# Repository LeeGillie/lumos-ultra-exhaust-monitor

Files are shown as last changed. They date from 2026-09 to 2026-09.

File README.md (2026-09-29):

# Lumos Ultra Exhaust Monitor (LumosAir)

Cheap, fully local airflow monitoring for a laser-engraver exhaust. Two identical boxes â€” an ESP32 running MicroPython, pressure sensors and a 2" colour display â€” feed a Windows app. The app shows live CFM and duct air speeds, sets or recommends the fan level, and diagnoses problems:

- a clogged or kinked duct
- leaking joints
- a leaking dust bin
- a clogged pitot tube
- a blocked outside vent
- a laser enclosure that isn't under enough suction

It was built for a **WeCreat Lumos Ultra** (fiber/UV) venting through an **AC Infinity CLOUDLINE S6**. Everything, including the duct path, fan curve and sensor map, is set in a JSON file, so it adapts to other lasers and fans.

The exhaust run itself is ordinary 4" and 6" **flexible** duct and stays that way. The one exception is a 5 ft **rigid 4" measuring spool** holding a Dwyer 166-6-CF pitot-static probe: flex duct has corrugations, a vague inside diameter and a centreline that shifts when the hose moves, so the flow measurement everything else is checked against gets one stable, known-geometry station. [DESIGN.md Â§2â€“3](docs/DESIGN.md) covers the spool, the probe and the traverse.

**▶ Watch the 2-minute intro on YouTube:**

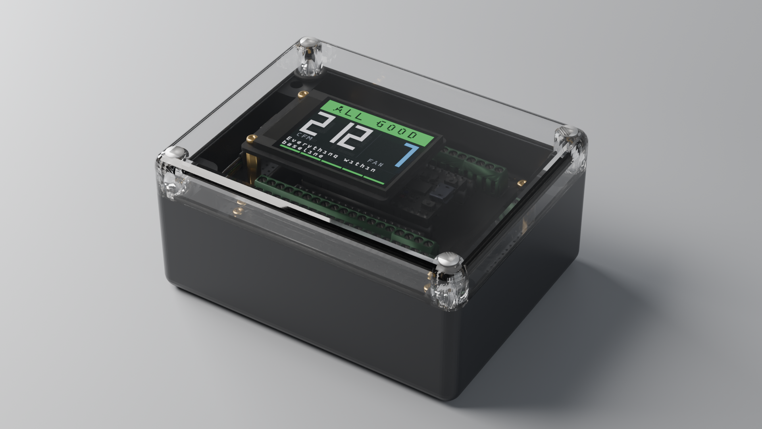
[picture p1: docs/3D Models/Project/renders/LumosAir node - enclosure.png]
LumosAir intro video - click to play on YouTube (https://youtu.be/tQAgUggGCig)


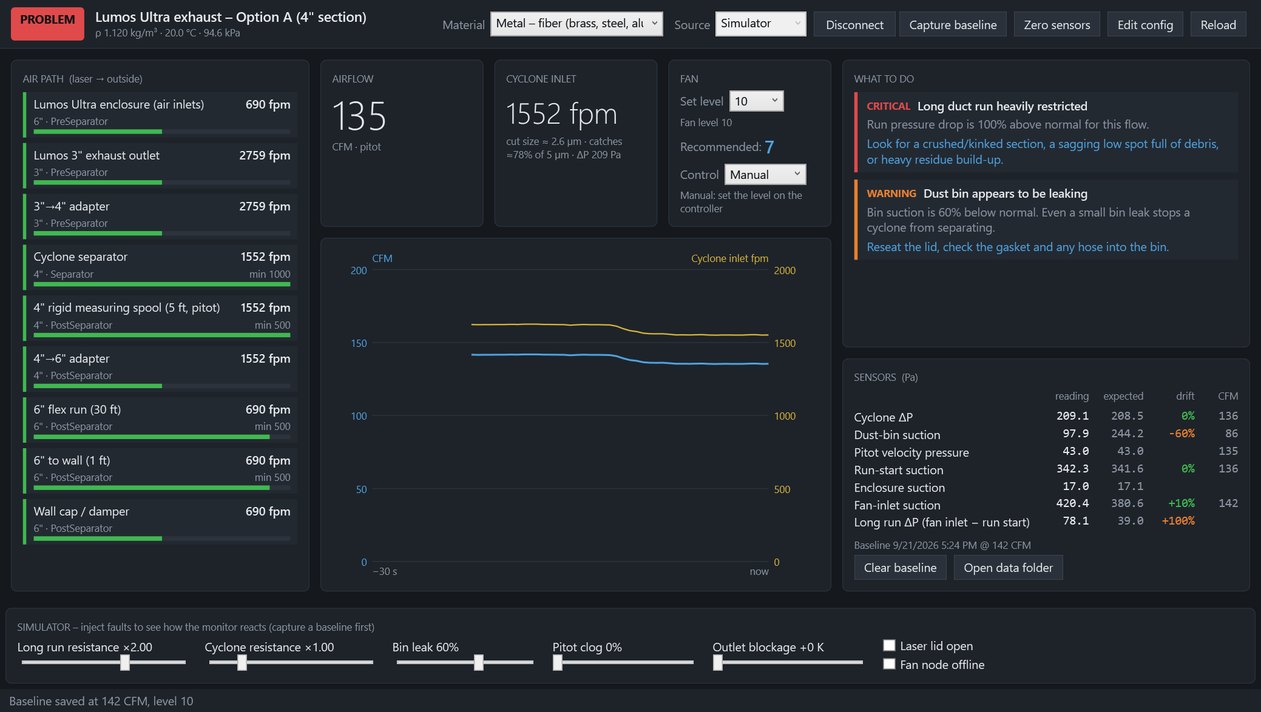
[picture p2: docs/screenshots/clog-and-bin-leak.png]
LumosAir detecting a clogged duct run and a leaking dust bin


---

## Why this is being built *before* the cyclone separator

Deep brass engraving produces real, heavy metal particulate, not just smoke. A temporary 35 ft exhaust hose came out with a pile of brass in it. The plan is to put a **cyclone separator right at the laser outlet** so the brass drops into a sealed drum before it reaches the long duct and the fan.

Cyclones are finicky. They only separate well within a band of airflow, and they use up a lot of the fan's pressure. Choosing one without measuring is guesswork. **The monitor comes first because it answers the questions that decide which separator to buy.**

1. **How much air does the existing system really move?**
   - The S6 is rated 425 CFM, but that is with nothing attached.
   - With the Lumos outlet, adapters, 30 ft of flex and a wall cap, the real figure is much lower.
   - The monitor measures it at every fan level.
2. **Can the fan drive a given cyclone?**
   - The popular 3" steel Dust Deputy needs at least 200 CFM. The physics model estimates that would take roughly 3.4â€“9 inWC across the cyclone alone.
   - The S6 makes about 2 inWC with no airflow at all. The model predicts only 80â€“120 CFM with that cyclone.
   - Once the real fan curve is measured, `lumosair model` gives a measured-model answer for any candidate cyclone before you spend ~$400. See [DESIGN.md Â§1](docs/DESIGN.md#1-key-findings-read-this-first).
3. **Is brass settling in the duct right now?**
   - Air speed in each section is compared with the speed needed to keep metal particles airborne (~3,500 fpm).
   - Modelled as it stands today (`lumosair init --option C`), the system moves about 200 CFM at level 10: ~2,300 fpm in the 4" section and ~1,020 fpm in the 6" run. Both are below what brass needs, so the duct is currently acting as the separator â€” which matches the brass found in the old hose.
   - No fan level fixes that, which is the argument for a separator at the laser rather than more fan speed.
4. **Once a separator is installed, is it working?**
   - The monitor tracks cyclone pressure drop, dust-bin suction (a leaking bin stops separation), inlet velocity and estimated cut size.
   - It compares them all against a "known good" baseline.

In short: **measure first, then size the separator to the air you actually have**, and keep the same sensors in place to watch it afterwards.

---

## Screenshots

These come from the built-in simulator (`LumosAir.exe --selftest out.png --scenario <name>`), so you can explore the app before any hardware exists.

**The system as it stands today (Option C, no separator).** Every duct is on the dirty side, and none of them is fast enough to carry brass â€” no fan level fixes it, which is the case for a separator at the laser:

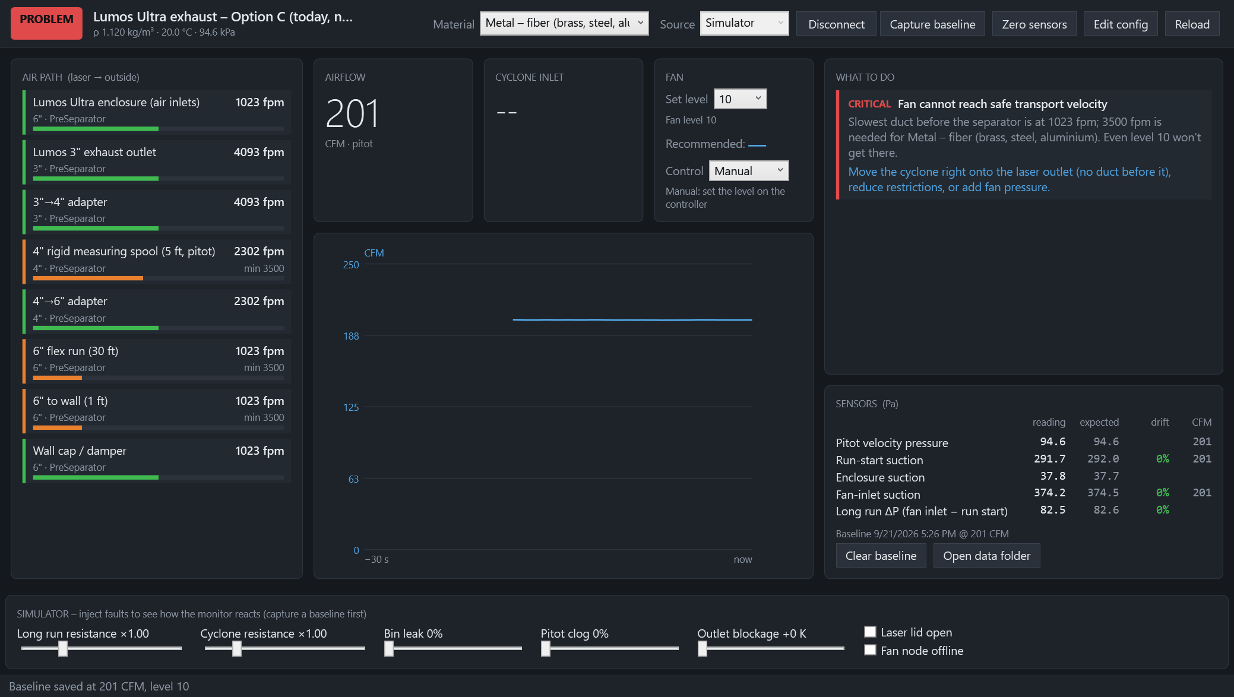
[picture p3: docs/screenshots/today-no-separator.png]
Today, no separator


| Healthy system (Option A, with a separator) | Fan turned down too far |
|---|---|
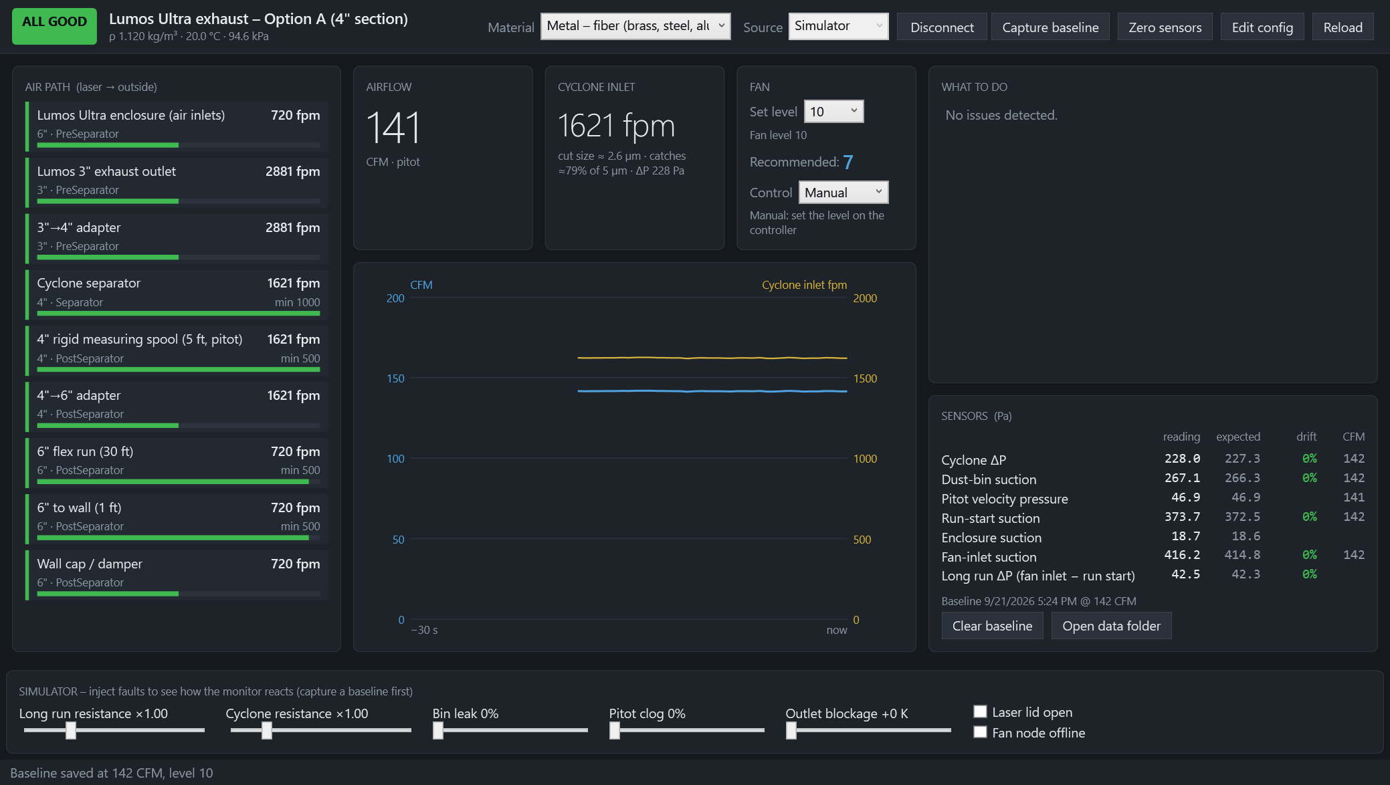
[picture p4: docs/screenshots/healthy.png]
healthy
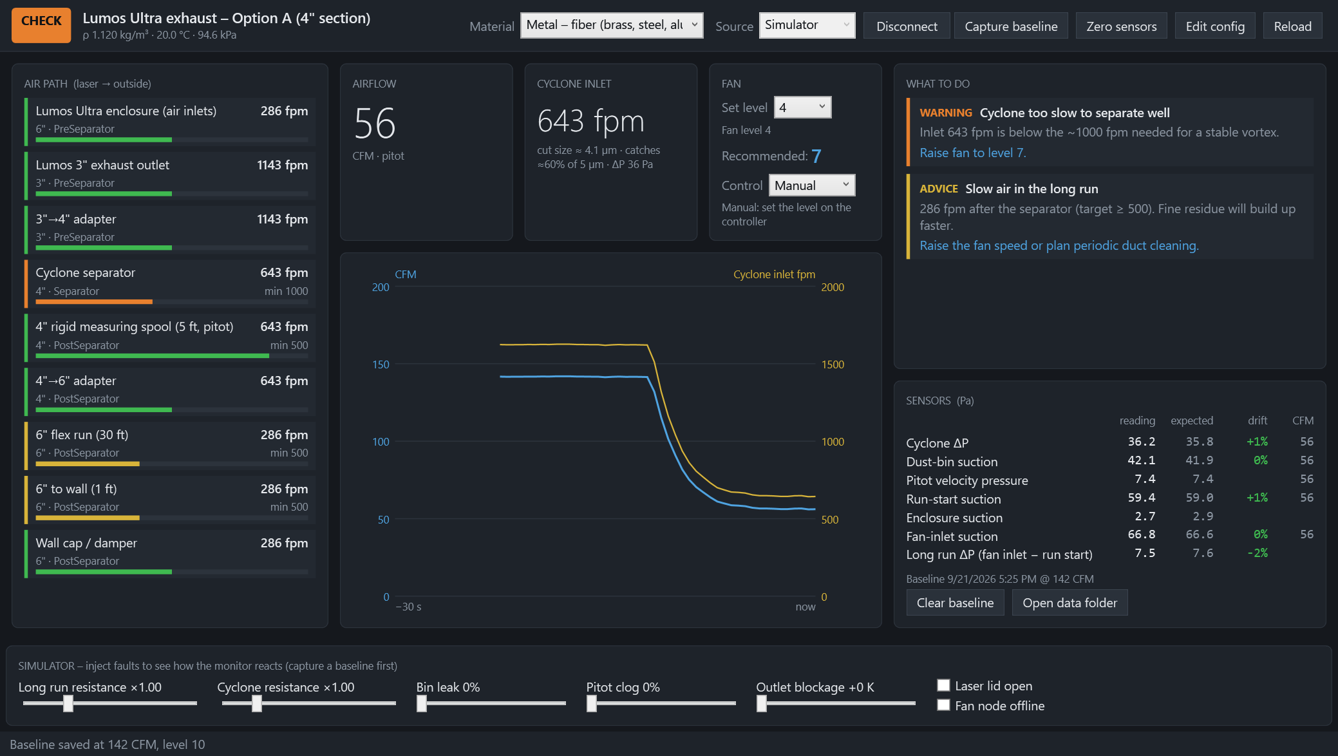
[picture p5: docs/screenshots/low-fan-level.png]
low fan
|  |  |
| **Clogged pitot tube** (app switches to the other sensors) | **Blocked outside vent / damper** |
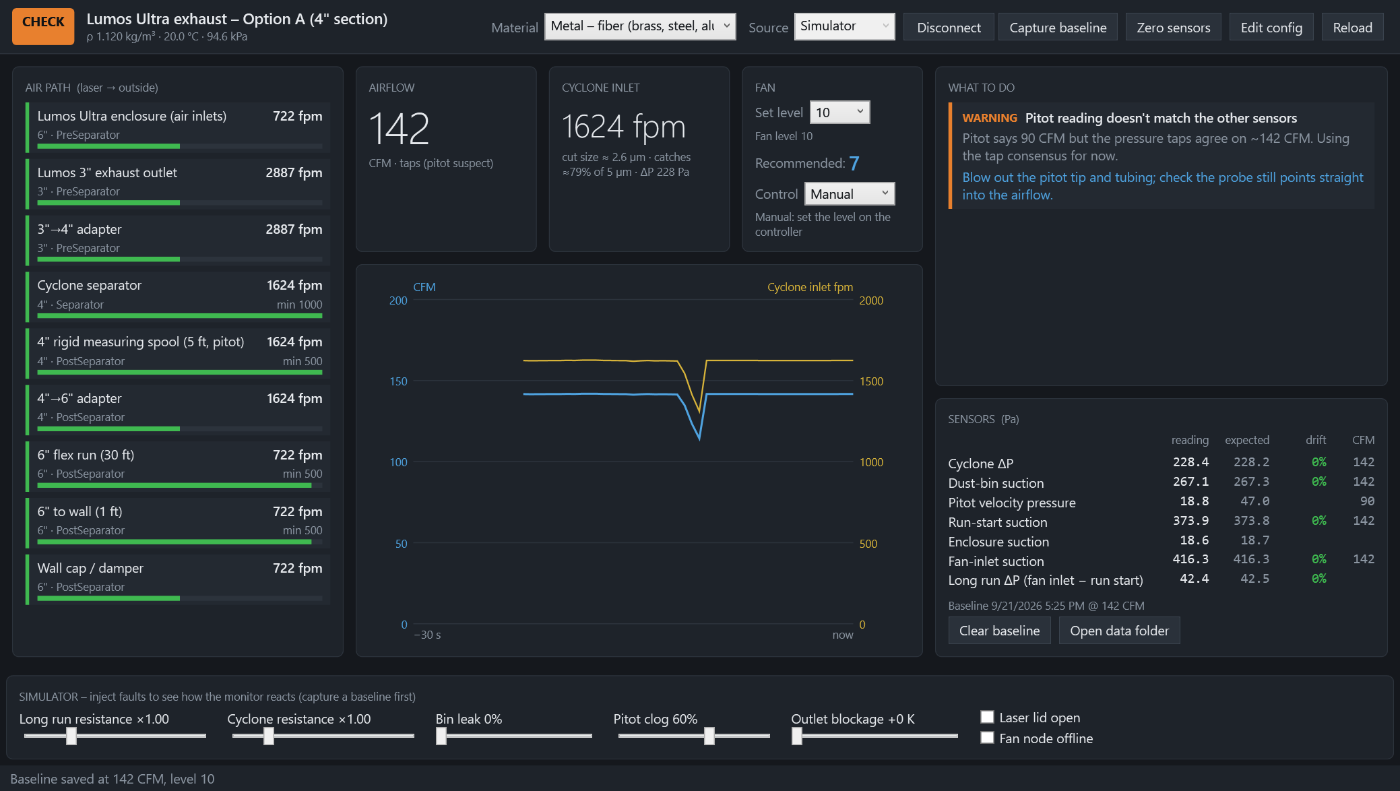
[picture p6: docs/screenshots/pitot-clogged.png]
pitot
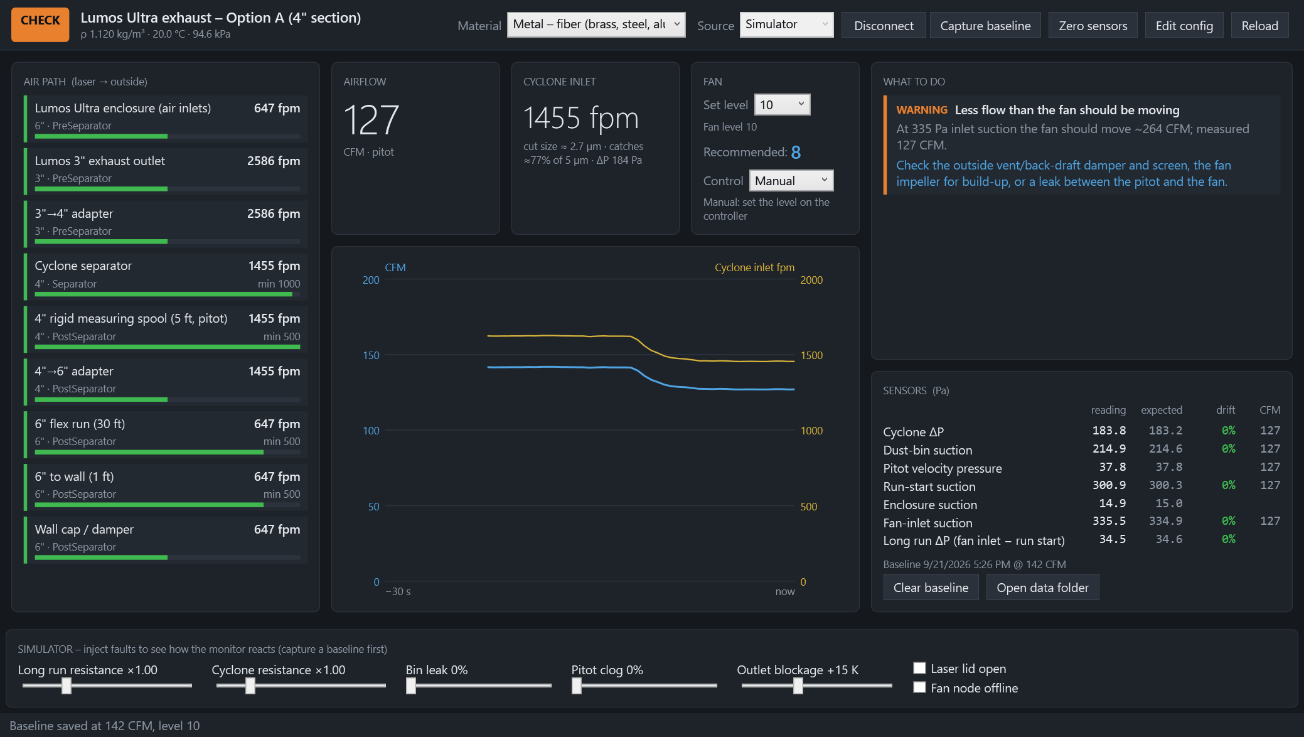
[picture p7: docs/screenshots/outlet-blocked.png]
outlet
|  |  |

System layout and sensor taps:

System diagram

---

## Cost per sensor unit

Approximate prices as of September 2026; check before ordering. The full list, with
sourcing, part numbers, dimensions and datasheet links, is in
[`docs/BOM.xlsx`](docs/BOM.xlsx).

### Per measurement channel

| Channel type | Parts | Approx. cost |
|---|---|---|
| **Precision differential channel** (cyclone Î”P, enclosure) | Sensirion SDP810-500Pa + tubing + 2 wall taps | **$38â€“55** |
| **Pitot flow channel** (CFM) | SDP810-500Pa + Dwyer 166-6-CF pitot-static probe + 1/8" FNPT boss + tubing/adapters | **$210â€“295** |
| **High-suction static channel** (bin, run start, fan inlet) | CFSensor XGZP6897D Â±1 kPa + tubing + wall tap | **$11â€“18** |
| Air-density channel (optional) | BME280 breakout | $5â€“10 |
| **Box** (either node) | Hammond 1554F2GYCL + 2.0" ST7789 display + 8 bulkheads + elbows + button + gland + PCB-A/PCB-B + standoffs | **$90â€“125** |

### Per node

| Node | Contents | Approx. cost |
|---|---|---|
| **Laser node** | ESP32, TCA9548A mux, BME280, 3Ã— SDP810, 2Ã— XGZP6897D, Dwyer pitot + boss, tubing, taps, box + display | **$415â€“580** |
| **Fan node** | ESP32, 1Ã— XGZP6897D, tap, box + display | **$110â€“155** |
| **Complete system** (excluding the separator) | both nodes + the 5 ft rigid 4" measuring spool | **â‰ˆ $550â€“750** |
| **Measure-first starter kit** | fan node + an ESP32 with only the pitot channel and the rigid spool | **â‰ˆ $385â€“500** |

The Dwyer 166-6-CF pitot ($160â€“220 new) is most of the difference. It earns its place: its ASHRAE tip needs no calibration (coefficient 1.000), and at 1/8" it is one of the few probes Dwyer rates for a duct as small as 4". A generic probe is cheaper but has an unknown coefficient, so it has to be calibrated against something else.

---

## The boxes

Both nodes are the **same box, built the same** â€” a Hammond 1554F2GYCL, 120 Ã— 90 Ã—
60.5 mm with a clear lid, the same two boards and the same sensors in each. Only
what you connect outside differs, and each box plugs the bulkheads its location
doesn't use, so either box can serve either position.

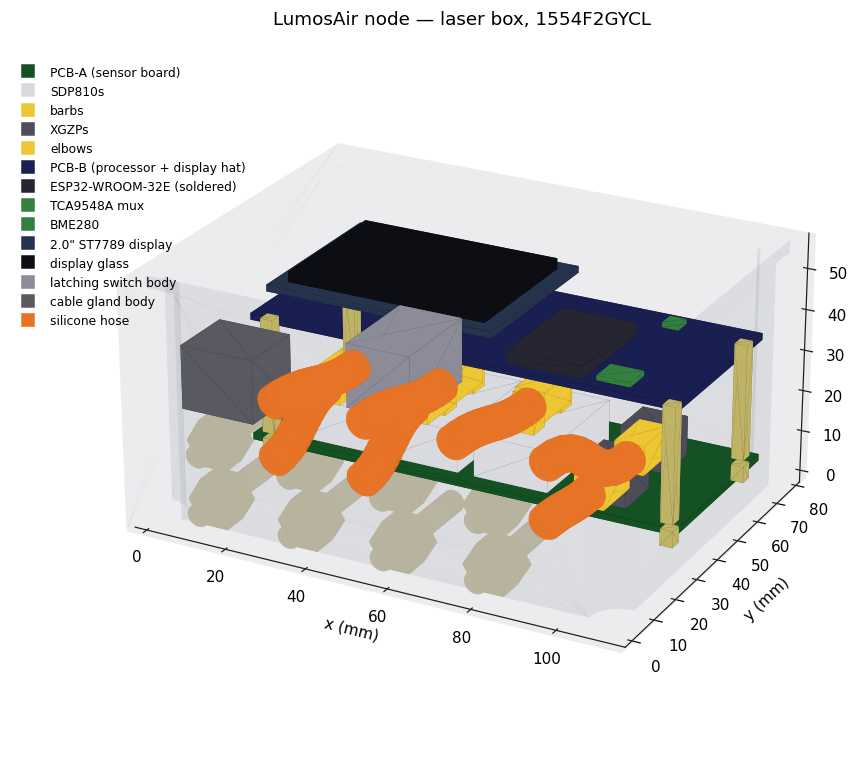
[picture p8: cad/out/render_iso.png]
Enclosure fitment


Inside, it's two boards. **PCB-A** screws to the floor and carries everything that
needs a hose â€” three SDP810s and two XGZP6897Ds, all with their ports facing up.
Spacers carry **PCB-B** above the hose runs with the ESP32, the multiplexer and the
display, which reads up through the clear lid, so there is no cut-out and the box
stays sealed against the dust it's there to monitor.

The eight hoses are modelled as real tubing, because they are what sets the size of
the box. Each SDP810 is turned 90Â° so its barbs line up behind one column of ports,
and a push-on 90Â° elbow turns each hose to point at the wall â€” from there it's a
20â€“45 mm run with a 13 mm minimum bend radius.

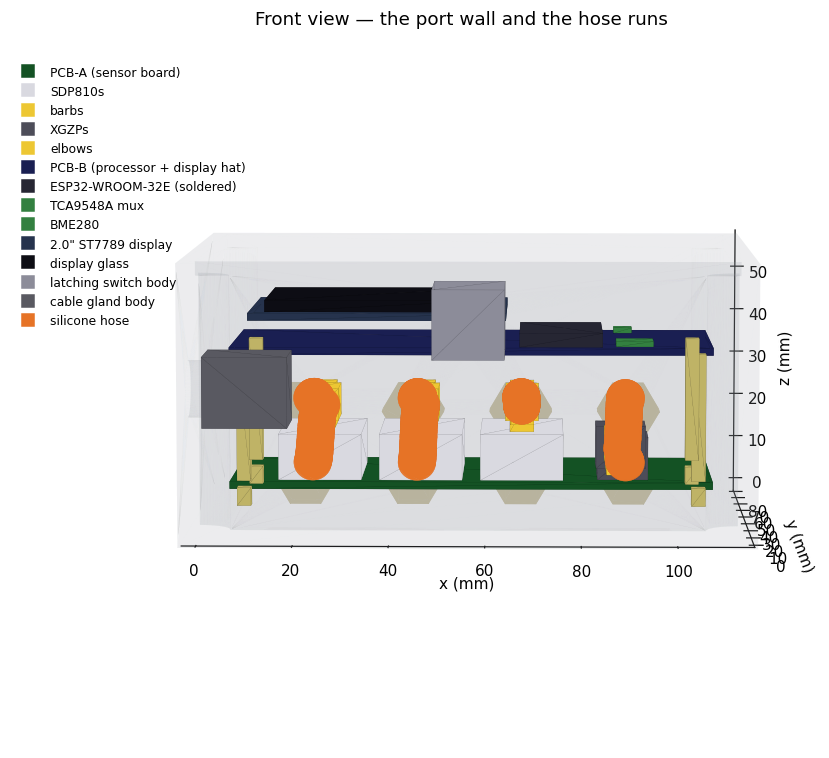
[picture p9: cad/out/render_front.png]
Hose runs


Without those elbows a hose leaves the barb pointing straight up and has to climb a
full bend radius before it can enter a wall port, which adds 25 mm to the box.
`python cad/enclosure.py --compare` prints the case both ways.

A Ã˜12 mm illuminated latching button sits on the same front panel: power switch and
power-on indicator in one hole. The panel artwork, the 1:1 drill template and the
KiCad board outlines all come out of the same script, so a moved port moves its
hole, its label and its PCB mounting hole together â€” see [`cad/`](cad/).

Front panel artwork

The box screen shows the status colour, system CFM, fan level and mode, the top
finding, and every channel on that node â€” and keeps showing live pressures if the PC
app isn't running.

## Fan control: automatic or manual

The app's fan card has a **Control** selector:

- **Manual** â€” it recommends a level and you set the dial; nothing is ever sent.
- **Auto** â€” it sends the level to the fan node. Raising speed happens immediately
  (and a critical finding pins the fan at maximum); easing back only happens after
  the lower recommendation has held for the dwell time, so the fan doesn't hunt.

The fan node's output pin stays disabled until you verify the CLOUDLINE UIS pinout
yourself â€” until then Auto still works as an advisory, on screen and on the box.

## Repository layout

```
cad/         parametric enclosure model (CadQuery): fitment, hose routing,
             panel artwork, KiCad board outlines, STEP/STL/renders
docs/        DESIGN.md (start here), BOM.xlsx, system diagram, screenshots, model output
firmware/micropython/   ESP32 node firmware: sensors, display, Wi-Fi, OTA
app/
  src/LumosAir.Core      physics model, diagnostics, UDP / MQTT / simulator (no NuGet dependencies)
  src/LumosAir.Desktop   WPF monitor app
  src/LumosAir.Cli       `lumosair` CLI: model / simulate / listen
  tests/LumosAir.Tests   dependency-free test runner (41 tests)
  config/                sample system.json (Option A / B, and C = today's system)
```

## Desktop app (Windows, .NET 9)

```powershell
cd app
dotnet run --project src/LumosAir.Desktop                       # the monitor
dotnet run --project tests/LumosAir.Tests                       # tests
dotnet run --project src/LumosAir.Cli -- model --option C        # the system as it is today
dotnet run --project src/LumosAir.Cli -- model --need-cfm 200   # "can my fan do this?"
```

- **First run:** the app writes `%APPDATA%\LumosAir\system.json`. Use **Edit config**, then **Reload**. Start it with `--config path\to\system.json` to use a different one (e.g. `app/config/system.optionC.json`).
- **No hardware yet:** set **Source** to **Simulator**, click **Connect**, then **Capture baseline**, and use the sliders to inject faults.
- **Real nodes:** use **Udp** (no setup needed) or **Mqtt** (e.g. the Home Assistant Mosquitto add-on). Set **Set level** to match the fan controller.
- **Logs:** a CSV row is written to `%APPDATA%\LumosAir\` every 5 s.
- **Other SDKs:** add `-p:AppTfm=net8.0` or `-p:AppTfm=net10.0`.

## Firmware (MicroPython on ESP32)

Developed in VS Code with the MicroPico extension â€” full details in
[`firmware/micropython/README.md`](firmware/micropython/README.md).

1. Flash MicroPython once over USB (`esptool`).
2. Copy `config_example.py` to `config.py`: Wi-Fi, node id, channel map, pins.
3. Upload with MicroPico or `mpremote fs cp -r lib : && mpremote fs cp main.py config.py :`.

After that the boxes update over Wi-Fi â€” no cable, no taking them off the duct:

```
python tools/serve_update.py               # on the PC
python tools/send_command.py laser update  # or the app
```

The node fetches a manifest, downloads only the files whose SHA-256 changed, and
reboots. It reads the sensors through a TCA9548A multiplexer, publishes JSON over
UDP and/or MQTT, drives the display, and accepts `zero`, `clear_zero`, `set_level`,
`info`, `update` and `reboot`.

Host tests (no hardware needed): `python firmware/micropython/tests/test_firmware.py` â€” 31 checks.

### Telemetry format

UDP port 47810, or MQTT topic `lumosair/<node>/telemetry`:

```json
{"node":"laser","seq":12,"up":3456,"rssi":-61,
 "ch":{"cyc_dp":{"pa":212.4,"t":24.1,"ok":true},"pitot":{"pa":46.8,"t":24.0,"ok":true}},
 "env":{"t":23.9,"rh":41.0,"p":94412}}
```

Commands go to UDP port 47811 or `lumosair/<node>/cmd`, e.g. `{"cmd":"zero"}`.

## Status

- **Working and tested:** the physics model, the diagnostics (all 9 simulated faults detected, no false alarms), automatic fan control, the desktop app and the CLI. 41 app tests plus 31 firmware tests, all on the PC.
- **Firmware:** MicroPython, driver maths and payloads unit-tested on the PC, not yet run on hardware.
- **Fan output pin:** disabled until the CLOUDLINE UIS pinout is verified; Auto mode is advisory until then.
- **Needs calibration:** the fan curve, cyclone loss coefficient and pitot profile factor are estimates until they are measured on the real system. [DESIGN.md Â§6](docs/DESIGN.md#6-commissioning) walks through calibrating them.

## Safety note

Brass dust contains copper and zinc. Don't blow accumulated dust out of ducts with compressed air. Keep the dirty side of the system short, smooth, metal and grounded. This project monitors airflow; it is not a certified safety device.

## License

MIT. See [LICENSE](LICENSE).

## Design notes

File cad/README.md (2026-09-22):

# Enclosure fitment model

Both nodes use the **same box, built the same** — same eight bulkheads, same two
boards, same sensors. Each just plugs the ports its location doesn't use. The model
is a script, so moving a part is a one-line change and the drawings, the STEP file,
the panel artwork, the PCB outlines and the clearance report all follow.

```
pip install cadquery matplotlib
python cad/enclosure.py                     # STEP + STL + fitment report (picks the box)
python cad/enclosure.py --populate fan      # the fan box's population
python cad/enclosure.py --compare           # which box fits, and why
python cad/artwork.py                       # 1:1 panel artwork + KiCad board outlines
python cad/render.py                        # shaded PNGs for the docs
```

Everything lands in `cad/out/`:

| File | What it's for |
|---|---|
| `lumosair_laser_F_module.step` / `.stl` | open in FreeCAD / Fusion / Blender |
| `render_iso.png`, `render_top.png`, `render_front.png`, `render_side.png` | the pictures in the docs |
| `panel_front_laser.svg`, `panel_front_fan.svg` | 1:1 laser-marking artwork for the port face |
| `panel_end.svg` | the end wall (cable gland) |
| `drill_template_front.svg` | 1:1 hole pattern with crosshairs |
| `pcb_a_outline.dxf`, `pcb_b_outline.dxf` | board edge + M3 mounting holes, for KiCad |
| `fitment_report_laser.txt` | part positions, hose lengths, bend radii, clearances, collisions |

Isometric

## The box

Hammond **1554F2GYCL**: 120 × 90 × 60.5 mm outside, ~113 × 79 × 54.5 inside, 3 mm
walls, **clear polycarbonate lid**. The clear lid is why the display needs no
cut-out — it sits on standoffs facing up and reads through the lid, which keeps the
box sealed.

Only the 1554H has a confirmed drawing in `docs/datasheets/`; the others use the
same wall and flange offsets, so treat their insides as ±1 mm and check before you
drill.

## The stack

```
floor ── 4 mm standoffs ── PCB-A   every part that needs a hose, ports facing UP
                             │     hose zone: eight silicone runs, 6 → 31 mm
      ── 28 mm spacers ──── PCB-B   ESP32 + mux + BME280
                             │
      ── 6 mm standoffs ─── display reading up through the clear lid
                                    ~9 mm spare under the lid
```

| Board | Size | Carries |
|---|---|---|
| PCB-A | 105 × 41 mm | 3 × SDP810 (turned 90°), 2 × XGZP6897D soldered direct |
| PCB-B | 105 × 41 mm | ESP32-WROOM-32E, TCA9548A, BME280, the display on standoffs |

Both boards share an outline and a mounting pattern, so the spacers are one straight
vertical stack — see the two DXFs.

## How the hoses connect

Each SDP810 is turned 90° so its two barbs line up behind one column of bulkheads. A
**push-on 90° barbed elbow** on each barb turns the hose to point at the wall, and
from there it's a short, nearly straight run to its bulkhead.

That elbow is what makes the small box possible. `--compare`:

| fittings | tallest item | headroom in the 1554F | tightest bend |
|---|---|---|---|
| 90° elbows | 51.5 mm | 3.0 mm | 13.1 mm — fits |
| straight onto the barb | 65.1 mm | −10.6 mm | 3.3 mm — kinks |

A hose leaving a barb straight up has to climb a full bend radius before it can turn
into a wall port, which pushes the ports 25 mm higher and the lid with them.

Which sensor gets which hole is chosen by the model, not fixed: it tries every
assignment and keeps the one with the least sideways and vertical offset. The
labels follow, which is why the panel artwork is generated rather than drawn.

Front view

## Port assignments

Eight Ø8 mm holes, two rows of four, 22 mm pitch, rows at z = 13 and 27 mm.

| Column | Lower row | Upper row |
|---|---|---|
| 1 | CYC + | CYC − |
| 2 | PITOT T | PITOT S |
| 3 | VENT | ENCL |
| 4 | BIN | RUN |

Both boxes are drilled and populated identically; each plugs the bulkheads its
location doesn't use. A node works out which it is from what's connected outside —
see [DESIGN.md §6a](../docs/DESIGN.md).

**VENT** is an open port that keeps the box interior at room pressure. That's the
reference side for the bin, run and enclosure channels, so each of those needs only
one hose.

A Ø12 mm illuminated latching push button sits centred on the same panel above the
hoses — power switch and power-on indicator in one hole. The Ø12.5 mm cable gland
is in the left end wall.

## Marking and drilling

`artwork.py` writes 1:1 SVG at true millimetre scale. Red (`#ff0000`) is
cut/drill, black is engrave; most laser software maps colour to operation.

Panel

`drill_template_front.svg` is the same holes with crosshairs and a 100 mm check bar
— print it, check the bar, tape it on, centre-punch.

## Checking a change

`fitment_report_laser.txt` lists every part's extent, the headroom, each hose's
length and bend radius, and any collisions. `enclosure.py` exits non-zero when
something doesn't fit, so it can sit in a build script.

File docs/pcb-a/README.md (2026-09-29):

# PCB-A — the sensor board

Everything that needs a hose, plus the I²C mux, the air sensor and the fan interface,
on one board under the ESP32. Drawn to be entered in Proteus (or any EDA tool).

- **[pcb_a_schematic.svg](pcb_a_schematic.svg)** — the schematic, net-label style: pins
  with the same net name are connected.
- **[pcb_a_netlist.md](pcb_a_netlist.md)** — every net and every pin, for checking the
  layout against.

Both are generated by [`cad/schematic.py`](../../cad/schematic.py) from one parts table,
so they can't disagree. Change the table and re-run it rather than editing either file.

PCB-A schematic

## Blocks

| Block | Parts | What it does |
|---|---|---|
| Link to the ESP32 | J2 (8-pin) | +5V, GND, 3V3, SDA (GPIO21), SCL (GPIO22), FAN_SENSE (GPIO33), FAN_CTRL (GPIO25) |
| I²C mux | U6 TCA9548A breakout, C3 | The pressure sensors share addresses (SDP810 = 0x25, XGZP = 0x6D), so each gets its own channel. A0–A2 low = 0x70. |
| Pressure | U1–U3 SDP810, U4–U5 XGZP6897D, R10–R19, C4–C8 | One sensor per channel, pull-ups per channel, 100 nF at every sensor. |
| Air | U7 GY-BME280 | On the main bus (0x76), not behind the mux. Density correction for CFM. |
| XGZP supply | JP1 | See below — the one thing to set when the sensors arrive. |
| Fan sense | J3, R1, D2, OK1, R2, C9 | The fan lead's own rail lights OK1, which pulls FAN_SENSE low: "this is the fan box" (DESIGN 6a, step 1). Fully isolated. |
| Fan control | R3, OK2 — **do not fit** | Footprints only, until the UIS pinout and signalling are verified. `FAN_OUTPUT_ENABLED` stays False. |
| 5 V input | J1, F1, D1, C1 | Only if power comes in on the 2-wire USB-C socket rather than through the ESP32 board's own USB port. The TVS clamps and the PTC trips if the 10 V fan lead is ever plugged into the power socket. |

## Channel map — identical on both boxes

> **Rev B (milled copper-clad board, Sept 2026) changes this map** to make the single-sided routing work: ch0 pitot, ch1 run_in (fan box: fan_in), ch2 bin, ch3 cyc_dp, ch4 encl. The XGZPs also run from 3.3 V (JP1 removed) and have port 2 on the hose (sign -1). See [cnc/README_CNC.md](cnc/README_CNC.md). The table below is the original rev A map.

| Mux ch | Part | Laser box | Fan box |
|---|---|---|---|
| 0 | U1 SDP810 | `cyc_dp` | — |
| 1 | U4 XGZP | `bin` | — |
| 2 | U2 SDP810 | `pitot` | — |
| 3 | U5 XGZP | `run_in` | **`fan_in`** |
| 4 | U3 SDP810 | `encl` | — |
| 5 | J4 (spare) | — | — |

Because both boards are the same, the fan box's `fan_in` has to sit on one of the two
XGZP positions; it takes the RUN one, channel 3. `config_fan.py` still says channel 0
from the bench days — change it to `"mux": 3` when the sensors go in.

## Things to confirm before ordering boards

1. **XGZP6897D supply voltage.** The standard part is **5 V**; the 3.3 V version has
   `33` in its part number. Read the marking on the sensor when it arrives, then set
   **JP1: 1-2 for 3.3 V, 2-3 for 5 V**. JP1 also sets the pull-up voltage on the XGZP
   channels; the TCA9548A passes each channel through at its own voltage, so the ESP32
   still only sees 3.3 V. If the module already has pull-ups, leave R16–R19 off.
2. **XGZP pressure range.** The firmware assumes the ±1 kPa part (`k = 4096`). The range
   is in the part number (`001KPD…` = 1 kPa). A different range needs a different `k`.
3. **Module footprints.** U4/U5 (XGZP modules), U6 (TCA9548A) and U7 (BME280) are
   breakouts; take the pin order and spacing from the boards you have, not from a library.
4. **SDP810 orientation.** Pin 1 is SCL, and Sensirion's table is drawn from the
   **bottom**. Mirror-check the footprint — this is the classic way to reverse a part.
5. **UIS wiring.** J3's four terminals are functions (V+, GND, CTRL, spare), not UIS
   contact numbers. Meter the fan lead first, then land each wire on its function.
   Keep UIS_GND copper apart from board GND; the optocouplers are the only bridge.

## Why these values

- **R1 2.2 k:** about 4 mA through OK1's LED from a 10 V rail, still enough at 5 V.
  D2 stops the LED being reverse-biased if the rail turns out to be the other way round.
- **R2 10 k:** GPIO33 has an internal pull-up, but an external one is predictable. With
  a PC817 (CTR ≥ 50 %) the 4 mA LED current sinks far more than the 0.33 mA R2 passes.
- **R3 330 Ω:** about 6 mA from a GPIO, well inside its limit.
- **4.7 k pull-ups** per channel: the SDP810 has none of its own, and each mux channel is
  a separate bus.
- **3V3 for the SDP810s:** they run from 2.7 to 5.5 V; 3.3 V keeps them on the ESP32's
  logic level with no translation.

## Firmware that follows from this board

- `fan_in` on channel 3 in `config_fan.py` (above).
- A `FAN_SENSE_PIN = 33` setting and the "which box am I" logic that reads it. Not
  written yet — it waits for a board to test on.

## Mounting the display

The SWIFT-LCD-20 has only two holes, both on the connector edge (30 mm apart, 2.5 mm in
from the edge — maker's dimension drawing). Nothing holds the other edge.

**Recommended: hang it from the lid.** Two nylon screws through the clear lid into two
standoffs, into the display's holes, glass facing up against the lid. A strip of 1–2 mm
foam tape between the far edge of the display board and the lid keeps it parallel.

- It reads best: no gap for parallax or reflections between the glass and the lid.
- It takes the display out of the stack, so PCB-A and the ESP32 board have the full
  height of the box.
- The six-wire lead has to reach when the lid is open; the supplied pigtail is long
  enough if it runs along a wall.
- Seal the two lid holes with nylon screws and rubber washers.

**Alternative: a printed cradle** screwed to the ESP32 board's mounting holes, with a
ledge under the far edge of the display. Better if the lid comes off often; more height
used inside the box.

Measure the hole diameter on your display before buying screws (the maker calls it
"LEGO compatible", which may mean Ø4.8 mm rather than M2.5/M3).

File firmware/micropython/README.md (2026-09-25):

# LumosAir node firmware (MicroPython)

Runs on an ESP32-WROOM-32. Both boxes run this same code; `config.py` is the only
difference between them.

```
main.py                 entry point, runs on boot
config_example.py       copy to config.py and edit (git-ignored)
lib/lumosair/
  sensors.py            SDP8xx, XGZP6897D, BME280, TCA9548A
  st7789.py             2.0" 240x320 display driver (stripe buffer + 7-segment)
  display_ui.py         what the box screen shows
  net.py                Wi-Fi, UDP telemetry/commands/status, optional MQTT
  fan.py                fan level output (disabled until the UIS pinout is verified)
  ota.py                pull updates over Wi-Fi
  node.py               sampling loop and command handling
  benchsim.py           bench mode: model-predicted readings when no sensors are wired
tools/upload.py         copy the firmware to a board over USB (mpremote)
tools/serve_update.py   serve this folder to the nodes for OTA
tools/send_command.py   zero / set_level / update / watch telemetry from a PC
tools/simulate_node.py  run a node on the PC and render its screen to a PNG
tests/test_firmware.py  host tests (plain CPython, no hardware)
```

## Set up VS Code

1. `mpremote` does everything from the terminal; the **MicroPico** extension is optional.
2. Flash MicroPython once over USB:
   ```
   pip install esptool mpremote
   esptool --chip esp32 --port COM5 erase-flash
   esptool --chip esp32 --port COM5 write-flash -z 0x1000 ESP32_GENERIC-<version>.bin
   ```
   esptool 5.x spells these with hyphens; the old `erase_flash` / `write_flash`
   are deprecated. Find the port with `python -m serial.tools.list_ports -v`:
   the board shows as a CP210x (VID 10C4) or CH340 (VID 1A86). If nothing new
   appears when you plug it in, suspect a charge-only cable first.
3. Copy `config_example.py` to `config.py`, set your Wi-Fi, node id and channel map.
   On the bench set `WATCHDOG_MS = 0`: once started, the ESP32 watchdog can't be
   stopped, so it resets the board 20 s after you break into the REPL.
4. Upload:
   ```
   python tools/upload.py --port COM5
   ```
   It copies `lib/`, `config.py` and `main.py` (last), skips `__pycache__` and files
   that haven't changed, then resets. In VS Code: *Run Task → device: upload firmware (USB)*.
5. `mpremote connect COM5 repl` (or *device: REPL (USB)*) attaches; Ctrl+C stops
   `main.py`, Ctrl+D soft-reboots and shows the boot log, where each channel should
   print `ok`. Ctrl+] leaves.

## Bench wiring (screw-terminal adapter)

On the bench the DevKit sits in a generic "FOR ESP32 TERMINAL ADAPTER". Its labels
are right, but only under three conditions; each one cost an evening:

- **USB connector at the 5V/CLK end**, antenna at the 3V3/GND end. The vendor's
  product photo shows it rotated 180°. Seated that way, "3V3" is the flash clock,
  the left "GND" is GPIO21 and "P13" is RX: boot loops, I²C timeouts, a dead REPL
  and a reverse-powered display.
- **Wire the screw terminals, never the spare header sockets.** The terminals are
  3.5 mm apart and the sockets 2.54 mm, so a label drifts 1–3 sockets from its pin.
- **Leave SD0–SD3, CND, CLK, P12, TX and RX empty.** "CND" is CMD (GPIO11, a flash
  pin), not ground. P12 high at reset drops the flash to 1.8 V.

The display (NULLLAB SWIFT-LCD-20) — go by the labels at its connector, not by
wire colour; on the supplied pigtail red is CS and blue is power:

| Display | Terminal | GPIO |
|---|---|---|
| V | 5V | — (module has its own 3.3 V regulator) |
| G | GND | — |
| SCL | P14 | 14 (SCK) |
| SDA | P13 | 13 (MOSI) |
| DC | P27 | 27 |
| CS | P15 | 15 |

The sourced write-up is in
[docs/research/ESP32 display wiring verification.md](../../docs/research/ESP32%20display%20wiring%20verification.md).

## Bench mode

With no sensors wired, set `BENCH_SIMULATE = True` in `config.py`. Each channel then
reports what the app's model predicts it reads at the fan level in the app's
status broadcast (`lib/lumosair/benchsim.py`, profile `BENCH_PROFILE` = `A` or
`C`). Telemetry, Wi-Fi, the display and commands all stay real, so the real box,
a simulated fan box (`tools/simulate_node.py --live --node fan --config A`) and the
app with the matching `system.optionA.json` show normal operation end to end.
**Turn it off before a box goes on the duct.**

## Updating over Wi-Fi

Once a box is mounted on the duct, don't take it down for a USB cable:

```
python tools/serve_update.py             # on the PC, in this folder
python tools/send_command.py laser update # or the Update button in the app
```

The node fetches `manifest.json`, downloads only the files whose SHA-256 changed,
writes them and reboots. Set `OTA_URL` in `config.py` to the address the tool prints.

## What the box screen shows

The 2.0" ST7789 is read from across the room, so it shows only what you act on:

- a full-width status band: ALL GOOD / ADVICE / CHECK / PROBLEM, or **NO PC**
  when no status has arrived from the app for 10 s,
- the system airflow in CFM and the fan level, 100 px tall,
- **SET n** in amber under the fan level when the app wants the dial moved,
- the app's top finding in plain words, on two large lines,
- one block per sensor along the bottom: green responding, orange not.

The app sends its status straight to each box it has heard from (a plain
255.255.255.255 broadcast leaves Windows by one adapter only, which on a PC with
Hyper-V or a VPN is often not the LAN).

## Fan control

`fan.py` accepts `{"cmd":"set_level","level":7}` and reports the level in telemetry.
It only drives a pin once you set `FAN_OUTPUT_ENABLED = True` in `config.py`: the
CLOUDLINE UIS pinout is community-reverse-engineered, so check it with a meter
first. Until then the app's Auto mode still works as an advisory — it tells you
(and the box screen) which level to set.

## Running a node without a node

`tools/simulate_node.py` runs the box on your PC and draws what the panel would
show. It is not a mock of the UI: it imports the real `st7789` and `display_ui`
and decodes the SPI command stream the driver emits (CASET / RASET / RAMWR) into
a framebuffer, so the PNG is the panel pixel for pixel — layout bugs included.
Standard library only.

```
python tools/simulate_node.py --window         # a window; arrows walk the screens
python tools/simulate_node.py --live --window  # a live box, on screen
python tools/simulate_node.py                  # every scenario -> out/*.png
python tools/simulate_node.py --live           # headless; one PNG per frame
```

`--window` opens a real window (tkinter, standard library) showing the panel at
2x. Without `--live` it shows one scenario and **Left/Right** walk through all
eight, so you can flick between states and compare layouts; Esc closes it.

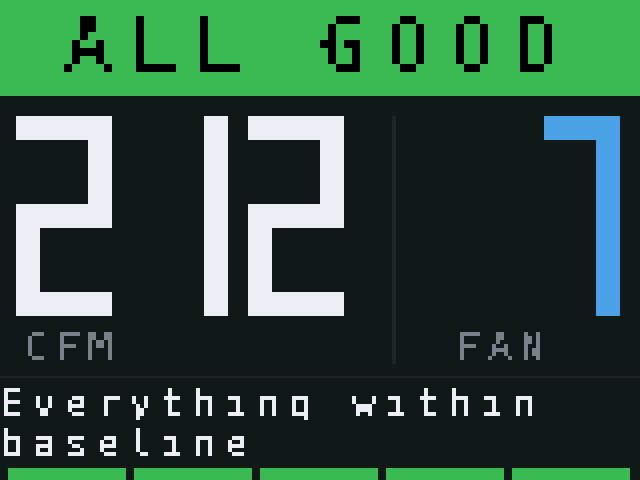
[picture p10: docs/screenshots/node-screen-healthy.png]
The box screen, healthy


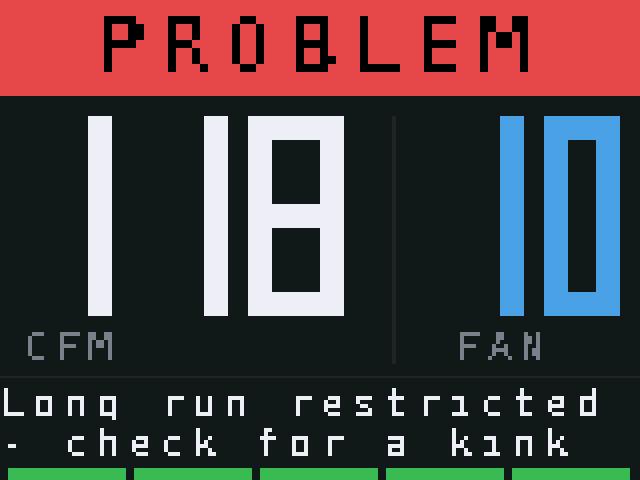
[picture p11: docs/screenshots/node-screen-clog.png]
The box screen, clogged run


Scenarios: `healthy`, `clog`, `binleak`, `pitot`, `slow`, `sensorfault`, `nopc`
(the desktop app isn't running) and `fannode` (the one-channel box).

`--live` makes it a stand-in for a real box: it publishes telemetry on UDP 47810,
accepts commands on 47811, and listens for the app's status broadcast on 47812.
Start it, then run the desktop app with **Source = Udp** and **Connect** — the app
sees a node that isn't there, and the screen reacts to what the app concludes.
Add `--window` to watch it live; without it each frame is written to
`out/screen_live_<node>.png` (written to a temp file and renamed, so a preview
can never catch a half-written frame).

The 8x8 font it uses stands in for MicroPython's built-in one. The cell is the
same fixed 8x8, so anything that fits here fits on the panel; individual glyph
shapes differ slightly.

**This is how the seven-segment bug was found** — every digit with an asymmetric
shape (3, 4, 6, 7, 9) rendered mirrored, because `_DIGITS` is written LSB-first
and `seg7` was reading it MSB-first. Nothing caught it, because the old test only
asserted that `seg7` wrote *some* pixels. There are now eight checks on which
bars each digit lights.

## Host tests

```
python tests/test_firmware.py
```

51 checks covering the CRC and scaling maths, the multiplexer, channel averaging
and zero offsets, the fan level mapping, the telemetry payload the PC app parses,
the display driver — which segments each digit lights, and that fills and text
reach the panel in the same byte order — and bench mode. Only the pin wiggling
needs hardware.

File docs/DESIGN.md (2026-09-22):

# LumosAir – Exhaust Airflow Monitor for the Lumos Ultra

*Design document, rev 4 — September 2026* (rev 2: named the pitot probe, the rigid measuring spool vs. flex duct distinction, two-axis traverse, Option C. rev 3: identical enclosures with a fitment model, a display in each box, MicroPython firmware, and automatic fan control with manual override. rev 4: stacked two-board enclosure with the hose routing modelled, 90° elbows at the sensors, a smaller 120 × 90 mm box, a front-panel power button, and generated panel artwork and PCB outlines)

LumosAir is a low-cost, fully local system that measures airflow along the Lumos Ultra exhaust path and tells you when to raise the fan speed. It also flags a clogged duct, a leaking joint, a failing separator or a leaking dust bin. It has three parts:

1. **Sensor nodes**: two identical boxes, each an ESP32 running MicroPython with differential-pressure sensors on small tap holes, and a 2" colour display showing live readings.
2. **Transport**: UDP broadcast on the LAN (no setup), or MQTT so the readings can also go into Home Assistant. The PC broadcasts a status summary back, which is what the box displays show.
3. **LumosAir desktop app** (.NET / WPF). It holds a physics model of the duct path, shows live CFM and air speeds, diagnoses problems, and can drive the fan automatically or leave it to you. A built-in simulator lets you test all of this before any hardware exists.

System diagram

---

## 1. Key findings (read this first)

The numbers below come from the model in `app/` (`lumosair model …`). Two inputs are **estimates**: the S6 fan curve (built from AC Infinity's published 425 CFM / 503 Pa end points) and the internal resistance of the Lumos. Treat the numbers as ±25 % until the sensors are installed and calibrated. The conclusions do not change within that range.

1. **The 3" steel Dust Deputy and the CLOUDLINE S6 are not a good match.** Oneida lists a **minimum of 200 CFM** for the Heavy-Duty 3" Dust Deputy. Pushing 200 CFM through a 2-7/8" cyclone inlet takes roughly **3.4–9 inWC across the cyclone alone** (range covers typical cyclone loss coefficients K = 3–8). The S6 tops out at about **2 inWC (503 Pa) with no airflow at all**. With that cyclone installed, the model predicts **80–120 CFM** at speed 10, well below Oneida's minimum. Getting 200 CFM through that cyclone would take a shop-vac or dust-collector class blower, not an inline fan.
   ```
   lumosair model --cyc-inlet 2.875 --cyc-k 4 --need-cfm 200
   → system needs 1525 Pa (6.1 inWC); fan gives 392 Pa → NOT ENOUGH
   ```
2. **Brass is much easier to separate than wood dust, so a low-velocity cyclone can still work well.** Cyclone cut size scales with 1/√(particle density), and brass is about 8.5 g/cm³. Even at a modest ~1,600 fpm inlet speed, a cyclone with a 4" inlet has an estimated 50 % cut size near **2.6 µm for brass** (7.5 µm for wood char). The better fit is a **larger-inlet, lower-pressure-drop cyclone** that the S6 can actually drive. Manufacturers' minimum-CFM ratings are written for wood dust; the monitor measures whether your cyclone is actually working.
3. **Put nothing but a short smooth adapter between the Lumos and the cyclone.** The 3" outlet runs at roughly 2,000–2,900 fpm with the S6. That is below the ~3,500 fpm needed to keep brass airborne. The only safe amount of duct before the separator is almost none, which matches the pile of brass found inside the old 35 ft temporary hose.
4. **After the cyclone, the 6" flex run is not the bottleneck.** It costs about 40 Pa when the flex is pulled taut and about 60 Pa if it sags (friction multiplier 1.5 → 4.0), which moves the operating point by only 143 → 139 CFM. The Lumos 3" outlet, the 3"→4" adapter and the cyclone cost about 320 Pa between them. Replacing the 6" flex with smooth pipe gains little; the cyclone choice matters far more.
5. **Measure flow in a rigid 4" spool (Option A), not in 6" (Option B), and never in flex.** At the same flow, a pitot tube in 4" pipe sees about 47 Pa versus about 10 Pa in 6", which gives five times the signal for the same sensor.
6. **Fan-inlet suction runs around 400 Pa**, close to the full scale of a 500 Pa sensor. Use ±1 kPa sensors for the high-suction taps (fan inlet, run start and bin) so that a clog does not push them off scale.

### Estimated operating points (Option A, generic 4" inlet cyclone, K = 6)

| S6 level | CFM | 3" outlet fpm | Cyclone inlet fpm | 4" fpm | 6" fpm | Cyclone ΔP | d50 brass | d50 wood |
|---|---|---|---|---|---|---|---|---|
| 4 | 56 | 1,143 | 643 | 643 | 286 | 36 Pa | 4.1 µm | 12.0 µm |
| 6 | 85 | 1,723 | 969 | 969 | 431 | 81 Pa | 3.3 µm | 9.8 µm |
| 8 | 113 | 2,303 | 1,295 | 1,295 | 576 | 146 Pa | 2.9 µm | 8.4 µm |
| 10 | 142 | 2,884 | 1,622 | 1,622 | 721 | 228 Pa | 2.6 µm | 7.5 µm |

The full tables are in `model-optionA.txt`, `model-optionB.txt` and `model-optionC.txt`.

### Today's system (Option C, no separator): the brass has nowhere to drop out

Modelled as it stands now — 3" outlet, 3"→4", ~5 ft of 4", 4"→6", 30 ft of 6" flex, S6, wall cap:

| S6 level | CFM | 3" outlet fpm | 4" fpm | 6" fpm |
|---|---|---|---|---|
| 6 | 120 | 2,437 | 1,371 | 609 |
| 8 | 160 | 3,264 | 1,836 | 816 |
| 10 | 201 | 4,092 | 2,302 | 1,023 |

Brass needs roughly 3,500 fpm to stay airborne. Even at level 10 the 4" section is at ~2,300 fpm and the 6" run at ~1,020 fpm, so **the duct itself is acting as the separator** — which is exactly what the brass pile in the old temporary hose showed. The monitor reports this as "fan cannot reach safe transport velocity", and no fan level fixes it. The fix is a separator at the laser, not more fan speed.

### Why the monitor is built before the separator

The separator is the expensive, hard-to-reverse decision, and every number that decides it (real CFM, available fan pressure, cyclone pressure drop) is currently an estimate. The sensors turn those estimates into measurements. They then stay in place to verify the separator once it is installed: cut size, bin leaks, and whether brass still reaches the long run.

Install the sensor nodes on the **current** system first (the pitot section and the fan-inlet tap are enough). Then:

- Record CFM at every S6 level.
- Replace the estimated fan curve in `system.json` with your measured one.
- Run `lumosair model --config system.json --cyc-inlet <in> --cyc-k <K> --need-cfm <x>` for each candidate cyclone.

The flow you would get with each cyclone becomes a measured-model prediction instead of a guess.

---

## 2. Physical layout

```
Lumos Ultra ─3"─► short smooth 3"→4" ─► CYCLONE ─► 5 ft RIGID 4" spool ─► 4"→6" ─► 30 ft 6" flex ─► S6 ─► 1 ft ─► wall cap
 [encl tap]                  [cyc in tap]  │  [cyc out tap]   [PITOT]          [run-start tap]    [fan-in tap]
                                           └─► sealed steel drum  [bin tap]
```

**Option A (recommended)** is shown above. **Option B** replaces the 4" spool with 5 ft of rigid 6" pipe right after the cyclone: it saves about 12 Pa but gives a much weaker pitot signal. **Option C** is the system as it stands today, with no separator (`lumosair init --option C`); use it to measure before buying anything.

### Flexible duct versus the one rigid section

The exhaust run is **4" and 6" flexible duct**, and it stays that way. The single exception is the **rigid measuring spool**: about 5 ft of smooth 4" galvanized pipe holding the pitot probe. It exists only to give one stable, known-geometry measuring station, and it is not representative of the rest of the ducting.

That matters because flex duct has corrugations that disturb the velocity profile, a less well defined inside diameter, and a centreline that moves when the hose is repositioned. A centreline reading taken in flex can be repeatable one day and wrong the next. Since the pitot is the primary CFM measurement that every other sensor is cross-checked against, its station is worth making rigid.

The model already treats the flex as flex: `flex: true` with a friction multiplier (`flexFactor`) of 2.5, roughly 2.5× the friction of smooth pipe. Use 1.5 if the run is pulled taut and 4.0 if it sags. The rigid spool is the only duct element modelled as smooth.

Everything before the cyclone is "dirty side" and must be short, smooth, metal and bonded to ground. The fan sits on the clean side.

---

## 3. What is measured, where, and why

| Channel | Node | Sensor | + port | − port | Tells you |
|---|---|---|---|---|---|
| `cyc_dp` | laser | SDP810-500Pa | cyclone inlet wall tap | cyclone outlet wall tap | Cyclone restriction. Also a second flow meter once calibrated (ΔP ∝ Q²). |
| `bin` | laser | XGZP6897D ±1 kPa | room | tap in drum lid | **Bin leaks.** A leaking bin stops a cyclone from separating. |
| `pitot` | laser | SDP810-500Pa + Dwyer 166-6-CF | pitot total (1/8" OD) | pitot static (1/4" OD) | Actual CFM. |
| `run_in` | laser | XGZP6897D ±1 kPa | room | 6" run start wall tap | With `fan_in`: resistance of the long run (clog, kink or leak). |
| `encl` | laser | SDP810-500Pa | room | tube into the enclosure | Fume capture: is the Lumos under negative pressure? |
| `fan_in` | fan | XGZP6897D ±1 kPa | room | fan inlet wall tap | Total suction. With the fan curve, reveals outlet-side problems. |
| `env` | laser | BME280 | – | – | Air density for accurate CFM (Spokane is about 7 % thinner than sea level). |

**Wall taps.** Drill a 1/8" hole square to the wall and **deburr the inside** (burrs cause large errors). Glue or print a small saddle with a barb, and run 3/16" ID silicone tubing to the sensor. Tubing a few feet long is fine for static pressure. Mount all laser-node sensors inside one enclosure and run tubes to them; do not run I²C wires out to the duct.

### The pitot station

**Probe: Dwyer 166-6-CF** (Series 160 pocket-size pitot-static tube). 304 stainless; 1/8" (3.18 mm) stem; 6" insertion length; 3" tip; ASME / AMCA / ASHRAE tip geometry, so the **probe coefficient is 1.000 — no probe calibration needed**. The `-CF` suffix adds a 1/8" male-NPT adjustable compression mounting fitting. Dwyer's own sizing rule is that the duct should be at least 30× the probe diameter, which for a 1/8" probe means **4" minimum** — exactly our 4" spool. (The 167-6-CF is the same probe with a shorter 1-1/2" tip.)

**Placement.** In the 5 ft rigid 4" spool, about **4 ft downstream** of the cyclone outlet and about 1 ft before the 4"→6" adapter. That is roughly 12 duct diameters upstream and 3 downstream, comfortably past Dwyer's minimum of 8.5 upstream and 1.5 downstream. Point the tip straight into the flow; the hemispherical tip tolerates about 15° of misalignment.

**Mounting.** The compression fitting has 1/8" *male* NPT threads, so the spool needs a matching 1/8" **FNPT boss** — a small welded or brazed boss, or a sealed bulkhead fitting. Don't try to thread NPT into thin duct wall. The fitting then sets insertion depth, allows rotation for alignment, locks the probe and seals around the stem. Set the sensing axis to the true **centreline: 2.000" from the inside wall** of a 4.000" ID spool — measured from the inside wall, not from the outside face of the fitting, since the wall and boss add offset.

Fit **two bosses 90° apart** at the same station: one carries the probe, the other takes a plug and is used for the second traverse axis during commissioning.

**Tubing.** The Dwyer's connections are not two matching barbs: **total pressure is 1/8" OD, static pressure is 1/4" OD**, both smooth tubing stubs. The SDP810's own ports are about 5.2 mm OD, which suits the 3/16" ID silicone used elsewhere in the system. So use short transition pieces at the probe:

- total (1/8" OD) → 1/8" ID silicone → reducer → 3/16" ID main line → SDP810 **+**
- static (1/4" OD) → 1/4" ID silicone → reducer → 3/16" ID main line → SDP810 **−**

These lines carry no continuous flow, so the diameter changes cost nothing.

**Two corrections that are easy to confuse.** They are independent and both apply:

| | What it corrects | Value |
|---|---|---|
| Probe coefficient `Cp` | The probe's own tip geometry | 1.000 for this Dwyer — nothing to apply |
| `profileFactor` | Centreline velocity is higher than the duct average | 0.9 default, measured during commissioning |

Dwyer says the same thing: a centreline reading times 0.9 is good to about ±5 % in the field, while a full traverse is needed for ±2 %.

**Calibration traverse (do this once).** Because the probe sits downstream of a cyclone, residual swirl or an asymmetric profile is plausible, and a single-diameter traverse could bias the result. Use a **two-axis, six-point equal-area traverse**: six depths along one diameter, then the same six through the second boss 90° away, 12 readings total. For a 4.000" ID spool the equal-area depths from the inside wall are:

| Point | Fraction of D | Depth |
|---|---|---|
| 1 | 0.043 | 0.172" |
| 2 | 0.146 | 0.584" |
| 3 | 0.296 | 1.184" |
| 4 | 0.704 | 2.816" |
| 5 | 0.854 | 3.416" |
| 6 | 0.957 | 3.828" |

Average the **square roots** of the 12 velocity-pressure readings (velocity ∝ √ΔP, so averaging raw pressures overstates the mean), then set `profileFactor` = mean velocity ÷ centreline velocity.

**Signal size.** The app's `pitot` channel predicts the *centreline* velocity pressure, which is the duct-average value divided by `profileFactor²`. At the flows this system reaches, the mean VP in the 4" spool runs about 6 Pa at 56 CFM to 38 Pa at 142 CFM; the centreline readings the sensor actually sees are about 7 and 47 Pa. An SDP810-500Pa has plenty of headroom there, with roughly 0.1 Pa of zero-point error. The SDP810-125Pa would fit the range more tightly but improves zero-point error only to about 0.08 Pa, which doesn't justify a second part number.

**Pitot tips clog.** The app cross-checks the pitot against the pressure taps and flags a suspect pitot automatically, falling back to the tap consensus for flow.

**Leaks between taps.** Seal every joint on the suction side with foil tape (a mastic seal is better). A leak lowers the reading at every downstream tap and shows up as "run losing suction".

---

## 4. Choosing the separator

Requirements derived from the model:

| Requirement | Target | Why |
|---|---|---|
| Inlet size | **4"–5" equivalent** (not 3") | Keeps cyclone ΔP within what the S6 can supply (≲ 150–250 Pa at your flow). |
| Pressure drop at 150 CFM | **< 1 inWC (250 Pa)** | The S6 makes less than 2 inWC at that flow, and about 0.8 inWC is already used by the Lumos, adapters, duct and wall cap. |
| Construction | Steel, grounded, sealed drum | Metal dust (combustible-dust practice). |
| Drum | 20–30 gal, sealed lid, tap for the `bin` sensor | Keeps the bin from leaking. |
| Verification | Measured with this system | Watch the cut size in the app and inspect the downstream duct after 25 and 50 coins. |

Candidates to evaluate (plug each into `lumosair model` with its real inlet size):
- **Oneida Heavy-Duty 3" Steel Dust Deputy** (~$400). Its 200 CFM minimum is not reachable with the S6 (see §1). It would suit a high-static-pressure blower instead.
- **Larger Oneida steel cyclones (4"/5" Super Dust Deputy class).** Oneida's FAQ describes the Super Dust Deputy as intended for systems above about 350 CFM, so ask Oneida about low-flow operation. For dense brass, the physics suggests separation can still be useful at lower speed, and the monitor will show whether it is.
- **A cyclone you design yourself (e.g. 3D printed, 4" inlet)**, sized for 120–180 CFM using the Lapple proportions in `SystemModel.CycloneCutSize`. For metal dust, use a conductive material or a metal liner and ground it.

If you want to keep the 3" steel Dust Deputy, the fan has to change: roughly **5–9 inWC at 200 CFM**, which means a dust-extractor or regenerative-blower class machine.

---

## 5. Hardware (BOM)

See [`BOM.xlsx`](BOM.xlsx) for the full list — it carries the sourcing state, part
numbers, dimensions, datasheet and 3D-model links, and a `Deleted` column recording
what earlier design revisions retired. Prices are approximate as of September 2026;
check before ordering. Items sold in packs show the per-item price as a formula.

| Item | Qty | Approx. |
|---|---|---|
| ESP32-WROOM-32 DevKit | 2 | $8–12 ea |
| Sensirion SDP810-500Pa (tube-connected, I²C) | 3 | ~$35–50 ea |
| CFSensor XGZP6897D, ±1 kPa, I²C | 3 | ~$8–15 ea |
| TCA9548A I²C multiplexer breakout | 1 | ~$5–8 |
| BME280 breakout | 1 | ~$5–10 |
| Dwyer 166-6-CF pitot-static probe | 1 | $160–220 |
| 1/8" FNPT boss / bulkhead fittings (probe + spare port) | 2 | ~$10–30 |
| 3/16" ID silicone tubing, 10 m (+ short 1/8" and 1/4" ID pieces and reducers) | 1 | ~$15–20 |
| Barbed tap fittings or printed saddles | 8 | ~$10 |
| 4" rigid galvanized pipe, 5 ft + couplers + foil tape | 1 | ~$20–35 |
| Hammond 1554F2GYCL enclosure (clear lid, 120 × 90 × 60.5) | 2 | ~$20–28 ea |
| 2.0" ST7789 240×320 display module | 2 | ~$9 ea (2-pack $17.99) |
| Ø8 mm bulkhead barb unions + blanking plugs | 16 | ~$20 total |
| 90° push-on barbed elbows (3/16") | 8 | ~$6 total |
| Ø12 mm illuminated latching push button | 2 | ~$4–7 ea |
| Cable glands, M3 standoff kit | 1 set | ~$15 |
| Custom PCB-A + PCB-B (2-layer, 105 × 41 mm) | 2 sets | ~$25–40 per set |
| USB 5 V supplies, Dupont/JST leads | 2 | ~$20 |
| **Total (excluding cyclone)** | | **≈ $500–680** |

The Dwyer is the single largest line item outside the separator. It is worth it here because the pitot is the reference every other channel is compared against, and because at 1/8" it is one of the few probes rated for a 4" duct. New distributor pricing sits around $160–$220; surplus listings are sometimes half that. A generic probe will work, but then its coefficient is unknown and has to be calibrated against something else.

**Wiring (laser node).**
- ESP32 GPIO21 (SDA) and GPIO22 (SCL) go to the TCA9548A and the BME280. Each sensor goes on its own mux port 0–4.
- Both sensor types have fixed I²C addresses (SDP810 = 0x25, XGZP = 0x6D), which is why the mux is needed.
- Use 3.3 V for all parts.
- Keep I²C leads under 30 cm. Most breakouts already carry 4.7–10 kΩ pull-ups.

**Fan node:** one XGZP6897D wired directly to GPIO21/22. Set `TCA9548A_ADDR 0` if you leave out the mux.

---

## 6. Commissioning

1. **Flash** both nodes with MicroPython, copy `lib/`, `main.py` and each box's `config.py` (see `firmware/micropython/README.md`). The REPL log and the box display should show every channel `ok`.
2. **Zero**: fan off, lid closed, wait 10 s, then click **Zero sensors** in the app. Offsets are stored on each node.
3. **Fan curve** (optional but valuable): record CFM and `fan_in` at levels 1–10. Put the measured points into `fan.curveCfm` / `fan.curvePa`. The fan's pressure is about `fan_in` plus the loss downstream of the fan.
4. **Cyclone K**: at level 10, K = `cyc_dp` ÷ (½ρV²) using the cyclone inlet velocity. Enter it in `cyclone.k`.
5. **Pitot traverse**: run the two-axis six-point traverse from §3 (12 readings), average the square roots of the readings, and set `profileFactor` = mean ÷ centreline. Then return the probe to the 2.000" centreline and lock the compression fitting.
6. **Baseline**: with a clean duct and an empty drum, run at your normal level and click **Capture baseline**. From then on, drift is measured against this known-good state.
7. **Verify**: engrave 25 coins, weigh the drum catch, and look inside the 6" run just after the 4"→6" expansion.

---

## 6a. The boxes

Both nodes live in the **same enclosure with the same eight bulkheads**: a Hammond
**1554F2GYCL**, 120 × 90 × 60.5 mm, clear polycarbonate lid. The fan box plugs the
seven ports it doesn't use. One box design, one drill template, one spares list.

Enclosure fitment

### How it stacks

Everything that needs a hose is on one board screwed to the floor; everything else
is on a second board above it. Nothing is squeezed past anything.

| | Height above the inside floor | Carries |
|---|---|---|
| **PCB-A** — sensor board | 4 → 5.6 mm, on M3 standoffs | 3 × SDP810, 2 × XGZP6897D. Every port faces **up**. |
| hose zone | 6 → 31 mm | the eight silicone runs, and nothing else |
| **PCB-B** — processor board | 34 → 35.6 mm, on spacers from PCB-A | ESP32-WROOM-32E, TCA9548A, BME280 |
| display | 41.6 → 45.8 mm, on 6 mm standoffs | 2.0" ST7789, reading up through the clear lid |
| | ~9 mm spare under the lid | |

### How the hoses actually connect

This is the part that decides the size of the box, so it is modelled as real tubing,
not as a note.

Each SDP810 is turned **90° on PCB-A** so its two barbs sit one behind the other at
the *same x* as one column of bulkheads. A **push-on 90° barbed elbow** goes on each
barb, turning the hose to point at the wall. From there it is a short, almost
straight run of 3/16" ID silicone to its bulkhead — 20 to 45 mm, tightest bend
radius **13 mm**, nothing crossing anything else.

Hose runs

The elbows are not a detail. Without them the hose leaves the barb pointing straight
up and has to turn a full bend radius before it can enter a wall port, which pushes
the ports to z ≈ 38 mm and the lid to 71 mm. `python cad/enclosure.py --compare`
prints both cases:

| fittings | tallest item | headroom in the 1554F | tightest bend |
|---|---|---|---|
| 90° elbows | 51.5 mm | 3.0 mm | 13.1 mm — fits |
| straight onto the barb | 65.1 mm | −10.6 mm | 3.3 mm — kinks |

**The VENT port** is an open bulkhead that keeps the box interior at room pressure.
That is the reference side for the bin, run and enclosure channels, so each of those
sensors needs only one hose instead of two.

### Ports, switch and gland

Eight Ø8 mm bulkheads, two rows of four, 22 mm pitch, rows 13 and 27 mm above the
inside floor. Which sensor uses which hole is chosen by the model — it picks the
assignment with the least sideways and vertical offset, because that is what decides
whether the hoses bend gently or kink.

| Column | Lower row | Upper row |
|---|---|---|
| 1 | CYC + | CYC − |
| 2 | PITOT T | PITOT S |
| 3 | VENT | ENCL |
| 4 | BIN | RUN |

Both boxes are drilled **and populated** the same — same two PCBs, same three
SDP810s, same two XGZP6897Ds, same firmware. What differs is only what you connect
outside: each box plugs the bulkheads its location doesn't use, and VENT always
stays open. A box is therefore a spare for either position, and there is one
spares list rather than two.

A **Ø12 mm illuminated latching push button** sits centred on the same front panel,
above the hose runs: it is the power switch, and its ring is the power-on indicator,
so there is no separate LED to drill for. The **Ø12.5 mm cable gland** for the 5 V
lead goes in the left end wall, in the strip beside the hoses. Both are clear of
PCB-B; on a 90 mm-deep box neither fits on the back wall without fouling it.

### Which box am I?

Because the two boxes are populated identically, a node cannot tell what it is by
scanning its own I²C bus — every box has every sensor. What tells them apart is what
is connected on the outside, so that is what it looks at, in this order.

**1. The fan pigtail.** Only the fan box has the AC Infinity UIS lead. A sense pin on
PCB-B watches the UIS 10 V rail through a divider: rail present ⇒ this is the fan
node. This is the one signal that is unambiguous at power-on, before any air moves,
so it decides on its own when it is present.

**2. What the taps see, once air is moving.** An unconnected tap sits at room
pressure and reads about zero. After the first minute above a usable flow, a box
reading real signal on `cyc_dp` / `pitot` / `bin` / `run_in` is the laser node; a box
where those sit at zero and `fan_in` does not is the fan node. This confirms (1), and
stands alone if the sense pin is not fitted.

**3. Ask, once.** If neither is conclusive — no pigtail sense, no flow yet, or the two
disagree — the box puts a two-choice question on its screen and answers it with the
front-panel button, which is the only control on the outside of a sealed box:

```
        WHICH BOX IS THIS?

     > LASER    (short press)
       FAN      (hold 2 s)
```

The answer is written to NVS, so the question is asked once per box and not again;
`{"cmd":"clear_role"}` erases it if you move a box. `NODE_ID` in `config.py`
overrides the whole process, which is what you want on the bench.

**Why the button and not the screen.** The display is a 4-wire SPI ST7789 — SCK,
MOSI, CS, DC — with no touch controller, and no spare pins reserved for one. Even
with a touch panel it would not help here: the display sits on standoffs *inside* the
box, reading up through a fixed polycarbonate lid, so nothing can reach it without
undoing four screws and breaking the seal that keeps the brass dust out. A touch
display would mean a lid cut-out or a second panel, and that is the one thing the
clear lid exists to avoid. The latching button is already on the marked face, outside
the seal, and one button is exactly enough to answer a question with two choices.

### Marking the panel

`python cad/artwork.py` writes 1:1 SVGs from the same model, so a moved port moves
its hole, its label and its PCB mounting hole together. Red is cut/drill, black is
engrave.

Front panel artwork

It also writes `pcb_a_outline.dxf` and `pcb_b_outline.dxf` — board edge plus M3
mounting holes — to import into KiCad as the board outline.

### Why this size

The lid is 108 cm². The display is 22 cm² of it and PCB-B is 43 cm². The box is
about twice the display in each direction, which is roughly the floor set by the
three SDP810s sitting side by side. A socketed ESP32 DevKit does not fit — it needs
the 20 mm taller 1554G — which is the argument for soldering the bare module.

The clear lid is doing real work: **the display needs no cut-out**, so the box stays
sealed against the dust it is there to monitor.

The model is a script (`cad/enclosure.py`), so it stays honest — it prints part
positions, hose lengths, bend radii, clearances and collisions, and exits non-zero
if something doesn't fit. `cad/README.md` covers regenerating everything.

---

## 6b. The box display

Each box carries a 2.0" 240×320 IPS panel (ST7789, 4-wire SPI, 56 × 40 mm). It shows
what the node measures *and* what the PC concludes, so you can glance at the box
while standing at the laser:

- status band — green / amber / orange / red, plus the node name and IP
- system airflow in CFM and where the number came from (pitot, taps, model)
- fan level, Auto or Manual, and the recommended level
- the top finding in plain words
- every channel on that node in Pa, with a bar and a fault flag

The system-level figures arrive in a small broadcast from the PC (UDP 47812, or MQTT
`lumosair/system/status`). If the app isn't running, the screen says so and keeps
showing live pressures.

```json
{"t":"status","cfm":142.0,"src":"pitot","sev":"warning",
 "fan":{"level":7,"mode":"auto","rec":8},"msg":"Dust bin appears to be leaking"}
```

---

## 6c. Fan control: automatic, with manual override

The app has a **Control** selector on the fan card:

- **Manual** — the app recommends a level; you set the dial. Nothing is ever sent.
- **Auto** — the app sends `{"cmd":"set_level","level":N}` to the fan node.

Auto is deliberately asymmetric, because the two directions have different stakes:

| Situation | What happens |
|---|---|
| A higher level is needed | sent immediately — losing transport velocity means brass in the duct |
| A critical finding appears | fan pinned at the configured maximum |
| A lower level would do | only after the lower recommendation has held for the dwell time (30 s by default), and only if it's at least one level lower |
| Same level | nothing sent; the level is re-sent at most once a minute to re-sync a node that rebooted |

Limits live in `fanControl` in `system.json`: `minLevel`, `maxLevel`, `dwellSeconds`,
`minStepDown`, `controlNode`, and `enabled` to switch automation off entirely.

**The hardware side is not verified yet.** The CLOUDLINE UIS connector pinout is
community-reverse-engineered, so the firmware ships with `FAN_OUTPUT_ENABLED = False`:
the node accepts the level, reports it and shows it, but drives no pin. The whole
control path can therefore be run end to end today with you as the actuator — and
once you've checked the pinout with a meter, one config line closes the loop.

---

## 7. How the diagnostics work

Every sensor reading is converted into "the flow that would explain this reading" using the healthy model, corrected by the baseline. When they all agree, the system is healthy. The first one that disagrees points to where the problem is.

| Finding | Trigger | Typical cause |
|---|---|---|
| Duct velocity too low before separator | slowest pre-separator duct < material minimum | Duct between the Lumos and the cyclone, or fan too slow |
| Cyclone too slow to separate well | estimated cut size > material target, or inlet < ~1,000 fpm | Fan level too low |
| Cyclone ΔP above / below normal | ≥ 30 % drift | Build-up / leak, clogged tap |
| Dust bin leaking | bin suction ≥ 30 % below normal | Lid or gasket |
| Long run restricted / heavily restricted | run ΔP ≥ 30 % / 60 % above normal | Deposit, kink, crushed flex |
| Long run losing suction | run ΔP ≥ 30 % below normal | Loose joint or leak |
| Pitot doesn't match other sensors | pitot ≥ 20 % off the tap consensus | Clogged pitot (app switches to the consensus) |
| Less flow than the fan should move | measured flow ≥ 20 % below the fan curve at the measured suction | Outside damper stuck, screen clogged, impeller fouled |
| Enclosure not under enough suction | < 3 Pa | Lid open, outlet disconnected |
| Fan cannot reach safe transport velocity | even level 10 isn't enough | System redesign needed |
| Node offline / sensor fault / saturated | – | Power, Wi-Fi, wiring, sensor range |

**Recommended level** is the lowest S6 level that meets every requirement: duct velocity before the separator, cyclone cut size, and cyclone minimum speed. It uses the fan laws (flow ∝ speed).

All nine simulated faults are covered by automated tests (`app/tests`). Each is detected correctly, with no false alarms on the healthy system.

---

## 8. Phase 2 ideas

- **Automatic fan speed.** The community has reverse-engineered the CLOUDLINE UIS controller port for ESP32 control. Verify the pinout with a scope before connecting anything. The app already calculates the level to set.
- **Home Assistant.** Enable MQTT in the firmware; the telemetry topics can be added as MQTT sensors, and "Jim Bob" could announce "cyclone bin leaking".
- **Downstream dust check.** A PM sensor on a small sample line after the cyclone would give a direct "is brass getting through" signal.
- **Drum weight.** A load cell under the drum would log grams captured per job.

## 9. Assumptions and limits

- The fan curve and the Lumos internal resistance are estimates until measured (see §6).
- Cyclone K and cut size use the Shepherd–Lapple and Lapple correlations. They are good for trends and ±30 % absolute.
- Sub-micron fume is not separated by any cyclone. It goes outside with the exhaust, as it does today.
- Pressure-based flow needs air moving well above about 30 CFM to be meaningful. Below that the app reports "fan off" rather than diagnosing.
- Flex duct friction is modelled with a multiplier (`flexFactor`, default 2.5). Real flex varies from about 1.5 pulled taut to 4+ sagging; at this system's flows that whole range moves the operating point by only a few CFM, but it matters more if the run is ever lengthened.
- The pitot's `profileFactor` starts at Dwyer's field value of 0.9 and is only as good as the traverse that replaces it. Swirl downstream of a cyclone is the reason for the two-axis traverse.

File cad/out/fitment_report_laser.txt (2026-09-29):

LumosAir stacked node — laser box, 1554F2GYCL, MCU: module
outside 120 x 90 x 60.5 mm, inside 112.9 x 78.9 x 54.5 mm

Stack
  PCB-A underside         4.0 mm (standoffs off the floor)
  PCB-B underside        34.0 mm (spacers off PCB-A)
  tallest item           45.8 mm  (display glass)
  headroom under lid      8.7 mm

Parts
  PCB-A (sensor board)               x    4.0– 108.9  y   34.0–  74.9  z   4.0–  5.6
  SDP810 cyc_dp                      x   14.5–  32.5  y   37.0–  66.0  z   5.6– 15.8
  SDP810 encl                        x   58.5–  76.5  y   37.0–  66.0  z   5.6– 15.8
  SDP810 pitot                       x   36.5–  54.5  y   37.0–  66.0  z   5.6– 15.8
  XGZP bin sensor                    x   84.0–  95.0  y   38.0–  48.8  z   5.6– 15.2
  XGZP run_in sensor                 x   84.0–  95.0  y   56.8–  67.6  z   5.6– 15.2
  elbow BIN                          x   85.9–  93.1  y   31.4–  43.4  z   7.6– 14.8
  elbow RUN                          x   85.9–  93.1  y   50.2–  62.2  z   7.6– 14.8
  barb cyc_dp+1                      x   20.9–  26.1  y   55.2–  60.4  z  15.8– 25.5
  barb cyc_dp-1                      x   20.9–  26.1  y   42.6–  47.8  z  15.8– 25.5
  barb encl+1                        x   64.9–  70.1  y   55.2–  60.4  z  15.8– 25.5
  barb encl-1                        x   64.9–  70.1  y   42.6–  47.8  z  15.8– 25.5
  barb pitot+1                       x   42.9–  48.1  y   55.2–  60.4  z  15.8– 25.5
  barb pitot-1                       x   42.9–  48.1  y   42.6–  47.8  z  15.8– 25.5
  USB-C coupler, 5 V POWER           x    0.0–  34.0  y    9.0–  31.0  z  16.0– 40.0
  USB-C coupler, FAN (UIS)           x   78.9– 112.9  y    9.0–  31.0  z  16.0– 40.0
  elbow CYC +                        x   19.9–  27.1  y   33.2–  45.2  z  17.9– 25.1
  elbow CYC −                        x   19.9–  27.1  y   45.8–  57.8  z  17.9– 25.1
  elbow ENCL                         x   63.9–  71.1  y   45.8–  57.8  z  17.9– 25.1
  elbow PITOT S                      x   41.9–  49.1  y   45.8–  57.8  z  17.9– 25.1
  elbow PITOT T                      x   41.9–  49.1  y   33.2–  45.2  z  17.9– 25.1
  PCB-B (processor + display hat)    x    4.0– 108.9  y   34.0–  74.9  z  34.0– 35.6
  BME280                             x   88.0–  92.0  y   67.9–  71.9  z  35.6– 36.8
  ESP32-WROOM-32E (soldered)         x   67.0–  85.0  y   36.0–  61.5  z  35.6– 38.7
  TCA9548A mux                       x   88.0–  96.0  y   37.0–  43.5  z  35.6– 36.8
  2.0" ST7789 display                x    8.0–  64.0  y   34.5–  74.5  z  41.6– 43.2
  display glass                      x   11.5–  60.5  y   38.0–  71.0  z  43.2– 45.8

Hoses (sensor port -> bulkhead, inside the box)
  CYC +     length  23.4 mm   min bend R  13.1 mm   highest point  25.5 mm
  CYC −     length  34.4 mm   min bend R  48.0 mm   highest point  31.0 mm
  PITOT T   length  23.4 mm   min bend R  13.1 mm   highest point  25.5 mm
  PITOT S   length  34.4 mm   min bend R  48.0 mm   highest point  31.0 mm
  ENCL      length  34.4 mm   min bend R  48.0 mm   highest point  31.0 mm
  BIN       length  19.5 mm   min bend R  47.9 mm   highest point  17.0 mm
  RUN       length  42.3 mm   min bend R  23.2 mm   highest point  31.0 mm
  tightest bend 13.1 mm; clearance from the tubes to PCB-B 3.0 mm

Collisions
  none

Bulkheads (identical on both boxes)
  8 x Ø8 mm — two rows of 4 at 22 mm pitch, z = 13 and 27 mm
    x   23.5  z 13.0   CYC +
    x   45.5  z 13.0   PITOT T
    x   67.5  z 13.0   VENT
    x   89.5  z 13.0   BIN
    x   23.5  z 27.0   CYC −
    x   45.5  z 27.0   PITOT S
    x   67.5  z 27.0   ENCL
    x   89.5  z 27.0   RUN
  USB-C couplers: Ø24 mm + 2 x M3 at y 20, z 28 — left end wall 5 V POWER, right end wall FAN (UIS). No switch on the box.

How much bigger is the box than the display?
  lid           108.0 cm²
  PCB-B          42.9 cm² (40% of the lid)
  display        22.4 cm² (21% of the lid)

Notes
  • PCB-A carries everything with a hose; its sensor ports face UP.
  • Each hose is a short silicone tube from a sensor port to one bulkhead.
  • The VENT port keeps the box interior at room pressure, which is the
    reference side for the bin, run and enclosure channels — so those
    sensors need only one tube each.
  • The lid is clear, so the display needs no cut-out.
  • Verify the floor boss pattern for this box size before drilling PCB-A.

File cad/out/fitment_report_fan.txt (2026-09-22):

LumosAir stacked node — fan box, 1554F2GYCL, MCU: module
outside 120 x 90 x 60.5 mm, inside 112.9 x 78.9 x 54.5 mm

Stack
  PCB-A underside         4.0 mm (standoffs off the floor)
  PCB-B underside        20.0 mm (spacers off PCB-A)
  tallest item           51.5 mm  (latching switch body)
  headroom under lid      3.0 mm

Parts
  PCB-A (sensor board)               x    4.0– 108.9  y   34.0–  74.9  z   4.0–  5.6
  XGZP fan_in sensor                 x   18.0–  29.0  y   38.0–  48.8  z   5.6– 15.2
  elbow FAN IN                       x   19.9–  27.1  y   31.4–  43.4  z   7.6– 14.8
  PCB-B (processor + display hat)    x    4.0– 108.9  y   34.0–  74.9  z  20.0– 21.6
  cable gland body                   x    0.0–  18.0  y   12.2–  27.8  z  20.2– 35.8
  BME280                             x   88.0–  92.0  y   67.9–  71.9  z  21.6– 22.8
  ESP32-WROOM-32E (soldered)         x   67.0–  85.0  y   36.0–  61.5  z  21.6– 24.7
  2.0" ST7789 display                x    8.0–  64.0  y   34.5–  74.5  z  27.6– 29.2
  display glass                      x   11.5–  60.5  y   38.0–  71.0  z  29.2– 31.8
  latching switch body               x   49.0–  64.0  y    0.0–  22.0  z  36.5– 51.5

Hoses (sensor port -> bulkhead, inside the box)
  FAN IN    length  19.5 mm   min bend R  47.9 mm   highest point  17.0 mm
  tightest bend 47.9 mm; clearance from the tubes to PCB-B 3.0 mm

Collisions
  none

Bulkheads (identical on both boxes)
  8 x Ø8 mm — two rows of 4 at 22 mm pitch, z = 13 and 27 mm
    x   23.5  z 13.0   FAN IN
    x   45.5  z 13.0   VENT
    x   67.5  z 13.0   PLUG
    x   89.5  z 13.0   PLUG
    x   23.5  z 27.0   PLUG
    x   45.5  z 27.0   PLUG
    x   67.5  z 27.0   PLUG
    x   89.5  z 27.0   PLUG
  gland Ø12.5 mm at y 20, z 28 (left end wall)
  switch Ø12.0 mm at x 56.5, z 44 (front wall, above the ports)

How much bigger is the box than the display?
  lid           108.0 cm²
  PCB-B          42.9 cm² (40% of the lid)
  display        22.4 cm² (21% of the lid)

Notes
  • PCB-A carries everything with a hose; its sensor ports face UP.
  • Each hose is a short silicone tube from a sensor port to one bulkhead.
  • The VENT port keeps the box interior at room pressure, which is the
    reference side for the bin, run and enclosure channels — so those
    sensors need only one tube each.
  • The lid is clear, so the display needs no cut-out.
  • Verify the floor boss pattern for this box size before drilling PCB-A.

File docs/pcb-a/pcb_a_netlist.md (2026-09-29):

# PCB-A netlist

Generated by `cad/schematic.py` from the same table as the drawing. Do not edit by hand.

## Nets

| Net | Connects |
|---|---|
| `+3V3` | C2.1, J2.3 (3V3), U6.VIN (VIN), U6.RST (RST), C3.1, U7.VIN (VIN), J4.1 (3V3), JP1.1 (3V3), U1.2 (VDD), R10.1, R11.1, C4.1, U2.2 (VDD), R12.1, R13.1, C5.1, U3.2 (VDD), R14.1, R15.1, C6.1, R2.1 |
| `+5V` | F1.2, D1.K (K), C1.1, J2.1 (+5V), JP1.3 (5V) |
| `GND` | J1.2 (GND), D1.A (A), C1.2, C2.2, J2.2 (GND), J2.8 (GND), U6.GND (GND), U6.A0 (A0), U6.A1 (A1), U6.A2 (A2), C3.2, U7.GND (GND), J4.2 (GND), U1.3 (GND), C4.2, U2.3 (GND), C5.2, U3.3 (GND), C6.2, U4.GND (GND), C7.2, U5.GND (GND), C8.2, OK1.3 (E), C9.2, OK2.2 (K), H1.1 |
| `UIS_GND` | J3.2 (GND), D2.A (A), OK1.2 (K), OK2.3 (E) |
| `UIS_V+` | J3.1 (V+), R1.1 |
| `XGZP_VCC` | JP1.2 (COM), U4.VCC (VCC), R16.1, R17.1, C7.1, U5.VCC (VCC), R18.1, R19.1, C8.1 |
| `+5V_IN` | J1.1 (+5V), F1.1 |
| `FAN_CTRL` | J2.7 (GPIO25), R3.1 |
| `FAN_SENSE` | J2.6 (GPIO33), OK1.4 (C), R2.2, C9.1 |
| `OK1_A` | R1.2, D2.K (K), OK1.1 (A) |
| `OK2_A` | R3.2, OK2.1 (A) |
| `SCL` | J2.5 (GPIO22), U6.SCL (SCL), U7.SCL (SCL) |
| `SCL0` | U6.SC0 (SC0), U1.1 (SCL), R11.2 |
| `SCL1` | U6.SC1 (SC1), U4.SCL (SCL), R17.2 |
| `SCL2` | U6.SC2 (SC2), U2.1 (SCL), R13.2 |
| `SCL3` | U6.SC3 (SC3), U5.SCL (SCL), R19.2 |
| `SCL4` | U6.SC4 (SC4), U3.1 (SCL), R15.2 |
| `SCL5` | U6.SC5 (SC5), J4.4 (SCL) |
| `SDA` | J2.4 (GPIO21), U6.SDA (SDA), U7.SDA (SDA) |
| `SDA0` | U6.SD0 (SD0), U1.4 (SDA), R10.2 |
| `SDA1` | U6.SD1 (SD1), U4.SDA (SDA), R16.2 |
| `SDA2` | U6.SD2 (SD2), U2.4 (SDA), R12.2 |
| `SDA3` | U6.SD3 (SD3), U5.SDA (SDA), R18.2 |
| `SDA4` | U6.SD4 (SD4), U3.4 (SDA), R14.2 |
| `SDA5` | U6.SD5 (SD5), J4.3 (SDA) |
| `UIS_CTRL` | J3.3 (CTRL), OK2.4 (C) |
| `UIS_SPARE` | J3.4 (SPARE) |

## Parts

| Ref | Value | Fit | Pins → net | Notes |
|---|---|---|---|---|
| J1 | 5V IN, 2-pin | option | 1/+5V → +5V_IN; 2/GND → GND | From the USB-C POWER socket (2-wire). Leave J1/F1/D1 off if the box is powered through the ESP32 board's own USB port. |
| JP1 | XGZP supply select, 3-pin | fit | 1/3V3 → +3V3; 2/COM → XGZP_VCC; 3/5V → +5V | Jumper 1-2 for a 3.3 V XGZP (part no. ends in 33), 2-3 for the default 5 V part. Sets both XGZP supplies AND their channel pull-ups; the TCA9548A translates. |
| J2 | ESP32 link, 8-pin 2.54 | fit | 1/+5V → +5V; 2/GND → GND; 3/3V3 → +3V3; 4/GPIO21 → SDA; 5/GPIO22 → SCL; 6/GPIO33 → FAN_SENSE; 7/GPIO25 → FAN_CTRL; 8/GND → GND | Wires to the ESP32 board: 5V, GND, 3V3, P21, P22, P33, P25 terminals. Pin 1 +5V is fed FROM the ESP32 board when J1 is not fitted. |
| J3 | UIS fan lead, 4-way screw terminal | fit | 1/V+ → UIS_V+; 2/GND → UIS_GND; 3/CTRL → UIS_CTRL; 4/SPARE → UIS_SPARE | Wires from the USB-C FAN socket / cut UIS cable. Which UIS contact is which is NOT verified: meter it and land each wire on its function here. UIS_GND is NOT board GND. |
| J4 | Spare I2C ch5, 4-pin | option | 1/3V3 → +3V3; 2/GND → GND; 3/SDA → SDA5; 4/SCL → SCL5 | Unpopulated header for a future sensor. |
| U1 | SDP810 cyc_dp | fit | 1/SCL → SCL0; 2/VDD → +3V3; 3/GND → GND; 4/SDA → SDA0 | 0x25 on mux ch0. Pins per datasheet Table 1 (BOTTOM view). |
| U2 | SDP810 pitot | fit | 1/SCL → SCL2; 2/VDD → +3V3; 3/GND → GND; 4/SDA → SDA2 | 0x25 on mux ch2. Pins per datasheet Table 1 (BOTTOM view). |
| U3 | SDP810 encl | fit | 1/SCL → SCL4; 2/VDD → +3V3; 3/GND → GND; 4/SDA → SDA4 | 0x25 on mux ch4. Pins per datasheet Table 1 (BOTTOM view). |
| U4 | XGZP6897D bin | fit | VCC → XGZP_VCC; GND → GND; SCL → SCL1; SDA → SDA1 | 0x6D on mux ch1. Module pins by silkscreen; check before the footprint. |
| U5 | XGZP6897D run_in (fan box: fan_in) | fit | VCC → XGZP_VCC; GND → GND; SCL → SCL3; SDA → SDA3 | 0x6D on mux ch3. Module pins by silkscreen; check before the footprint. |
| U6 | TCA9548A breakout (0x70) | fit | VIN → +3V3; GND → GND; SDA → SDA; SCL → SCL; RST → +3V3; A0 → GND; A1 → GND; A2 → GND; SD0 → SDA0; SC0 → SCL0; SD1 → SDA1; SC1 → SCL1; SD2 → SDA2; SC2 → SCL2; SD3 → SDA3; SC3 → SCL3; SD4 → SDA4; SC4 → SCL4; SD5 → SDA5; SC5 → SCL5 | A0-A2 low = 0x70. Breakout already has 10k pull-ups on SDA/SCL and RST. SD6/SC6/SD7/SC7 unused. |
| U7 | GY-BME280 3.3 V (0x76) | fit | VIN → +3V3; GND → GND; SCL → SCL; SDA → SDA | Main bus, not behind the mux. Keep it away from the ESP32 and the regulator. |
| H1 | M3 mounting hole | fit | 1 → GND | H1 to GND (shield); others isolated |
| H2 | M3 mounting hole | fit | 1 → NC | H1 to GND (shield); others isolated |
| H3 | M3 mounting hole | fit | 1 → NC | H1 to GND (shield); others isolated |
| H4 | M3 mounting hole | fit | 1 → NC | H1 to GND (shield); others isolated |
| D1 | SMBJ5.0A TVS | option | K → +5V; A → GND | Clamps >5.6 V on +5V so F1 trips; cathode to +5V. |
| D2 | 1N4148 | fit | K → OK1_A; A → UIS_GND | Reverse-polarity guard across the LED (anode to UIS_GND) |
| F1 | PTC fuse 0.5 A hold | option | 1 → +5V_IN; 2 → +5V | e.g. MF-R050 / 1206L050. Trips if the 10 V fan lead goes into the power socket. |
| C1 | 10 uF | fit | 1 → +5V; 2 → GND | 5 V bulk |
| C2 | 10 uF | fit | 1 → +3V3; 2 → GND | 3.3 V bulk |
| C3 | 100 nF | fit | 1 → +3V3; 2 → GND | at U6 VIN |
| C4 | 100 nF | fit | 1 → +3V3; 2 → GND | at U1 VDD |
| C5 | 100 nF | fit | 1 → +3V3; 2 → GND | at U2 VDD |
| C6 | 100 nF | fit | 1 → +3V3; 2 → GND | at U3 VDD |
| C7 | 100 nF | fit | 1 → XGZP_VCC; 2 → GND | at U4 VCC |
| C8 | 100 nF | fit | 1 → XGZP_VCC; 2 → GND | at U5 VCC |
| C9 | 100 nF | option | 1 → FAN_SENSE; 2 → GND | filter; optional |
| R1 | 2.2k | fit | 1 → UIS_V+; 2 → OK1_A | LED current ~4 mA at 10 V |
| R2 | 10k | fit | 1 → +3V3; 2 → FAN_SENSE | pull-up |
| R3 | 330 | DNP | 1 → FAN_CTRL; 2 → OK2_A | ~6 mA from GPIO25 |
| R10 | 4.7k | fit | 1 → +3V3; 2 → SDA0 | ch0 SDA pull-up |
| R11 | 4.7k | fit | 1 → +3V3; 2 → SCL0 | ch0 SCL pull-up |
| R12 | 4.7k | fit | 1 → +3V3; 2 → SDA2 | ch2 SDA pull-up |
| R13 | 4.7k | fit | 1 → +3V3; 2 → SCL2 | ch2 SCL pull-up |
| R14 | 4.7k | fit | 1 → +3V3; 2 → SDA4 | ch4 SDA pull-up |
| R15 | 4.7k | fit | 1 → +3V3; 2 → SCL4 | ch4 SCL pull-up |
| R16 | 4.7k | option | 1 → XGZP_VCC; 2 → SDA1 | ch1 SDA pull-up; DNP if the module has its own |
| R17 | 4.7k | option | 1 → XGZP_VCC; 2 → SCL1 | ch1 SCL pull-up; DNP if the module has its own |
| R18 | 4.7k | option | 1 → XGZP_VCC; 2 → SDA3 | ch3 SDA pull-up; DNP if the module has its own |
| R19 | 4.7k | option | 1 → XGZP_VCC; 2 → SCL3 | ch3 SCL pull-up; DNP if the module has its own |
| OK1 | PC817 (fan sense) | fit | 1/A → OK1_A; 2/K → UIS_GND; 4/C → FAN_SENSE; 3/E → GND | FAN_SENSE reads LOW when a fan lead with its rail is plugged in (DESIGN 6a step 1). |
| OK2 | PC817 (fan control) | DNP | 1/A → OK2_A; 2/K → GND; 4/C → UIS_CTRL; 3/E → UIS_GND | DO NOT FIT until the UIS pinout and signalling are verified (FAN_OUTPUT_ENABLED stays False). |

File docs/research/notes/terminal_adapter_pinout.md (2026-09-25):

# "FOR ESP32 TERMINAL ADAPTER" screw-terminal board vs ESP32-DevKitC V4 38-pin pinout

## Q1. Do the silkscreen labels match the ESP32-DevKitC V4 J2/J3 headers pin for pin? Label → GPIO mapping; is "CND" CMD?

### Takeaway
Yes. Both columns match Espressif's DevKitC V4 J2 (left) and J3 (right) tables exactly, in order, pin 1 to pin 19. "CND" sits where J2 pin 18 is **CMD = GPIO11**, a SPI-flash line. It is a misprint of CMD and is **not ground**.

### Cited Findings
- Espressif DevKitC V4 **J2** (pins 1 to 19): 3V3, EN (CHIP_PU/reset), VP (GPIO36), VN (GPIO39), IO34, IO35, IO32, IO33, IO25, IO26, IO27, IO14 (MTMS), IO12 (MTDI), GND, IO13 (MTCK), D2 (GPIO9), D3 (GPIO10), CMD (GPIO11), 5V — [Espressif ESP32-DevKitC V4 user guide](https://docs.espressif.com/projects/esp-dev-kits/en/latest/esp32/esp32-devkitc/user_guide.html)
- Espressif DevKitC V4 **J3** (pins 1 to 19): GND, IO23, IO22, TX (GPIO1, U0TXD), RX (GPIO3, U0RXD), IO21, GND, IO19, IO18, IO5, IO17, IO16, IO4, IO0 (Boot), IO2, IO15 (MTDO), D1 (GPIO8), D0 (GPIO7), CLK (GPIO6) — [Espressif DevKitC V4 user guide](https://docs.espressif.com/projects/esp-dev-kits/en/latest/esp32/esp32-devkitc/user_guide.html)
- "The pins D0, D1, D2, D3, CMD and CLK are used internally for communication between ESP32 and SPI flash memory" — [Espressif DevKitC V4 user guide](https://docs.espressif.com/projects/esp-dev-kits/en/latest/esp32/esp32-devkitc/user_guide.html)
- GPIO16/17 are available only on WROOM/SOLO-1 DevKitC boards. On WROVER boards they are taken by PSRAM — [Espressif DevKitC V4 user guide](https://docs.espressif.com/projects/esp-dev-kits/en/latest/esp32/esp32-devkitc/user_guide.html)
- Listing/review, not primary: one Amazon UK review of a DIYables 38-pin screw-terminal adapter says "the labels on the breakout board are all wrong" (quoted in the search-result summary; the page itself returned 503 and could not be read) — [Amazon UK DIYables listing](https://www.amazon.co.uk/Screw-Terminal-Breakout-Board-38-pin/dp/B0CRKJX66W)

Label-by-label mapping (adapter silkscreen → DevKitC pin → GPIO):

| # | Left label | DevKitC J2 | GPIO | | Right label | DevKitC J3 | GPIO |
|---|---|---|---|---|---|---|---|
| 1 | 3V3 | 3V3 | power | | GND | GND | ground |
| 2 | EN | EN | CHIP_PU (reset) | | P23 | IO23 | 23 |
| 3 | SVP | VP | 36 (input only) | | P22 | IO22 | 22 |
| 4 | SVN | VN | 39 (input only) | | TX | TX | 1 (U0TXD) |
| 5 | P34 | IO34 | 34 (input only) | | RX | RX | 3 (U0RXD) |
| 6 | P35 | IO35 | 35 (input only) | | P21 | IO21 | 21 |
| 7 | P32 | IO32 | 32 | | GND | GND | ground |
| 8 | P33 | IO33 | 33 | | P19 | IO19 | 19 |
| 9 | P25 | IO25 | 25 | | P18 | IO18 | 18 |
| 10 | P26 | IO26 | 26 | | P5 | IO5 | 5 (strap) |
| 11 | P27 | IO27 | 27 | | P17 | IO17 | 17 |
| 12 | P14 | IO14 | 14 (MTMS) | | P16 | IO16 | 16 |
| 13 | P12 | IO12 | 12 (MTDI, strap) | | P4 | IO4 | 4 |
| 14 | GND | GND | ground | | P0 | IO0 | 0 (strap/BOOT) |
| 15 | P13 | IO13 | 13 (MTCK) | | P2 | IO2 | 2 (strap) |
| 16 | SD2 | D2 | 9 (flash) | | P15 | IO15 | 15 (MTDO, strap) |
| 17 | SD3 | D3 | 10 (flash) | | SD1 | D1 | 8 (flash) |
| 18 | **CND** | **CMD** | **11 (flash)** | | SD0 | D0 | 7 (flash) |
| 19 | 5V | 5V | power | | CLK | CLK | 6 (flash) |

### Inferences
- The silkscreen is the DevKitC V4 order copied exactly, with short names ("P"+number, "SD" in place of "D"). "CND" is in the CMD slot (pin 18, between SD3/GPIO10 and 5V). The only grounds are J2 pin 14 and J3 pins 1 and 7, so CND is GPIO11, not GND. **Never use CND as a ground return.** Tying GPIO11 to GND holds the flash CMD line low and stops the chip from reading flash.
- The user's board is an "ESP32-WROOM-32 DevKit" (38-pin, CP2102). Such boards are normally DevKitC-V4 clones with the same J2/J3 order. The user should still check the silkscreen printed on the DevKit itself: if its left row reads 3V3, EN, VP, VN… from the antenna end, it matches.

### Gaps
- I could not read the actual product photos or reviews on Amazon or AliExpress (Amazon pages returned only scripts or a 503), so I cannot confirm how common silkscreen errors are on this black-PCB variant beyond the one DIYables review.

## Q2. Which way must the DevKit face? What happens if it is rotated 180° or put in the wrong-width socket pair?

### Takeaway
The DevKit's pin 1 (3V3 on J2, GND on J3) must sit at the adapter's 3V3/GND end. That puts the antenna toward 3V3/GND and the **micro-USB toward the 5V/CLK end**, with the J2 side (3V3…5V) under the left column. If it is rotated 180°, every label is wrong and power goes onto signal pins.

### Cited Findings
- On the DevKitC V4, the flash pins (D0 to D3, CMD, CLK) are the pin-16 to pin-19 group next to the micro-USB connector. Pin 19 of J2 is 5V and pin 19 of J3 is CLK — [Espressif DevKitC V4 user guide](https://docs.espressif.com/projects/esp-dev-kits/en/latest/esp32/esp32-devkitc/user_guide.html)
- Espressif J2/J3 numbering starts at 3V3 (J2-1) and GND (J3-1). Those are at the module/antenna end, opposite the USB — [Espressif DevKitC V4 user guide](https://docs.espressif.com/projects/esp-dev-kits/en/latest/esp32/esp32-devkitc/user_guide.html)
- These adapters are made for "0.9 in / 1.0 in size" 38-pin boards, meaning two row spacings, which is why each side has two socket rows — [Amazon listing title, naughtystarts](https://www.amazon.com/Breakout-Terminal-Expansion-ESP-WROOM-32-ESP32-DevKitC/dp/B0BYS6THLF); [Amazon listing title, risingsaplings](https://www.amazon.com/risingsaplings-Terminal-Expansion-Compatible-ESP32-DevKitC/dp/B0C3QM5ZHP); a similar open design supports "both the wide (1") and Narrow (.8") 38 pin ESP32 dev boards" — [Home Assistant community post](https://community.home-assistant.io/t/esp32-38-pin-dev-board-terminal-breakout-for-esphome/565560)
- Listing/review, not primary: one reviewer reports that one side of the ESP32 pins does not line up with the board's sockets and that the board does not use the standard ESP32 pin width. Another says it does not fit every ESP32 board. DIYables says its adapter fits only 38-pin boards with no mounting holes and no pin names printed on top — [Amazon UK DIYables listing, search summary](https://www.amazon.co.uk/Screw-Terminal-Breakout-Board-38-pin/dp/B0CRKJX66W); [DIYables product page](https://diyables.io/products/screw-terminal-adapter-for-38-pin-esp32-board)

### Inferences
- **Rotated 180°:** J2-1 (3V3) would land under the right column's CLK terminal, J2-19 (5V) under GND, J3-1 (GND) under 5V, and so on. Powering from the adapter's 5V terminal would then short 5V to the DevKit's GND. Power from a terminal fed through the rotated board would also reach flash or IO pins. Either way there is a real risk of damage. Both the adapter and the DevKit are symmetric, so nothing mechanical stops you from inserting it backwards.
- **Wrong width:** a DevKit is one fixed width, so only one socket pair fits both rows. Forcing a board into the other pair would bend pins or leave one row unconnected. It cannot line up with the wrong pins on both sides at once. The more realistic mistake is **one row off by one position lengthwise**. Check that 19 pins are fully seated on each side and none are left over.
- Quick check after insertion: with USB power only, measure 3.3 V between the adapter's "3V3" and "GND" terminals and about 5 V (minus the diode drop) at "5V". This confirms both orientation and alignment.

### Gaps
- No primary source (the adapter has no datasheet) states the USB direction. The conclusion above follows from matching pin-1 positions.

## Q3. Do the terminal screws line up with the header sockets?

### Takeaway
No, not one-for-one in position. There are 19 terminals per side at 3.5 mm pitch (some variants use 3.81 or 3.96 mm), against 19 sockets at 2.54 mm. The terminal row is about 66 mm long and the socket row about 48 mm, so they drift apart along the board. Each label belongs to its **terminal**, and the PCB traces fan out to the matching socket.

### Cited Findings
- The DIYables 38-pin adapter uses 3.5 mm pitch terminals — [DIYables product page](https://diyables.io/products/screw-terminal-adapter-for-38-pin-esp32-board)
- Other variants are sold with 3.5 mm, 3.81 mm and 3.96 mm terminals and 2.54 mm headers — [naughtystarts 3.5 mm](https://www.amazon.com/Breakout-Terminal-Expansion-ESP-WROOM-32-ESP32-DevKitC/dp/B0BYS6THLF); [3.81 mm "Super Breakout"](https://www.amazon.com/Breakout-Terminal-Expansion-ESP-WROOM-32-ESP32-DevKitC/dp/B0BHZVRSZF); [3.96 mm wide version](https://www.amazon.com/Screw-Terminal-Breakout-38-pin-Pieces/dp/B0DYDK4LBS) (listing titles)
- "The outer connectors are the screw terminals where you would connect your external components" — [Fritzing forum](https://forum.fritzing.org/t/38-pin-screw-terminal-adapter-for-esp32/27449)

### Inferences
- The arithmetic: 18 gaps × 2.54 mm = 45.7 mm, against 18 gaps × 3.5 mm = 63 mm. The end terminals sit about 8.6 mm beyond the end sockets, so any label in the middle half of the board sits roughly 1 to 3 socket positions away from its own socket. Read the label next to the **screw**, never the one nearest a socket, and use a meter to check any terminal that matters (5V, GND, 3V3, strapping pins).
- Many of these boards also have a row of 2.54 mm male pins beside each terminal (the "GPIO 1 into 2" wording means one pin is broken out twice). Those follow the terminal numbering, not the socket numbering.

### Gaps
- I found no photo or teardown of this exact black-PCB board showing its traces. The 3.5 mm pitch comes from similar products, so measure the board in hand.

## Q4. Known variants and errors (30-pin DOIT V1 vs 38-pin; mislabeled boards)

### Takeaway
This adapter is for 38-pin DevKitC-layout boards only. A 30-pin DOIT DevKit V1 has no flash pins (SD0 to SD3, CMD, CLK), puts power in different places (VIN/GND at the USB end on one side, 3V3/GND on the other) and has a different pin order. Plugged into this adapter, it would put power and ground on the wrong terminals.

### Cited Findings
- ESP32 DEVKIT boards exist in "30, 36, and 38" pin versions — [Random Nerd Tutorials](https://randomnerdtutorials.com/getting-started-with-esp32/)
- Separate adapters exist for 30-pin boards (for example a "Green ESP32 Breakout Board… for 30-Pin") — [Tomson Electronics](https://www.tomsonelectronics.com/products/green-esp32-breakout-board-30pin-screw-terminal)
- Listing/review: "labels… all wrong", "one side misaligned", "not the standard ESP32 pin width", "does not work for all ESP32 boards" — [Amazon UK DIYables listing](https://www.amazon.co.uk/Screw-Terminal-Breakout-Board-38-pin/dp/B0CRKJX66W)
- DIYables requires 38 pins, no mounting holes and no pin names printed on top — [DIYables](https://diyables.io/products/screw-terminal-adapter-for-38-pin-esp32-board)

### Inferences
- In this case the labels do match DevKitC V4 (see Q1), so the risk lies in orientation and seating, not the silkscreen.

### Gaps
- No primary Espressif document covers the DOIT 30-pin order (DOIT is a third-party board). From memory and unverified: left side EN, VP, VN, D34, D35, D32, D33, D25, D26, D27, D14, D12, D13, GND, VIN; right side D23, D22, TX0, RX0, D21, D19, D18, D5, TX2, RX2, D4, D2, D15, GND, 3V3.

## Q5. SPI-flash pins GPIO6 to GPIO11: what happens if anything is connected?

### Takeaway
SD0, SD1, SD2, SD3, CND/CMD and CLK are the live flash bus. **Leave all six terminals unconnected.** A load, a pull, or a short to GND/3V3 on any of them corrupts flash reads. The result is boot failure such as `invalid header: 0xffffffff` loops, failed flashing, or crashes.

### Cited Findings
- "GPIO6-11 and GPIO16-17 are usually connected to the SPI flash and PSRAM integrated on the module and therefore should not be used for other purposes" — [ESP-IDF GPIO reference (ESP32)](https://docs.espressif.com/projects/esp-idf/en/stable/esp32/api-reference/peripherals/gpio.html)
- The datasheet marks these GPIOs as "allocated for communication with in-package flash/PSRAM and NOT recommended for other" use — [ESP32 Series Datasheet v5.3](https://documentation.espressif.com/esp32_datasheet_en.pdf)
- esptool: GPIO6 and GPIO11 are used for SPI flash in all modes, GPIO7/8 in dual mode, and GPIO7 to GPIO10 in quad mode; "flashing will usually fail completely if these pins are connected incorrectly" — [esptool troubleshooting](https://docs.espressif.com/projects/esptool/en/latest/esp32/troubleshooting.html)
- `invalid header: 0xffffffff` is what the ROM prints when it boots from flash and reads all 0xFF (blank or unreadable flash) — [esp-idf issue #9005 (GitHub)](https://github.com/espressif/esp-idf/issues/9005)
- RNT: GPIO6 to GPIO11 "are not recommended for other uses" and are among the pins that toggle at boot — [Random Nerd Tutorials pinout](https://randomnerdtutorials.com/esp32-pinout-reference-gpios/)

### Inferences
- `0xffffffff` means the ROM read all ones. That happens when the flash does not answer (floating MISO) or is under-powered. Loading or shorting GPIO6 to GPIO11 produces this symptom, and so does GPIO12 held high (Q6).

### Gaps
- I did not find an Espressif document that names "invalid header: 0xffffffff" as the specific symptom of loading GPIO6 to GPIO11. That link comes from community reports and inference.

## Q6. Strapping pins GPIO0, 2, 5, 12 (MTDI), 15 (MTDO): exact effects at boot

### Takeaway
The pins are sampled once at reset and latched. Defaults: GPIO0 pull-up = 1 (flash boot), GPIO2 pull-down = 0, MTDI/GPIO12 pull-down = 0 (3.3 V flash), MTDO/GPIO15 pull-up = 1 (boot log on), GPIO5 pull-up = 1 (SDIO timing). On this user's chip the VDD_SDIO eFuse is not burned, so **GPIO12 high at reset powers the flash at 1.8 V**, the flash browns out, and the chip boot-loops. GPIO15 low only silences the ROM boot log (and changes SDIO-slave timing), which is harmless for a display chip-select.

### Cited Findings
- Strapping pins and their functions: boot mode (GPIO0, GPIO2), VDD_SDIO voltage (MTDI, with the eFuses EFUSE_SDIO_FORCE/TIEH), U0TXD printing (MTDO), SDIO slave timing (MTDO, GPIO5) — [ESP32 Datasheet v5.3 §3](https://documentation.espressif.com/esp32_datasheet_en.pdf)
- Defaults (Table 3-1): GPIO0 pull-up = 1, GPIO2 pull-down = 0, MTDI pull-down = 0, MTDO pull-up = 1, GPIO5 pull-up = 1. The latches sample at reset and "the pins are freed up to be used as regular IO pins after reset". Minimum hold time is 1 ms after CHIP_PU goes high — [ESP32 Datasheet v5.3](https://documentation.espressif.com/esp32_datasheet_en.pdf)
- Boot mode: GPIO0 = 1 gives SPI (flash) boot with GPIO2 "any value". GPIO0 = 0 with GPIO2 = 0 gives download boot — [ESP32 Datasheet v5.3 Table 3-3](https://documentation.espressif.com/esp32_datasheet_en.pdf); GPIO2 must be floating or low to enter the serial bootloader — [esptool boot-mode selection](https://docs.espressif.com/projects/esptool/en/latest/esp32/advanced-topics/boot-mode-selection.html)
- "MTDI = 0 (by default), VDD_SDIO… powered directly from VDD3P3_RTC… 3.3 V"; "MTDI = 1, VDD_SDIO… powered from internal 1.8 V LDO" — [ESP32 Datasheet v5.3 §3.2](https://documentation.espressif.com/esp32_datasheet_en.pdf)
- If GPIO12 is pulled high with 3.3 V flash, "it may prevent flashing or booting due to flash brownout" — [esptool boot-mode selection](https://docs.espressif.com/projects/esptool/en/latest/esp32/advanced-topics/boot-mode-selection.html)
- Fix: `espefuse set-flash-voltage 3.3V` permanently sets VDD_SDIO to 3.3 V, after which GPIO12 is no longer a strapping pin. This is irreversible and must not be done on a 1.8 V-flash (WROVER) module — [ESP-IDF SD pull-up requirements](https://docs.espressif.com/projects/esp-idf/en/stable/esp32/api-reference/peripherals/sd_pullup_requirements.html)
- Real case (GitHub, community): a CC1101 output wired to GPIO12 held it high at boot, the flash was powered at 1.8 V, and the board boot-looped. Fixed with `espefuse set_flash_voltage 3.3V` or by moving the wire — [ESPSomfy-RTS issue #34](https://github.com/cjkas/ESPSomfy-RTS/issues/34)
- MTDO (GPIO15): 1 = U0TXD printing enabled (default), 0 = disabled; "If driven Low, silences boot messages printed by the ROM bootloader" — [ESP32 Datasheet v5.3 §3.3](https://documentation.espressif.com/esp32_datasheet_en.pdf); [esptool boot-mode selection](https://docs.espressif.com/projects/esptool/en/latest/esp32/advanced-topics/boot-mode-selection.html)
- Espressif hardware guidelines: GPIO0, GPIO2, GPIO5, MTDI and MTDO are strapping pins. Also: "Do not add high-capacitors at GPIO0, or the chip may enter download mode" — [ESP32 schematic checklist](https://docs.espressif.com/projects/esp-hardware-design-guidelines/en/latest/esp32/schematic-checklist.html)
- Conflict: RNT also lists GPIO4 as a strapping pin — [RNT](https://randomnerdtutorials.com/esp32-pinout-reference-gpios/). The Espressif datasheet and ESP-IDF list only GPIO0, 2, 5, 12 and 15 — [ESP-IDF GPIO](https://docs.espressif.com/projects/esp-idf/en/stable/esp32/api-reference/peripherals/gpio.html). Treat GPIO4 as a normal pin.

### Inferences
- For this user, anything attached to P12 that can source current at reset is the biggest hidden risk: a pull-up resistor, a module output, or a display pin driven by a separately powered display. Keep P12 unconnected, or use it only as an input from something that is guaranteed low or high-impedance at reset. Burning the 3.3 V eFuse is the permanent fix if P12 must be used.
- On a DevKitC, P0 is wired to the BOOT button and the auto-reset circuit. Anything that pulls it low at reset sends the chip into download mode ("waiting for download"). P2 must not be pulled high while flashing.
- GPIO15 low at reset: the ROM log disappears (it looks as if "TX is dead" until the app starts printing) and SDIO-slave edge timing changes. Nothing else is affected, and flash boot still works. A display CS with its own pull-up, or left undriven, keeps the default high.

### Gaps
- I did not find a primary source for the exact console text printed when GPIO12 is high on 3.3 V flash. Community reports show `invalid header: 0xffffffff` / flash read errors, but the text can vary.

## Q7. What causes random garbage characters on UART0 RX (GPIO3)?

### Takeaway
There is no single primary source for this. Espressif reserves GPIO1/GPIO3 for flashing and the console. On a DevKitC the CP2102 already drives GPIO3, so any extra wire on the RX terminal fights it or picks up noise. That wire then shows up as garbage bytes in the REPL or console input and can break flashing.

### Cited Findings
- GPIO1 (TXD) and GPIO3 (RXD) are "usually used for flashing and debugging" — [ESP-IDF GPIO reference](https://docs.espressif.com/projects/esp-idf/en/stable/esp32/api-reference/peripherals/gpio.html)
- RNT lists GPIO1 and GPIO3 among pins that output signals or go high at boot — [RNT pinout](https://randomnerdtutorials.com/esp32-pinout-reference-gpios/)
- esptool: "Download mode successfully detected, but getting no sync reply: The serial TX path seems to be down" means the host-to-ESP line, which is GPIO3/RX, is broken or overridden — [esptool troubleshooting](https://docs.espressif.com/projects/esptool/en/latest/esp32/troubleshooting.html)

### Inferences
- Likely causes, in order: (1) a device on the RX terminal driving it (TX of another module, or a display/sensor pin) and contending with the CP2102's TX; (2) a long unterminated wire on the RX terminal picking up switching noise from a fan/PWM/relay while the USB-UART is idle (the CP2102 TX holds it high, but weakly through its series path, so fast edges couple in); (3) mismatched ground between the bench supply and USB; (4) a board rotated or misaligned in the adapter so a signal lands on GPIO3. Remedy: leave TX and RX terminals unconnected.

### Gaps
- No Espressif or forum source found that specifically describes garbage input from a wire on GPIO3. The DevKitC schematic (series resistor value between CP2102 TXD and GPIO3) was not checked.

## Q8. Is SCK=14, MOSI=13, CS=15, DC=27 on HSPI safe for an SPI display?

### Takeaway
Yes, with small caveats. 13, 14 and 15 are the native HSPI IO_MUX pins (MOSI, CLK, CS0), and 27 is a plain GPIO. GPIO15 is a strapping pin, but the only effect of it being low at reset is a silent ROM log. GPIO14 toggles/outputs a signal at boot, which may show as a brief flicker. None of these pins affects flash voltage or boot mode. **Do not use GPIO12 (HSPI MISO) as a display line**, since most displays don't need MISO anyway.

### Cited Findings
- HSPI defaults: GPIO13 MOSI, GPIO12 MISO, GPIO14 CLK, GPIO15 CS — [RNT pinout](https://randomnerdtutorials.com/esp32-pinout-reference-gpios/)
- GPIO12 to GPIO15 are the JTAG pins (MTDI, MTMS, MTCK, MTDO) "usually used for inline debug" — [ESP-IDF GPIO reference](https://docs.espressif.com/projects/esp-idf/en/stable/esp32/api-reference/peripherals/gpio.html); pin functions IO14 = MTMS, IO13 = MTCK, IO15 = MTDO, IO27 = plain GPIO/ADC2_CH7/TOUCH7 — [DevKitC V4 guide](https://docs.espressif.com/projects/esp-dev-kits/en/latest/esp32/esp32-devkitc/user_guide.html)
- GPIO14 and GPIO15 "output PWM signals or go HIGH during boot"; outputs connected to them "may get unexpected results when the ESP32 resets or boots" — [RNT pinout](https://randomnerdtutorials.com/esp32-pinout-reference-gpios/)
- GPIO15 low at reset only disables ROM U0TXD printing (and sets SDIO slave timing) — [ESP32 Datasheet v5.3](https://documentation.espressif.com/esp32_datasheet_en.pdf)
- 27, 13, 14 and 15 are ADC2 channels, and ADC2 is unusable while Wi-Fi is on. That doesn't matter for digital SPI use — [DevKitC V4 guide](https://docs.espressif.com/projects/esp-dev-kits/en/latest/esp32/esp32-devkitc/user_guide.html)

### Inferences
- The only realistic GPIO15 risk is a display CS line held low by the display module at power-up. The consequence is a missing ROM boot log, not a failed boot. A 10 k pull-up on CS keeps the log and also keeps the display deselected during reset.
- GPIO14's boot-time activity can clock junk into the display while CS is high. A controller ignores it when CS is deselected, and the display is re-initialised anyway.
- Pins to leave unconnected on the bench, in order of risk: SD0, SD1, SD2, SD3, **CND (CMD)**, CLK (GPIO6 to 11, flash); **P12** (sets flash to 1.8 V on this chip); TX and RX (console/flashing); P0 (boot mode; a button only); P2 (must be low or floating for flashing); 5V and 3V3 terminals must never be fed from a bench supply while USB is also connected, unless you know the DevKit's power path. P5 and P15 are fine if nothing holds them low at reset (SDIO timing / log only). P34, P35, SVP and SVN are input-only with no internal pulls.

### Gaps
- Whether the user's display module pulls CS or DC in any direction at power-up is not covered here.
- Back-feed behaviour of the DevKitC 5V/USB power path (a diode between USB VBUS and the 5V pin) was not checked against the schematic.

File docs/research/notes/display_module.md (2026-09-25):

# SWIFT-LCD-20 (2.0" ST7789 240x320, 4-SPI) display module: fact sheet

Short answer: the module has been identified. SWIFT-LCD-20 is a NULLLAB product, and its schematic lists Emakefun as the design house. NULLLAB publishes the module on GitHub at https://github.com/nulllaborg/swift-lcd, with a README, a schematic image (drawn for the sister board SWIFT-LCD-13), a dimension drawing and ESP32 Arduino demos. Most answers below come from that repo (the primary source) and the Sitronix ST7789V datasheet. Anything that comes only from other modules or general practice is marked **[inference]**.

## Q1. Who makes/sells it; is there a datasheet, schematic or repo?

### Takeaway
SWIFT-LCD-20 is sold by NULLLAB (Amazon listings B0GVF8R5ZL for one, B0H2Y83TYG for a 2-pack). NULLLAB's GitHub repo `nulllaborg/swift-lcd` has the spec table, pinout, a KiCad schematic, a dimension drawing and ESP32 demos. The schematic's title block says "Emakefun", "SWIFT-LCD-13", Rev V0.1, dated 2025-10-23. There is no separate schematic for the 2.0" board.

### Cited Findings
- The repo covers two products: SWIFT-LCD-13 (1.3", 240x240) and SWIFT-LCD-20 (2.0", 240x320). Both use the "Standard 4-wire SPI" interface, an ST7789 driver IC, an IPS panel and an LED backlight. — [nulllaborg/swift-lcd README](https://github.com/nulllaborg/swift-lcd)
- SWIFT-LCD-20 spec: operating voltage "3.3V ~ 5V", power consumption "80mA", operating temperature -20 to 70 °C, module size "56 * 40mm, LEGO compatible". — [swift-lcd README](https://raw.githubusercontent.com/nulllaborg/swift-lcd/main/README.md)
- The repo's file tree has `picture/schematic_diagram.png`, `picture/dimension_drawing_swift_lcd_20.png` and `picture/swift_lcd_20.jpg`. Release V1.0.0 has `helloWorld.zip` and `swift_lcd_20_display_time.zip`. — [swift-lcd repo](https://github.com/nulllaborg/swift-lcd), [release V1.0.0](https://github.com/nulllaborg/swift-lcd/releases/tag/V1.0.0)
- The schematic title block reads "Emakefun / File: SWIFT-LCD-13.kicad_sch / Title: SWIFT-LCD-13 / Rev: V0.1 / Date 2025-10-23 / KiCad 8.0.3". — [schematic_diagram.png](https://github.com/nulllaborg/swift-lcd/blob/main/picture/schematic_diagram.png)
- Amazon titles:
  - Single: "NULLLAB 2.0 Inch LCD Display Module, 240x320 Full Color TFT IPS Screen, ST7789 Driver 4-Wire SPI Interface, 3.3V-5V Compatible…" — [Amazon B0GVF8R5ZL](https://www.amazon.com/NULLLAB-Interface-Compatible-Embedded-Projects/dp/B0GVF8R5ZL)
  - 2-pack: "NULLLAB 2-Pack 2.0 Inch …" — [Amazon B0H2Y83TYG](https://www.amazon.com/NULLLAB-Interface-Compatible-Embedded-Projects/dp/B0H2Y83TYG)
- Amazon listing text, as seen only in search-engine snippets: "The internal circuitry automatically pulls the RES (Reset) and BLK (Backlight Control) pins high". Module size 56 mm x 40 mm. — [Amazon B0H2Y83TYG](https://www.amazon.com/NULLLAB-Interface-Compatible-Embedded-Projects/dp/B0H2Y83TYG) (the page body did not render when fetched)
- NULLLAB's GitHub org (`nulllaborg`) also hosts other maker modules, such as maker-esp32 and a 4-digit clock display. — [github.com/nulllaborg](https://github.com/nulllaborg)
- For MicroPython, the README only links to Adafruit_CircuitPython_ST7789, which is a displayio driver. It does not supply a MicroPython driver of its own. — [swift-lcd README](https://github.com/nulllaborg/swift-lcd)

### Inferences
- The schematic is labelled for the 1.3" board. The 2.0" board very likely uses the same circuit: same LDO, same backlight MOSFET and same 6-pin interface. The README gives the two boards the same pin table, voltage and "RES/BLK pulled high" note, and your photos show the same connector and pad sets. The part values on your board (103, 102, 01X) are not all on the 1.3" schematic, so the resistor values probably differ.
- NULLLAB seems to be the brand and Emakefun the design house.

### Gaps
- There is no schematic specific to SWIFT-LCD-20 and no bare-panel datasheet (for example which FPC panel is used, or the backlight LED current).
- Amazon Q&A and reviews could not be retrieved; the page body did not render.

## Q2. Pinout and connectors

### Takeaway
Six signals: G, V, SCL (SPI clock), SDA (MOSI), DC, CS (active low). The same signals appear on three footprints: a 6-pin GH1.25 connector, a 6-pin 0.1" through-hole row, and a 2x3 pad block. The README says GH1.25 (1.25 mm pitch). The cable is described two ways: GH1.25-to-PH2.0 (README) or GH1.25-to-Dupont (Amazon).

### Cited Findings
- Pin table: G = Ground; V = Power Supply (3.3V ~ 5V); SCL = Serial Clock; SDA = "SPI Data Input/Output"; DC = Data/Command; CS = Chip Select (Active Low). — [swift-lcd README](https://github.com/nulllaborg/swift-lcd)
- Schematic, J1 "Conn_01x06_Pin": 1 GND, 2 VIN, 3 LCD_SCLK, 4 LCD_SDA, 5 LCD_DC, 6 LCD_CS. J2 "Conn_01x06_Pin-PZ/NC" has the same order and is marked optional/NC. J3 "Conn_02x03 NC": 1 CS / 2 SDA, 3 DC / 4 SCLK, 5 GND / 6 VIN. — [schematic](https://github.com/nulllaborg/swift-lcd/blob/main/picture/schematic_diagram.png)
- README: "Interface: GH1.25 pitch connector". "Connection Method: GH1.25 to PH2.0 6-pin anti-reverse cable". — [swift-lcd README](https://raw.githubusercontent.com/nulllaborg/swift-lcd/main/README.md)
- The Amazon text in search snippets says it "includes a GH1.25 interface and comes with a GH1.25 to Dupont 6-pin anti-reverse cable". — [Amazon B0H2Y83TYG](https://www.amazon.com/NULLLAB-Interface-Compatible-Embedded-Projects/dp/B0H2Y83TYG). This conflicts with the README (PH2.0 vs Dupont on the far end).
- Dimension drawing: board 56 x 40 mm. There are two groups of three pads (square pad = pin 1) along one 40 mm edge, with mounting holes 30 mm apart, 2.5 mm from the edge. — [dimension_drawing_swift_lcd_20.png](https://github.com/nulllaborg/swift-lcd/blob/main/picture/dimension_drawing_swift_lcd_20.png)
- Example ESP32 wiring from the vendor: CS→GPIO14, DC→GPIO15, SDA→GPIO16, SCL→GPIO17, V→5V, G→GND. — [swift-lcd README](https://github.com/nulllaborg/swift-lcd)

### Inferences
- The connector order you photographed (CS, DC, SDA, SCL, V, G) is J1 read from pin 6 back to pin 1. The through-hole split (G/V/SCL on one side, SDA/DC/CS on the other) matches the two 3-pad groups in the dimension drawing.
- The pin is labelled "SDA", but it is a write-only MOSI input to the ST7789. MISO is not needed.

### Gaps
- The exact connector part (JST GH vs a GH-compatible clone) is not stated. Check the pitch with calipers: 1.25 mm for GH, 1.0 mm for SH, 2.0 mm for PH.

## Q3. Supply voltage, regulator and 5 V logic tolerance

### Takeaway
V accepts 3.3 to 5 V. It feeds a Torex XC6206P332MR ("662K") 3.3 V LDO that powers the panel and backlight. The SPI/DC/CS lines go straight to the ST7789 with no level shifter, so the logic is 3.3 V only and is not 5 V tolerant. That is fine for an ESP32.

### Cited Findings
- The schematic power section is titled "Power VIN->3.3V". U1 is "662k(HXY)" (VDD=VIN, VOUT=3V3), with 10 µF/10 V capacitors on input and output. — [schematic](https://github.com/nulllaborg/swift-lcd/blob/main/picture/schematic_diagram.png)
- The "662K" marking is the XC6206P332MR: 3.3 V output, maximum input 6 V, dropout about 250 mV, 200 mA. — [Sunrom XC6206P332MR (662K)](https://www.sunrom.com/p/xc6206p332mr-662k), [iFuture](https://ifuturetech.org/product/xc6206p332mr-662k-xc6206-3-3v-0-5a-sot-23/)
- The schematic wires LCD_SCLK, LCD_SDA, LCD_DC and LCD_CS directly from the connectors to FPC U3 pins 9, 10, 7 and 8. No buffers or dividers are drawn. — [schematic](https://github.com/nulllaborg/swift-lcd/blob/main/picture/schematic_diagram.png)
- ST7789V absolute maximums: VDD and VDDI -0.3 to +4.6 V. Logic input voltage -0.3 to VDDI + 0.5 V. Recommended VDD is 2.4 to 3.3 V and VDDI is 1.65 to 3.3 V. — [ST7789V datasheet v1.3 (Newhaven mirror)](https://newhavendisplay.com/content/datasheets/ST7789V.pdf)
- Power consumption spec: 80 mA. — [swift-lcd README](https://github.com/nulllaborg/swift-lcd)

### Inferences
- **[inference]** "3.3V-5V compatible" in the listing applies to the supply only. Driving the pins from a 5 V MCU would put about 5 V on inputs rated to about 3.8 V (VDDI 3.3 + 0.5), which is out of spec. ESP32 3.3 V GPIO is correct.
- **[inference]** With V = 3.3 V, the rail after the LDO drops by roughly 0.1 to 0.25 V (dropout at ~80 mA), to about 3.05 to 3.2 V. That is still inside the ST7789's VDD range. Feeding 5 V gives a clean 3.3 V rail, and that is what the vendor example does. The 80 mA figure is mostly backlight.

### Gaps
- There is no measured current at 3.3 V vs 5 V input.

## Q4. Internal tie-offs: reset and backlight

### Takeaway
RES has a 2 kΩ pull-up to 3V3 and no capacitor is drawn, so it is not an RC reset. The panel relies on the ST7789's own power-on reset. Software should send SWRESET (0x01) and wait at least 5 ms (120 ms is conventional). The backlight is switched by a P-MOSFET (AO3401A) whose gate is tied to GND through a 0 Ω resistor, so it is always on at full brightness. A 10 Ω resistor limits LED current on the cathode side. Software cannot control brightness.

### Cited Findings
- Schematic, reset: LCD_RST (FPC pin 11 "RES") connects to 3V3 through R3 = 2K. No capacitor is shown on that net. — [schematic](https://github.com/nulllaborg/swift-lcd/blob/main/picture/schematic_diagram.png)
- Schematic, backlight: U2 AO3401A (P-channel). S goes to 3V3 and D goes to LED_A (FPC pin 3, LEDA). Gate net LCD_BL has R1 = 0R to GND and R2 = "0R/NC" to 3V3; R2 is not fitted. LED_K (FPC pin 2) goes through R4 = 10R to GND. R5 "10R/NC" is an optional bypass from 3V3 to LEDA. — [schematic](https://github.com/nulllaborg/swift-lcd/blob/main/picture/schematic_diagram.png)
- README: "The RES (Reset) and BLK (Backlight) pins are internally pulled high and do not require external wiring." — [swift-lcd README](https://github.com/nulllaborg/swift-lcd)
- ST7789V hardware reset: the reset pulse must be at least 10 µs. The datasheet says "It is necessary to wait 5msec after releasing RESX before sending commands. Also Sleep Out command cannot be sent for 120msec." — [ST7789V datasheet §7.4.5](https://newhavendisplay.com/content/datasheets/ST7789V.pdf)
- ST7789V SWRESET (01h): "It will be necessary to wait 5msec before sending new command following software reset… If software reset is sent during sleep in mode, it will be necessary to wait 120msec before sending sleep out command." — [ST7789V datasheet §9.1.2](https://newhavendisplay.com/content/datasheets/ST7789V.pdf)
- The vendor's 2.0" demo uses Arduino_GFX with rst = -1. In that library, `tftInit()` always sends `ST7789_SWRESET` followed by `delay(120)`, and pulses RST only when a pin is defined. — [demo swift_lcd_20_display_time.zip](https://github.com/nulllaborg/swift-lcd/releases/download/V1.0.0/swift_lcd_20_display_time.zip), [Arduino_ST7789.cpp](https://github.com/moononournation/Arduino_GFX/blob/master/src/display/Arduino_ST7789.cpp)

### Inferences
- The "BLK pulled high" wording in the marketing text is loose. In the schematic the backlight is simply always on (the PMOS gate is grounded). Full brightness is the only mode unless you rework R1/R2.
- **[inference]** The "01X" resistor you saw is probably EIA-96 code 01 (100) with multiplier X (0.1), which gives 10 Ω. That matches R4 = 10R. 103 = 10 kΩ and 102 = 1 kΩ are likely the reset pull-up and/or MOSFET gate parts. The 2.0" board may use 10k or 1k instead of the 2K on the 1.3" schematic. The SOT-23 parts you saw would be the 662K LDO and the AO3401A.
- **[inference]** In MicroPython, pass `reset=None` (st7789py and russhughes drivers accept this). Call `soft_reset()`/SWRESET and sleep ≥120 ms, then send SLPOUT (0x11) and wait 120 ms before further init. If the ESP32 reboots without cycling power, the panel keeps its old state, which is another reason SWRESET is required.

### Gaps
- Whether the 2.0" board fits a capacitor on RES is not documented.

## Q5. SPI mode and clock speed

### Takeaway
The ST7789 samples SDA on the rising edge of SCL. With a real CS line, "at the falling edge of CSX, SCL can be high or low", so SPI mode 0 and mode 3 both work. The vendor demos use mode 0 (Adafruit default) and Arduino_GFX defaults. The datasheet write-cycle minimum is 66 ns, about 15 MHz. Much faster clocks are common in practice but are out of spec.
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

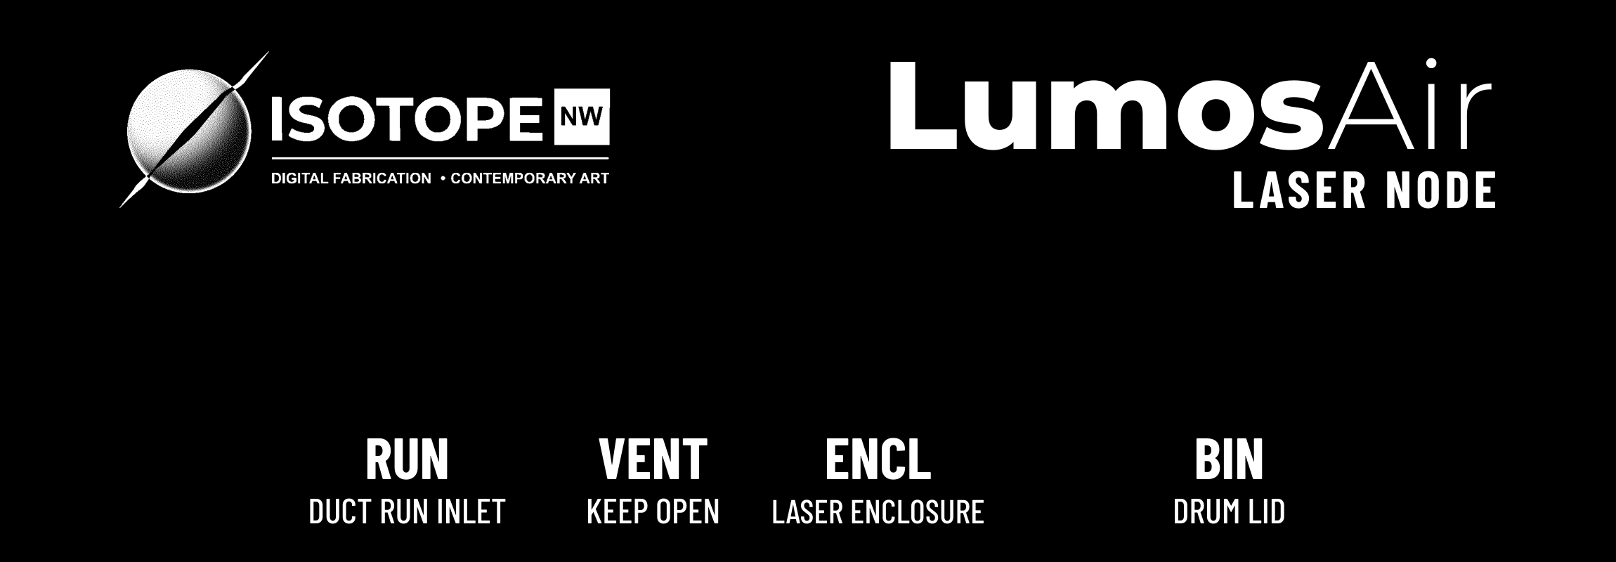
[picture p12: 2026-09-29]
docs/3D Models/Project/textures/mark_laser_node_MX.png

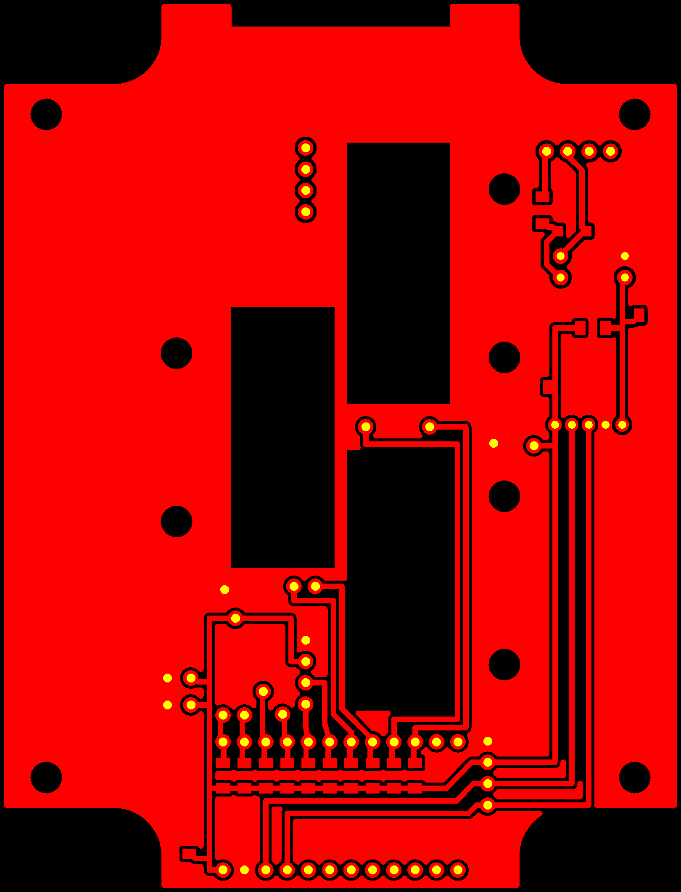
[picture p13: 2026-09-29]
docs/3D Models/Project/textures/pcb_revB_bottom_mask.png

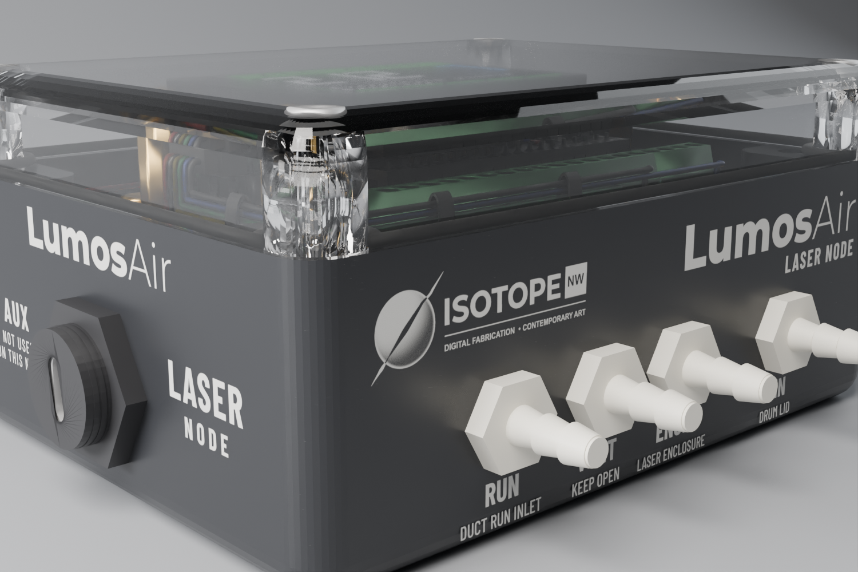
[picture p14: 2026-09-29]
docs/3D Models/Project/renders/markings_B_MX_ANT.png

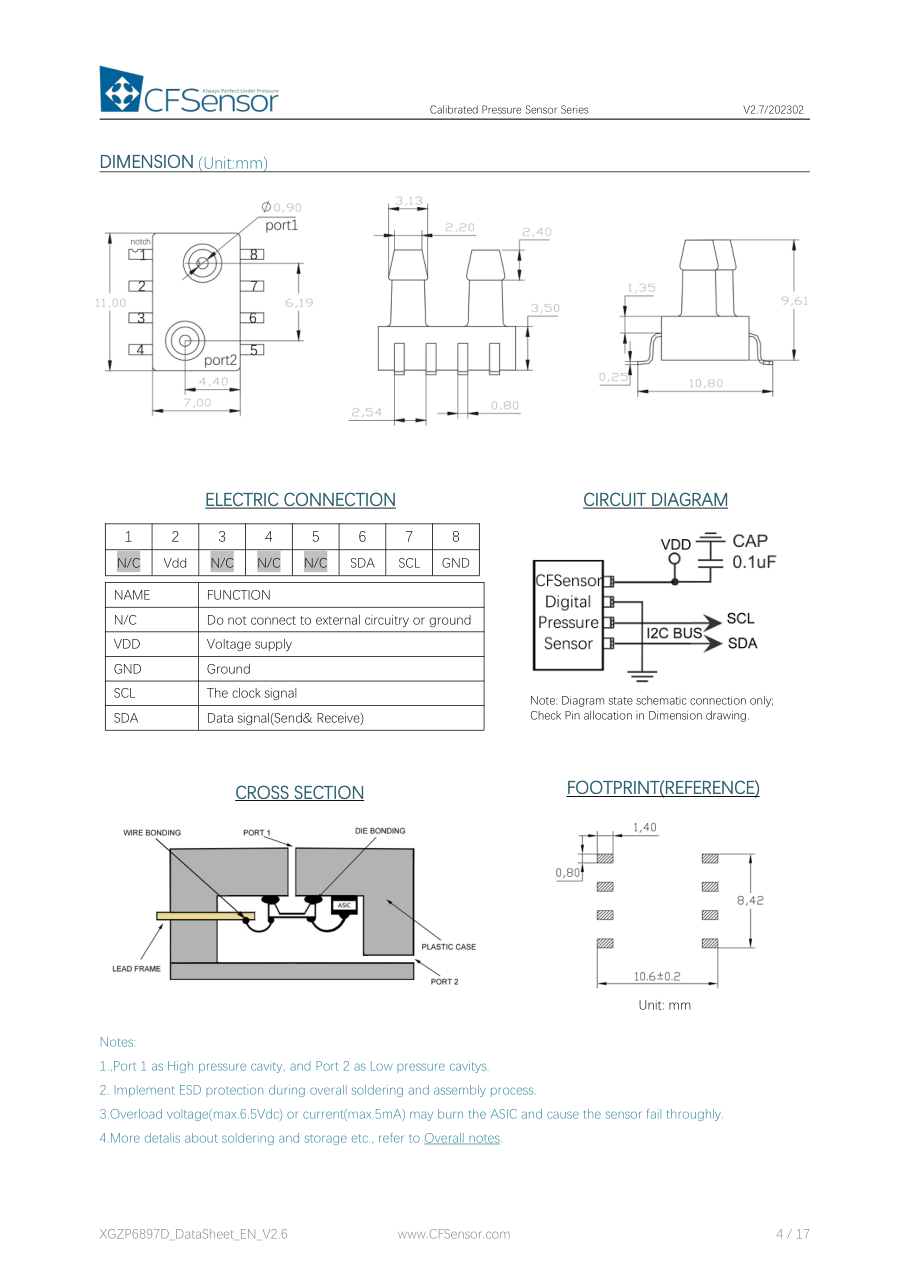
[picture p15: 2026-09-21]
docs/datasheets/XGZP6897D_dimensions.png

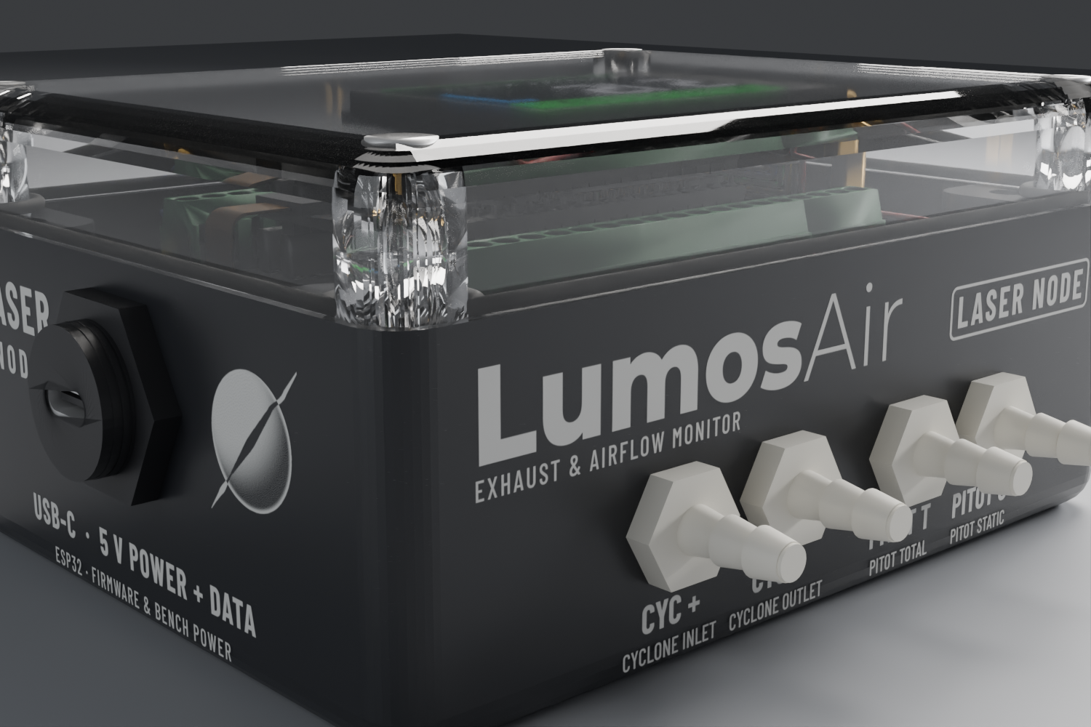
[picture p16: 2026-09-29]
docs/3D Models/Project/renders/markings_A_PX_USB.png

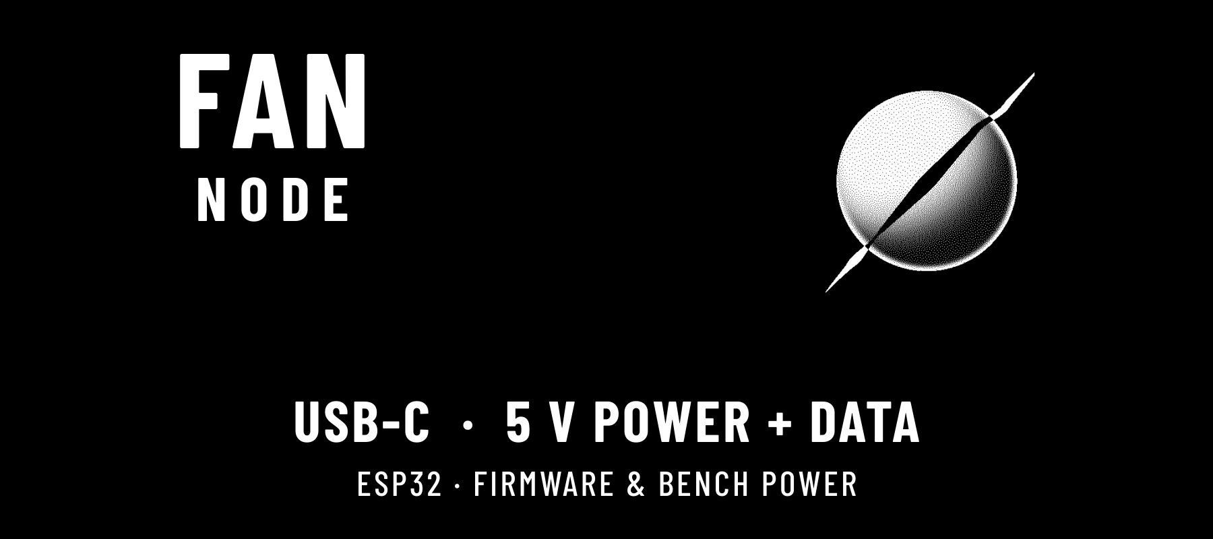
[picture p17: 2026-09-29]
docs/3D Models/Project/textures/mark_fan_node_USB.png

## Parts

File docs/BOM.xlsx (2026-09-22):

Item | Qty | Sourced? | Ordered? | Deleted | Where used | Approx unit price USD (Sept 2026 - verify) | Dimensions (mm) | Datasheet / drawing | 3D model | Notes
ESP32-WROOM-32 DevKit V1 (DOIT 30-pin) | 2 | Y |  | X | laser node + fan node | 3.75 | 52 x 28 x ~13 with headers (2 rows of 15 pins) | https://www.espboards.dev/esp32/esp32doit-devkit-v1/ | STEP + F3D: https://www.printables.com/model/1362332-esp32-devkit-v1-board-30-pin | Superseded by the soldered ESP32-WROOM-32E on PCB-B: a socketed DevKit is 13 mm tall and only fits the 20 mm taller 1554G. Firmware target board = esp32dev. Buy DevKit + expansion board as a matched 30-pin pair (row spacing varies between clones)
ESP32 30-pin screw-terminal expansion board (Handson MDU1156 type) | 2 | Y |  | X | laser node + fan node | 3.75 | 65 x 55 x ~20 with DevKit fitted; M3 mounting holes on 60 x 50 | docs/datasheets/Handson_ESP32_30pin_Expansion_Board_MDU1156.pdf | Thangs (community): https://thangs.com/designer/ZackFreedman/3d-model/ESP32%2030-Pin%20Devkit%20V1%20Expansion%20Board%20Enclosure%20Thingy-947443 | Superseded by PCB-B, the custom processor board. DC jack 7-12 V in -> onboard 5 V/1 A regulator: the fan's 10 V rail plugs straight in (no separate buck). Also USB-C / micro-USB power
2.0 Inch LCD Display Module, 240x320 Full Color TFT IPS Screen | 2 | Y |  |  | laser node + fan node | 8.99
Sensirion SDP810-500Pa | 6 | Y |  |  | cyc_dp, pitot, encl - 3 per box, both boxes populated identically | 15.62 | 29 x 18 body; 24 tall incl. barbs; barbs 5.2 OD / 12.6 apart; 4 pins at 2.0 pitch; 2x M2.5 holes 24 apart | docs/datasheets/Sensirion_SDP8xx_Digital_Datasheet_v1.1.pdf (drawing p.11; docs/datasheets/SDP810_dimensions.png) | STEP: https://sensirion.com/products/catalog/SDP810-500Pa (Downloads) or https://www.snapeda.com/parts/SDP810-500PA/Sensirion%20AG/view-part/ | I2C 0x25; 2.7-5.5 V; 3 % of reading + 0.1 Pa zero; bare sensor, pins are 2.0 mm pitch (not 2.54) - mount on Sensirion's SDP800 cap/cable or a small adapter board. 3/16in ID silicone fits the barbs. DigiKey 6605489
CFSensor XGZP6897D +/-1 kPa I2C (part no. XGZP6897D001KPDPN) | 4 | Y | Y |  | bin, run_in - 2 per box, both boxes populated identically | 11.98 | SOP8 body 11.0 x 7.0; 9.6 tall incl. barbs; barbs 2.2 OD / 6.19 apart; gull-wing leads 2.54 pitch | docs/datasheets/CFSensor_XGZP6897D_Datasheet_v2.7.pdf (drawing p.4; docs/datasheets/XGZP6897D_dimensions.png) | No manufacturer STEP - model from the p.4 drawing if needed | I2C 0x6D; 2.5-5.5 V; +/-2.5 % FS; K=4096 for 1 kPa range. Barbs are only 2.2 mm: use 2 mm ID silicone at the sensor and a barbed reducer to the 3/16in run. Easiest to buy pre-mounted on a breakout module (search 'XGZP6897D module'); module boards are ~20 x 15
TCA9548A I2C multiplexer breakout (Adafruit 2717) | 1 | Y |  | X | laser node | 1.67 | 30.6 x 17.6 x 2.7 | https://learn.adafruit.com/adafruit-tca9548a-1-to-8-i2c-multiplexer-breakout/downloads | EAGLE + 3D in Adafruit CAD repos linked from the downloads page | Superseded by the bare TCA9548A (TSSOP-24) soldered to PCB-B. Needed because all XGZP share 0x6D. 8 ports = room for 3 more channels later
BME280 breakout (Adafruit 2652 or GY-BME280 clone) | 1 | Y |  | X | laser node | 6.33 | 25.2 x 18.0 x 4.6 (Adafruit); ~15 x 12 (GY clone) | https://learn.adafruit.com/adafruit-bme280-humidity-barometric-pressure-temperature-sensor-breakout/downloads | Adafruit CAD repos linked from the downloads page | Superseded by the bare BME280 (LGA) soldered to PCB-B. Air density correction. On the main bus (not behind the mux)
PC817 optocoupler (or 2N7000 N-MOSFET) + 330 ohm resistor | 2 | Y |  |  | fan drive on PCB-B, fitted in both boxes | 0.16 | DIP-4 7.6 x 4.6 x 3.5 (PC817); TO-92 (2N7000) | any PC817 / 2N7000 datasheet | generic DIP-4 / TO-92 | Output transistor pulls the fan's PWM line (pulled up to 10 V inside the fan) to ground. Off = fan full speed (verify on your unit). Mount on a 20 x 20 scrap of perfboard
5.5 x 2.1 mm DC barrel plug (centre positive) on the fan pigtail | 1 |  |  |  | fan node power | 1.00 | - | - | - | Crimp/solder to the +10 V and GND wires of the cut UIS cable; plugs into the expansion board's DC jack
AC Infinity UIS cable (genuine; controller cable or UIS extension) | 1 |  |  |  | fan node pigtail | 10-15 | - | - | - | Cut one end; the UIS plug end goes into the S6. Standard USB-C cables do NOT work (tested). 3 wires used: +10 V, GND, PWM
Dwyer 166-6-CF pitot-static tube (1/8in dia x 6in insertion / 3in tip / 1/8in NPT compression fitting) | 1 |  |  |  | 4-inch measuring section | 60-90 | 1/8in (3.2) tube; 6in insertion; 3in tip; fitting 1/8in NPT | docs/datasheets/Dwyer_166_pitot_drawing.pdf | - | ASHRAE tip = calibration factor 1. Compression fitting sets depth (centreline = 2in in 4in duct) and seals the hole. Two 1/8in barbs for total/static tubes
Hammond 1554H2GYCL enclosure (polycarbonate / clear lid / IP68) | 2 |  |  | X | laser node + fan node | 20-28 | 180 x 120 x 61 outside; 167 x 107 x 54.5 inside; M3 inserts for optional 1554HPL steel panel | docs/datasheets/Hammond_1554H2GYCL_drawing.pdf | docs/datasheets/Hammond_1554H2GYCL_STEP.zip (also x_t / DXF at https://www.hammfg.com/part/1554H2GYCL) | Superseded by the 1554F2GYCL: the stacked two-board layout halved the footprint to 120 x 90. Identical box for both nodes. Plastic (Wi-Fi). Cheaper no-CAD alternative: generic 150 x 100 x 70 ABS clear-lid junction box (LeMotech etc.) ~$10
PG7 nylon cable glands (3-6.5 mm cable) | 2 | Y |  |  | USB cable / fan pigtail / tubing entry | 0.32 | 12.5 mm panel hole; ~15 hex | - | - | 1 per box for the cable; optionally pass silicone tubes through PG7 glands instead of panel barbs
Bulkhead hose barb 3/16in (through-wall / nylon or brass) OR 1/8in NPT bulkhead + barb | 16 | Y |  |  | 8 bulkheads per box, both boxes drilled identically; unused ones take blanking plugs | 2.33 | ~8 mm panel hole (verify for chosen part) | - | - | Panel side: 3/16in tube from the duct. Inside: short 3/16in tube to the SDP810, or 3/16in->2 mm barbed reducer + 2 mm ID tube to each XGZP
Barbed reducer 3/16in -> 1/16in (2 mm) | 4 | Y |  |  | inside the boxes, one per XGZP - 2 per box | <1 | - | - | -
Silicone tubing 3/16in ID x 5/16in OD / 10 m / box to duct taps (zip-tied along duct) | 10 | Y |  |  | - | - | - | Top-of-duct taps; no low points
Silicone tubing 2 mm ID / m / inside boxes to XGZP barbs | 3 | Y |  |  | - | - | -
Duct tap barbs 1/8in hole (3/16in hose barb x 1/8in NPT or printed saddle) + epoxy/RTV | 4 |  |  |  | laser_out, post_cyc, fan_in, fan_out taps | 1-3 | - | - | - | Drill square to the wall and deburr inside
1/8in NPT bulkhead barb + nut + rubber washer | 1 |  |  |  | drum lid (bin tap) | 3.00 | - | - | - | Lid is opened to empty the drum - no glue
4-inch rigid metal pipe 2-3 ft + couplers + foil tape | 1 |  |  |  | pitot + post_cyc tap section before the 4->6 adapter | 15-25 | - | - | - | Ground it
6-inch rigid metal sleeve 12in + 2 clamps | 1 |  |  |  | fan_in tap ~6 ft before the fan (spliced into the 6in flex) | 10.00 | - | - | - | A tap in corrugated flex reads badly
USB-A to micro-USB (or USB-C) cable 6 ft | 1 |  |  |  | laser node power from PC | 5.00 | - | - | - | Match the DevKit's connector
Open-cell foam scrap + 3 mm vent hole | 2 |  |  | X | room-pressure reference vent per box | 0.00 | - | - | - | Superseded by the dedicated VENT bulkhead, which is the room-pressure reference for the bin, run and enclosure channels. Boxes must NOT be airtight
Cyclone separator (steel) + sealed 20-30 gal drum | 1 |  |  |  | separator | 400-600 | - | - | - | See DESIGN.md section 4 before choosing
ESP32-WROOM-32E module (bare, soldered to PCB-B) | 2 |  |  |  | laser node + fan node | 3-5 | 18 x 25.5 x 3.1 | https://www.espressif.com/sites/default/files/documentation/esp32-wroom-32e_esp32-wroom-32ue_datasheet_en.pdf | Espressif provides a STEP for the module | Replaces the DevKit. Has no USB, so programming and 5 V come from the USB-serial breakout below.
USB-C breakout + USB-serial (CP2102 or CH340) for flashing and 5 V | 2 |  |  |  | PCB-B programming header | 4-8 | ~15 x 13 (breakout) | - | docs/3D Models/usb_c_breakout_board_approx.obj | Needed because the bare module has no USB. Only for flashing; OTA after that.
Custom PCB-A (sensors) + PCB-B (processor), 2-layer, 105 x 41 mm | 4 |  |  |  | one pair per node | 2.4 | 105 x 41 x 1.6 each | cad/out/pcb_a_outline.dxf, cad/out/pcb_b_outline.dxf | generated from cad/enclosure.py | Board outline + M3 holes come out of the CAD model. 10 boards for two 5-off orders; 4 used.
TCA9548A I2C multiplexer, bare (TSSOP-24) | 2 |  |  |  | PCB-B, one per box | 1.50-3 | 7.8 x 6.4 x 1.2 | https://www.ti.com/lit/ds/symlink/tca9548a.pdf | TI provides a STEP | Needed because every XGZP shares address 0x6D.
BME280 sensor, bare (LGA) | 2 |  |  |  | PCB-B, both nodes | 2-4 | 2.5 x 2.5 x 0.93 | https://www.bosch-sensortec.com/products/environmental-sensors/humidity-sensors-bme280/ | Bosch provides a STEP | Air density correction. Keep it away from the ESP32 to avoid self-heating.
Hammond 1554F2GYCL enclosure (polycarbonate / clear lid / IP68) | 2 |  |  |  | laser node + fan node | 20-28 | 120 x 90 x 60.5 outside; ~113 x 79 x 54.5 inside | Hammond 1554 series drawing | Hammond provides STEP per size | Identical box for both nodes, built and populated the same; the node works out its role from which taps and power are connected. Clear lid means the display needs no cut-out.
90 deg push-on barbed elbow, 3/16in | 14 |  |  |  | one per sensor port on PCB-A - 7 per box | 0.799 | ~12 arm; fits the 5.2 mm SDP810 barb | - | - | Turns each hose at the sensor so it runs almost straight to the wall. Without these the box needs 25 mm more height - see cad/enclosure.py --compare.
12 mm illuminated latching push button (anti-vandal) | 2 |  |  |  | front panel power switch, one per box | 5.995 | 12 mm panel hole; ~15 body dia x 22 long | - | - | The ring is the power-on indicator, so there is no separate LED to drill for.
M3 standoff / spacer / screw kit (brass, assorted) | 1 |  |  |  | PCB-A to floor, PCB-B above it, display on PCB-B | 10-15 | 4 mm under PCB-A; ~28 mm PCB-A to PCB-B; 6 mm under the display | - | - | Heights come from the fitment report, cad/out/fitment_report_laser.txt.
Blanking plugs for unused bulkheads | 10 |  |  |  | any bulkhead with no duct tap on it | 0.699 | to suit the 8 mm bulkhead | - | - | Both boxes are drilled and populated identically; each plugs the ports its location does not use. VENT always stays open.

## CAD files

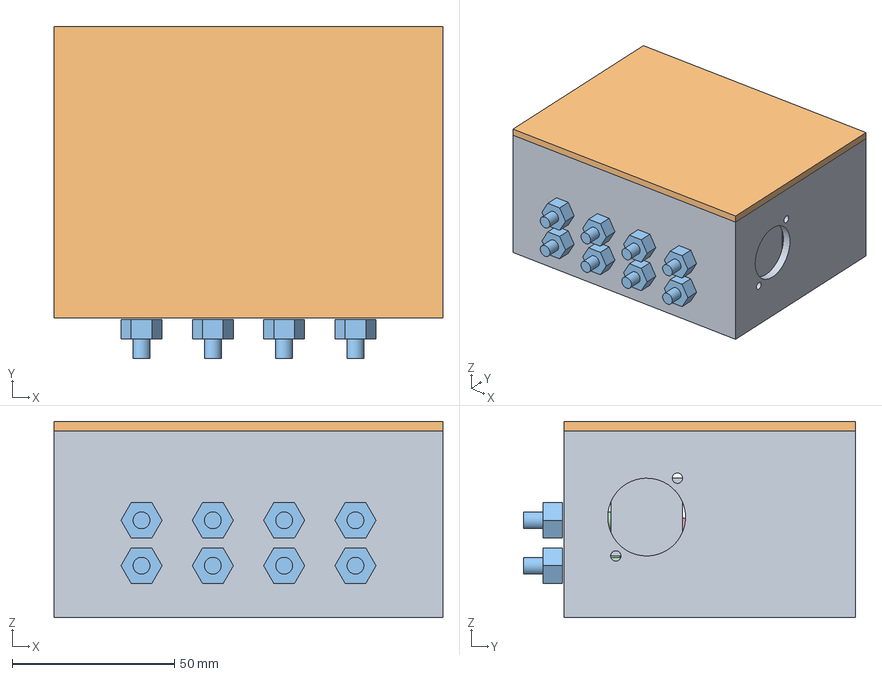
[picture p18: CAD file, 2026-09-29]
cad/out/lumosair_laser_F_module.step
120.0 x 102.5 x 60.5 mm

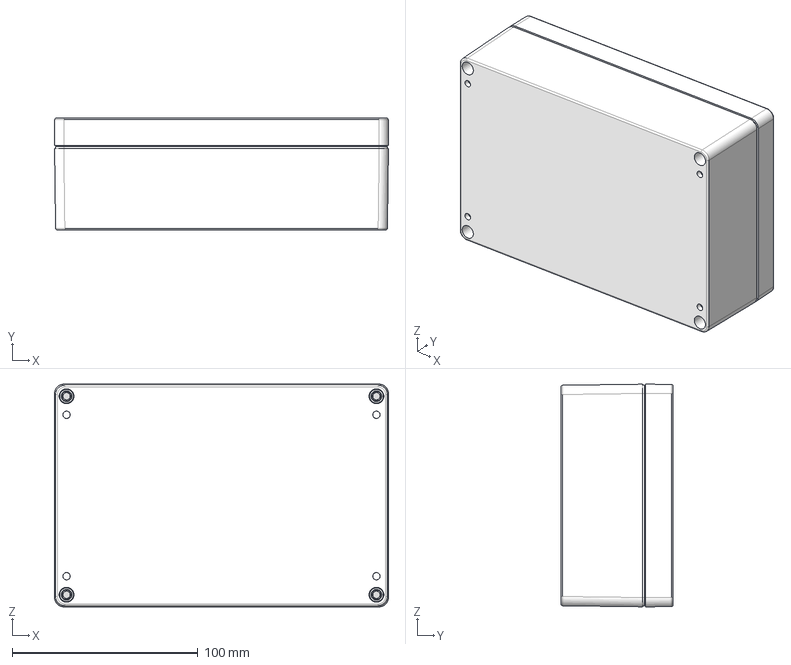
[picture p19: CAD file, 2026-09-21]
docs/datasheets/Hammond_1554H2GYCL_STEP/1554H.stp
180.0 x 60.5 x 120.0 mm
1554H Box
1554H-T Lid
1554H-T GASKET
SC576 (screw M4-0.7X 20mm PN) x 4
IN-M4 (insert M4-0.7X5.75mm SS) x 4
IN100 (insert M3-0.5X5.75mm BRASS) x 4

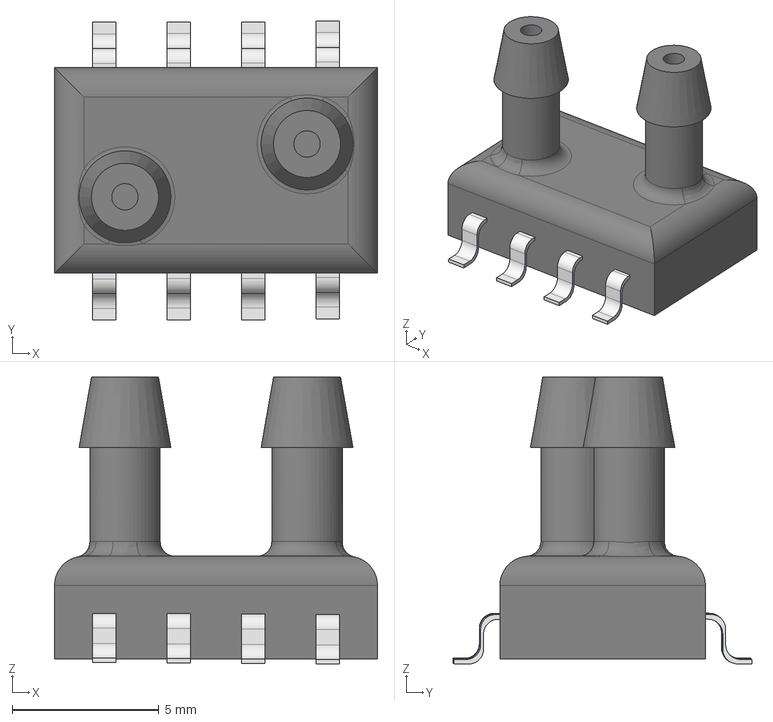
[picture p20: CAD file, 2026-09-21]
docs/datasheets/xgzp6897d-1.snapshot.1/XGZP-2.stp
11.0 x 10.2 x 9.77 mm

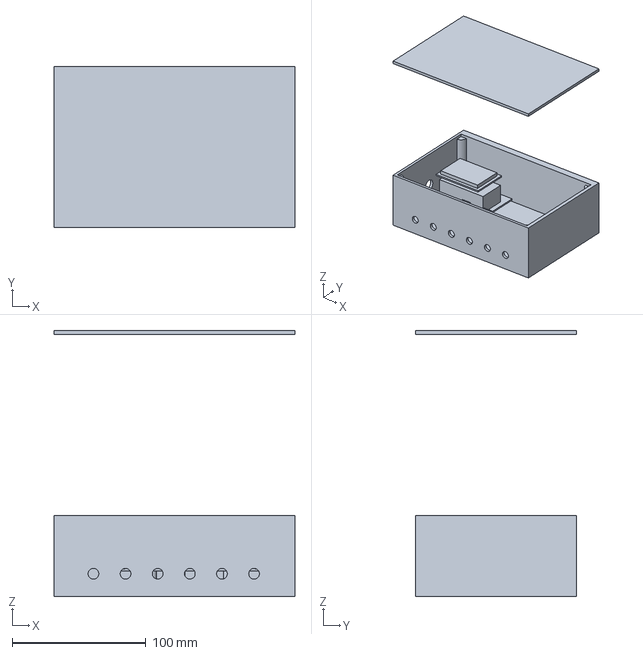
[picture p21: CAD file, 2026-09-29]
cad/out/LumosAir node.3mf
180.0 x 120.0 x 198.7 mm

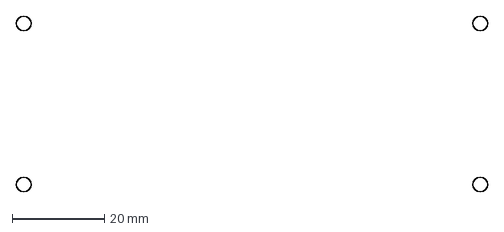
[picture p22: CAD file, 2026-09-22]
cad/out/pcb_a_outline.dxf
102.1 x 38.1 mm

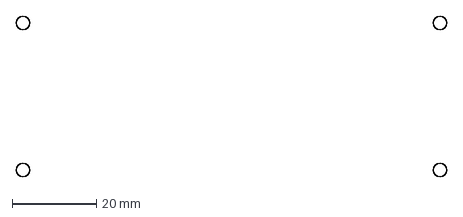
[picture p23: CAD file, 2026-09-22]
cad/out/pcb_b_outline.dxf
102.1 x 38.1 mm

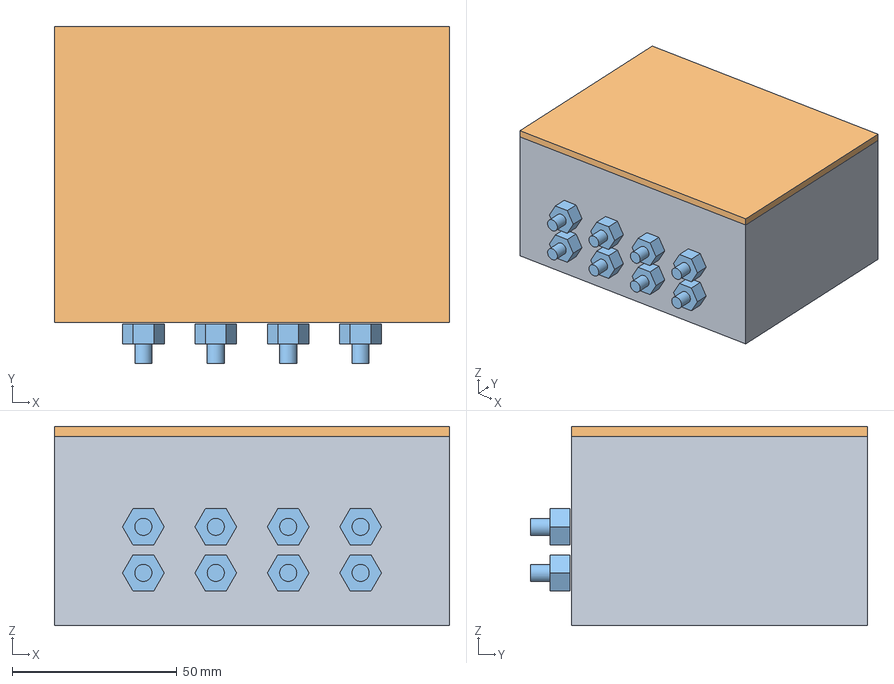
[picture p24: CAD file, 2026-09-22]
cad/out/lumosair_fan_F_module.step
120.0 x 102.5 x 60.5 mm

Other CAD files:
cad/out/lumosair_fan_F_module.stl
cad/out/lumosair_laser_F_module.stl
docs/3D Models/Project/Node - restored 2026-09-28.blend
docs/3D Models/Project/Node - sensor bay backup 2026-09-29.blend
docs/3D Models/Project/Node.blend
docs/3D Models/Project/Node_explode.blend
docs/3D Models/Project/Node_video.blend
docs/datasheets/Hammond_1554H2GYCL_STEP/1554H.3mf
docs/datasheets/Hammond_1554H2GYCL_STEP/1554H.igs

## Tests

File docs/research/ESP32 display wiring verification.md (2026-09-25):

# Wire the screw terminals, never the sockets

The silkscreen on the "FOR ESP32 TERMINAL ADAPTER" is **correct**. Both columns copy Espressif's ESP32-DevKitC V4 J2/J3 header order pin for pin, and the odd "CND" label is a misprint of **CMD (GPIO11, a live SPI-flash line), not ground**. The labels only hold if you meet three conditions. First, the DevKit must sit the right way round, with the antenna at the 3V3/GND end and micro-USB at the 5V/CLK end. Second, you must read each label against its **screw terminal**, not the header socket nearest it. Third, the six flash pins (SD0 to SD3, CND, CLK) and P12 must stay unconnected. Your two symptoms fit that picture. `invalid header: 0xffffffff` means the ROM read blank or unreadable flash, which is what a wire on GPIO6 to GPIO11 or on GPIO12 produces. Garbage on UART RX means something is driving or picking up noise on GPIO3. Both point to display wires landing in the wrong header sockets, because the 3.5 mm terminal row and the 2.54 mm socket row drift one to three positions apart along the board. The display is the NULLLAB/Emakefun SWIFT-LCD-20. Its vendor schematic confirms a six-pin G, V, SCL, SDA, DC, CS interface, an on-board 3.3 V LDO, reset and backlight tied off internally, and 3.3 V-only logic. Your firmware's pins (SCK 14, MOSI 13, CS 15, DC 27) are safe. The pigtail colour mapping is **plausible but undocumented**: the pin order matches the schematic, but no source publishes wire colours, so confirm it with a meter before you power up.

## The adapter labels are right, but position and orientation are not guaranteed

Espressif's DevKitC V4 guide lists J2 as 3V3, EN, VP, VN, IO34, IO35, IO32, IO33, IO25, IO26, IO27, IO14, IO12, GND, IO13, D2, D3, CMD, 5V. It lists J3 as GND, IO23, IO22, TX, RX, IO21, GND, IO19, IO18, IO5, IO17, IO16, IO4, IO0, IO2, IO15, D1, D0, CLK ([Espressif DevKitC V4](https://docs.espressif.com/projects/esp-dev-kits/en/latest/esp32/esp32-devkitc/user_guide.html)). The adapter's left column (3V3, EN, SVP, SVN, P34 … P13, SD2, SD3, CND, 5V) and right column (GND, P23, P22, TX, RX … P15, SD1, SD0, CLK) follow that order exactly. The only grounds on the board are left pin 14 and right pins 1 and 7, so **CND is GPIO11**. Tying it to ground holds the flash command line low and the chip cannot boot. One Amazon reviewer of a similar DIYables adapter says "the labels… are all wrong" ([Amazon UK](https://www.amazon.co.uk/Screw-Terminal-Breakout-Board-38-pin/dp/B0CRKJX66W)). For this board the labels themselves check out, so that complaint more likely reflects the two traps below.

**Orientation.** J2-1 (3V3) and J3-1 (GND) sit at the antenna end, and the flash pins and 5V/CLK sit next to the micro-USB ([Espressif](https://docs.espressif.com/projects/esp-dev-kits/en/latest/esp32/esp32-devkitc/user_guide.html)). So the DevKit goes in with the **antenna toward the 3V3/GND end and the USB toward 5V/CLK**, J2 under the left column. Nothing mechanical stops you from inserting it rotated 180°. If you do, 5V lands on the DevKit's GND and every label is wrong. Each side has two socket rows because these adapters accept both 0.9" and 1.0" wide boards ([Amazon listing](https://www.amazon.com/Breakout-Terminal-Expansion-ESP-WROOM-32-ESP32-DevKitC/dp/B0BYS6THLF)). A board fits only one pair. The realistic mistake is a row shifted one pin lengthwise, so check that each side has exactly 19 pins seated and none left over.

**Terminals drift away from sockets.** The terminals use 3.5 mm pitch (3.81 mm and 3.96 mm on some variants), while the sockets are 2.54 mm ([DIYables](https://diyables.io/products/screw-terminal-adapter-for-38-pin-esp32-board)). Across 18 gaps that is about 63 mm against 46 mm, so a mid-board label sits one to three socket positions away from the socket it is wired to. Each label belongs to its screw, and traces fan out to the correct socket. The spare socket row is **not** a labelled breakout. If you push a jumper into the socket that looks as if it lines up with "P13", it can land on IO12, GND or D2. That is the most likely cause of your boot loop.

## Six flash pins and P12 explain the 0xffffffff boot loop

ESP-IDF says GPIO6 to GPIO11 "are usually connected to the SPI flash… and therefore should not be used for other purposes" ([ESP-IDF GPIO](https://docs.espressif.com/projects/esp-idf/en/stable/esp32/api-reference/peripherals/gpio.html)). esptool warns that "flashing will usually fail completely if these pins are connected incorrectly" ([esptool troubleshooting](https://docs.espressif.com/projects/esptool/en/latest/esp32/troubleshooting.html)). The `invalid header: 0xffffffff` message is the ROM reporting all-ones, meaning blank or unreadable flash ([esp-idf #9005](https://github.com/espressif/esp-idf/issues/9005)).

The second route to the same symptom is **GPIO12 (MTDI)**. It is a strapping pin: when high at reset it switches VDD_SDIO to 1.8 V ([ESP32 datasheet §3.2](https://documentation.espressif.com/esp32_datasheet_en.pdf)). With the 3.3 V flash on a WROOM-32, "it may prevent flashing or booting due to flash brownout" ([esptool boot-mode selection](https://docs.espressif.com/projects/esptool/en/latest/esp32/advanced-topics/boot-mode-selection.html)). A community case with a module output on GPIO12 boot-looped the same way ([ESPSomfy-RTS #34](https://github.com/cjkas/ESPSomfy-RTS/issues/34)). The permanent fix is `espefuse set-flash-voltage 3.3V`, which removes GPIO12 as a strapping pin. It cannot be undone and is wrong for 1.8 V-flash modules ([ESP-IDF](https://docs.espressif.com/projects/esp-idf/en/stable/esp32/api-reference/peripherals/sd_pullup_requirements.html)). You don't need it if P12 stays empty. No Espressif document says that loading GPIO6 to GPIO11 prints exactly `0xffffffff`; that link comes from community reports and inference.

The other strapping pins matter less. GPIO0 low at reset forces download mode, and GPIO2 must be low or floating while flashing. **GPIO15 low at reset only silences the ROM boot log**; flash boot still works ([datasheet §3.3](https://documentation.espressif.com/esp32_datasheet_en.pdf)). The later **RX garbage** is less well documented. GPIO1 and GPIO3 carry the console and flashing link ([ESP-IDF GPIO](https://docs.espressif.com/projects/esp-idf/en/stable/esp32/api-reference/peripherals/gpio.html)), and the CP2102 already drives GPIO3. Any wire landing on RX, whether a display clock, a floating jumper or a mis-seated pin, will fight the CP2102 or pick up noise. No source describes this exact symptom, but it is the obvious reading. Keep TX and RX empty.

| Terminal | GPIO | Rule |
|---|---|---|
| SD0, SD1, SD2, SD3, CND, CLK | 7, 8, 9, 10, 11, 6 | Never connect: live flash bus |
| P12 | 12 | Leave empty: high at reset browns out flash |
| TX, RX | 1, 3 | Leave empty: USB console and flashing |
| P0 | 0 | Boot button only |
| P2 | 2 | Nothing that pulls it high |
| P15, P5 | 15, 5 | OK if nothing holds them low at reset (only affects boot log and SDIO timing) |
| SVP, SVN, P34, P35 | 36, 39, 34, 35 | Input only, no pulls |

## The SWIFT-LCD-20 is a documented NULLLAB board with fixed tie-offs

NULLLAB sells the module (Amazon [B0GVF8R5ZL](https://www.amazon.com/NULLLAB-Interface-Compatible-Embedded-Projects/dp/B0GVF8R5ZL)) and publishes a README, schematic, dimension drawing and ESP32 demos at [nulllaborg/swift-lcd](https://github.com/nulllaborg/swift-lcd). The schematic's title block says **Emakefun, SWIFT-LCD-13, Rev V0.1**. It was drawn for the 1.3" sister board, but the README gives both boards the same pinout, supply range and tie-off notes ([schematic](https://github.com/nulllaborg/swift-lcd/blob/main/picture/schematic_diagram.png)). The specs are **3.3 to 5 V supply, 80 mA, 56 × 40 mm board, IPS panel, ST7789** ([README](https://raw.githubusercontent.com/nulllaborg/swift-lcd/main/README.md)).

The connector J1 runs **1 GND, 2 VIN, 3 SCLK, 4 SDA, 5 DC, 6 CS**. The same six signals also appear on a 0.1" through-hole row and a 2×3 pad block ([schematic](https://github.com/nulllaborg/swift-lcd/blob/main/picture/schematic_diagram.png)). The README calls the connector GH1.25 and the cable "GH1.25 to PH2.0". The Amazon text says the cable is GH1.25 to Dupont ([Amazon](https://www.amazon.com/NULLLAB-Interface-Compatible-Embedded-Projects/dp/B0H2Y83TYG)), so check what came in your box. SDA is write-only MOSI, so you don't need MISO.

Power goes through a **662K (XC6206P332MR) 3.3 V LDO** rated for 6 V maximum input ([Sunrom](https://www.sunrom.com/p/xc6206p332mr-662k)). The SPI, DC and CS lines connect **directly to the ST7789 with no level shifting**, and that chip's logic inputs are rated to VDDI + 0.5 V ([ST7789V datasheet](https://newhavendisplay.com/content/datasheets/ST7789V.pdf)). "3.3–5 V compatible" therefore applies to the supply pin only. ESP32 3.3 V logic is correct. Feeding V from 5V, as the vendor example does, gives the LDO headroom. Feeding it from 3V3 also works but leaves the panel about 0.1 to 0.25 V low.

**Reset** is a resistor pull-up to 3V3 with no RC network. **Backlight** is a P-MOSFET (AO3401A) whose gate is tied to GND through a 0 Ω resistor, so it is always on at full brightness and cannot be dimmed without rework ([schematic](https://github.com/nulllaborg/swift-lcd/blob/main/picture/schematic_diagram.png)). The driver therefore has to send SWRESET (0x01) and wait at least 5 ms, and wait 120 ms before SLPOUT ([ST7789V §9.1.2](https://newhavendisplay.com/content/datasheets/ST7789V.pdf)). **SPI mode:** the ST7789 samples SDA on the rising clock edge, and with a real CS line "SCL can be high or low" when CS falls. That means **mode 0 and mode 3 both work** ([ST7789V §8.4](https://newhavendisplay.com/content/datasheets/ST7789V.pdf)). The vendor demos use mode 0. **Clock:** the datasheet's minimum write cycle of 66 ns works out to about 15 MHz. Higher speeds usually work but are out of spec. **Driver settings:** use 240×320 with offsets 0,0, inversion ON, and RGB order. The vendor's own demo uses exactly this: `Arduino_ST7789(bus, -1, 0, true, 240, 320, 0, 0, 0, 0)` ([vendor demo](https://github.com/nulllaborg/swift-lcd/releases/download/V1.0.0/swift_lcd_20_display_time.zip)).

Your `lib/lumosair/st7789.py` already matches. It sends SWRESET with 150 ms, SLPOUT with 120 ms, INVON, and MADCTL 0x60 for landscape without the BGR bit, and uses `rst=None, bl=None`. The polarity=1/phase=1 setting is fine. If you see garbage pixels at 30 MHz, the fix is to drop to 20 MHz or lower, not to change mode. The docstring says "VCC -> 3V3". That works, but 5V gives the LDO more margin.

## The pigtail colours are probably right, and you still need to meter them

No source publishes a colour table for this cable. The Amazon listing gives only the signal set G, V, SCL, SDA, DC, CS ([Amazon](https://www.amazon.com/NULLLAB-Interface-Compatible-Embedded-Projects/dp/B0GVF8R5ZL)). Your photographed order (CS, DC, SDA, SCL, V, G) is the schematic's J1 read from pin 6 back to pin 1. That makes **red = CS, black = DC, yellow = SDA, green = SCL, blue = V, white = G** consistent with the board. The colour sequence looks like a generic rainbow kit (red, black, yellow, white, blue, green) inserted in stock order, not colours chosen per signal ([GH1.25 kit](https://www.amazon.com/Teansic-Connector-Temperature-pre-Crimped-Controller/dp/B0FHGN5Y22)). Colour conventions differ everywhere: Pololu puts black on pin 1 and red on pin 2 ([Pololu](https://www.pololu.com/product/5546)), Grove puts red on pin 3 ([Seeed](https://wiki.seeedstudio.com/Grove_System/)), and Qwiic puts red on pin 2 ([SparkFun](https://www.sparkfun.com/qwiic)).

The practical danger is habit. **Red and black are signals here, not power.** Wiring red to 3V3 and black to GND would back-power the panel through its CS input's protection diodes, and a GPIO would then be asked to supply the 80 mA module ([Hackaday on ESD diodes](https://hackaday.com/2025/06/19/hacker-tactic-esd-diodes/)). "Anti-reverse" keys only the GH end; the Dupont end has no keying.

## Recommended wiring for the current firmware

| Display pin | Pigtail colour (verify) | Adapter **screw terminal** | GPIO | Firmware |
|---|---|---|---|---|
| G | white | GND (left pin 14, or right pin 1/7) | — | — |
| V | blue | 5V (preferred) or 3V3 | — | — |
| SCL | green | **P14** (left pin 12) | 14 | SCK |
| SDA | yellow | **P13** (left pin 15) | 13 | MOSI |
| DC | black | **P27** (left pin 11) | 27 | DC |
| CS | red | **P15** (right pin 16) | 15 | CS |

Every signal except CS is on the left column, next to P12 (between P14 and GND) and just above SD2/SD3/CND. Those are the neighbours a one-slot slip lands on. An optional 10 kΩ pull-up from CS to 3V3 keeps the panel deselected, and the ROM log visible, while the ESP32 is in reset. MicroPython's HSPI (SPI id 1) may claim GPIO12 as MISO by default when you don't pass one. That is harmless as long as nothing is wired to P12. The notes did not verify it, so don't rely on P12 being free for anything else.

**Pre-power checklist**

| # | Check | Pass criterion |
|---|---|---|
| 1 | DevKit orientation | Antenna at 3V3/GND end, USB at 5V/CLK end, J2 (3V3…5V) under left column |
| 2 | Seating | 19 pins per side fully seated, no spare socket at either end of the used row |
| 3 | Nothing in header sockets | Every external wire goes into a **screw terminal**; sockets hold only the DevKit |
| 4 | Forbidden terminals empty | SD0–SD3, CND, CLK, P12, TX, RX, P0, P2 have nothing attached |
| 5 | Pigtail continuity (unpowered, cable plugged into module) | Each Dupont socket beeps to its labelled pad; blue = V, white = G; no two wires beep to each other |
| 6 | Module supply not shorted | Resistance V–G on the module clearly above 0 Ω |
| 7 | Mark power | Tape or heat-shrink on blue (V) and white (G) Dupont ends |
| 8 | USB-only power test, display disconnected | Meter reads 3.3 V at 3V3–GND terminals and about 5 V (less a diode drop) at 5V–GND |
| 9 | Don't double-feed | No bench supply on 5V/3V3 while USB is connected |
| 10 | First light | Connect display and power up. The ROM boot log should appear and the display should initialise. If it boot-loops, unplug the display wires one at a time and re-meter them against the terminals |

## Conclusion

The labels were never the problem. The adapter breaks the one-to-one link between screw position and socket position, and the spare socket rows look like a breakout but are not one. That makes it easy to put a display wire on the flash bus or on GPIO12 while believing it sits on P13 or P14. Both faults produce exactly the blank-flash boot loop you saw. Treat the header sockets as belonging to the DevKit alone and you remove that whole class of fault. The display side carries less risk. The vendor's own schematic and demo code match your driver's reset-free init, inversion and RGB settings, and your pin choice avoids every hazardous strap. The one thing still unconfirmed is the cable itself: a two-minute continuity check replaces an inference from a photo with a measurement, and it guards against the "red means power" reflex that this pigtail would punish.

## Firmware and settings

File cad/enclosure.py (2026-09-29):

"""
LumosAir sensor-node enclosure — parametric fitment model (stacked two-board design).

    pip install cadquery
    python cad/enclosure.py                      # laser box, auto-chooses the enclosure
    python cad/enclosure.py --populate fan
    python cad/enclosure.py --box F --mcu module # force a size / a soldered ESP32 module
    python cad/enclosure.py --compare            # table of which boxes fit

How it is arranged, bottom to top:

    floor ── standoffs ── PCB-A (all the parts that need hoses, ports facing UP)
                              │  silicone tubes arc over to the bulkheads
          ── spacers ──── PCB-B (ESP32 + display hat, read through the clear lid)

Every hose is modelled as a real tube from the sensor port to its bulkhead, so the
report can check the bend radius and whether PCB-B would crush anything.

Outputs land in cad/out/. All dimensions are millimetres, measured from the INSIDE
floor at the inside back-left corner. Part sizes come from docs/datasheets/.
"""

from __future__ import annotations

import argparse
import math
import sys
from dataclasses import dataclass, field
from pathlib import Path

import cadquery as cq

# ======================================================================================
# Enclosures — Hammond 1554 family, clear polycarbonate lid ("2GYCL")
# Only the H size has a confirmed drawing (docs/datasheets/Hammond_1554H2GYCL_drawing.pdf);
# the others use the same wall/flange offsets, so treat their insides as ±1 mm.
# ======================================================================================
WALL = 3.0
LID_T = 3.0
CORNER_BOSS_R = 7.0
RIB_H = 6.0                      # moulded ribs along the inside walls


@dataclass(frozen=True)
class Box:
    code: str
    out: tuple[float, float, float]

    @property
    def inside(self) -> tuple[float, float, float]:
        return (self.out[0] - 7.09, self.out[1] - 11.09, self.out[2] - 6.0)


BOXES = {
    "F": Box("1554F2GYCL", (120.0, 90.0, 60.5)),
    "G": Box("1554G2GYCL", (120.0, 90.0, 80.5)),
    "J": Box("1554J2GYCL", (160.0, 90.0, 60.5)),
    "H": Box("1554H2GYCL", (180.0, 120.0, 60.5)),
}

# ======================================================================================
# Bulkhead pattern — identical on both boxes; one row if the wall is wide enough
# ======================================================================================
N_PORTS = 8
PORT_DIA = 8.0                   # panel hole for a 1/8" barbed bulkhead union
PORT_PITCH_1ROW = 18.0           # one row of 8, if the wall is wide enough
PORT_PITCH_2ROW = 22.0           # otherwise two rows of 4
PORT_EDGE_KEEPOUT = 11.0         # corner bosses + nut clearance
USE_ONE_ROW = False              # see one_row()

# Where the rows sit depends on how the hose leaves the sensor.
#   "straight" — the hose goes onto the sensor barb and leaves pointing UP. To turn
#                into a wall port without kinking it needs a full bend radius of
#                height, so the ports have to be high and the box has to be tall.
#   "elbow"    — a push-on 90 deg barbed elbow turns the hose at the sensor, so it
#                leaves pointing at the wall and the run is almost straight.
PORT_Z = {"elbow": {1: 22.0, 2: (13.0, 27.0)},
          "straight": {1: 38.0, 2: (16.0, 38.0)}}
ELBOW_ARM = 12.0                 # how far the elbow outlet sits in front of the barb
ELBOW_RISE = 4.0                 # outlet centreline, below the barb tip
BULK_HEX_AF = 11.0               # across flats, outside the wall
BULK_BARB_LEN = 12.0             # barb length each side
HOSE_ZONE = 22.0                 # free depth between the bulkhead barbs and PCB-A
# Two USB-C panel couplers (MECCANIXITY "D-type", 31 x 26 mm flange), one per end wall:
#   left  — 5 V POWER in, from a USB supply
#   right — FAN (UIS), the AC Infinity fan lead; only the fan box uses it
# UIS is USB-C shaped but is not USB, and a standard USB-C cable does not work between
# the fan and its controller, so check the fan still answers its controller through a
# coupler before relying on one. Same connector both ends: the engraving tells them
# apart. There is no switch on the box; power is switched at the supply.
# Cutout is the standard D-series one (Ø24 mm + two M3 on the diagonal); measure the
# part before drilling.
USBC_HOLE = 24.0
USBC_SCREW_DIA = 3.2
USBC_SCREWS = ((9.5, 12.0), (-9.5, -12.0))   # (along the wall, up) from the hole centre
USBC_FLANGE = (26.0, 31.0)                   # width along the wall x height
USBC_BODY = (34.0, 22.0, 24.0)               # behind the wall, incl. the plug inside
USBC_Y = 20.0                                # both couplers, same place on each end wall
USBC_Z = 28.0

# ======================================================================================
# Parts (sizes from the datasheets)
# ======================================================================================
SDP_BODY = (29.0, 18.0, 10.25)          # SDP81x, tube version
SDP_BARB_DIA, SDP_BARB_LEN, SDP_BARB_PITCH = 5.2, 9.65, 12.6
XGZP_SENSOR = (11.0, 10.8, 9.61)        # soldered straight to PCB-A, no carrier board
XGZP_PORT_PITCH = 6.19
MUX = (8.0, 6.5, 1.2)                   # TCA9548A, TSSOP-24
BME = (4.0, 4.0, 1.2)                   # BME280 LGA, with keep-out
PCB_T = 1.6
DISPLAY_PCB = (56.0, 40.0, 1.6)         # NULLLAB 2.0" ST7789 240x320
DISPLAY_GLASS = (49.0, 33.0, 2.6)       # LCD stack above the display PCB
DEVKIT = (55.0, 28.0, 13.0)             # ESP32-WROOM-32 DevKit in a socket strip
MODULE = (18.0, 25.5, 3.1)              # bare ESP32-WROOM-32E soldered to PCB-B

PCB_A_STANDOFF = 4.0                    # floor to PCB-A underside (nothing hangs below it)
TUBE_OD = 8.0                           # 3/16" ID silicone, ~1.5 mm wall
TUBE_MIN_BEND_R = 12.0                  # don't kink it
DISPLAY_STANDOFF = 6.0                  # PCB-B top to display underside (min; raised to clear the MCU)


@dataclass
class Part:
    name: str
    size: tuple[float, float, float]
    pos: tuple[float, float, float]
    color: tuple[float, float, float] = (0.4, 0.5, 0.6)
    note: str = ""

    @property
    def x2(self): return self.pos[0] + self.size[0]
    @property
    def y2(self): return self.pos[1] + self.size[1]
    @property
    def z2(self): return self.pos[2] + self.size[2]

    def solid(self) -> cq.Workplane:
        return cq.Workplane("XY").box(*self.size, centered=False).translate(self.pos)


@dataclass
class Tube:
    """One hose: sensor port -> bulkhead, as a polyline the report can measure."""
    label: str
    points: list[tuple[float, float, float]]
    radius: float = TUBE_OD / 2

    def length(self) -> float:
        return sum(_dist(a, b) for a, b in zip(self.points, self.points[1:]))

    def min_bend_radius(self) -> float:
        best = math.inf
        for a, b, c in zip(self.points, self.points[1:], self.points[2:]):
            best = min(best, _circumradius(a, b, c))
        return best

    def top(self) -> float:
        return max(p[2] for p in self.points) + self.radius

    def solid(self, step: int = 4) -> cq.Workplane:
        # A compound of short cylinders, not a boolean union: building it this way is
        # a few hundred times faster than fusing the segments, and keeps the STEP
        # small. The path is measured at full resolution and only drawn decimated.
        pts = self.points[::step]
        if pts[-1] != self.points[-1]:
            pts.append(self.points[-1])
        segs = []
        for a, b in zip(pts, pts[1:]):
            v = cq.Vector(*b) - cq.Vector(*a)
            if v.Length > 1e-6:
                segs.append(cq.Solid.makeCylinder(self.radius, v.Length, cq.Vector(*a), v))
        return cq.Workplane("XY").add(cq.Compound.makeCompound(segs))


@dataclass
class Design:
    box: Box
    populate: str
    mcu: str
    parts: list[Part] = field(default_factory=list)
    tubes: list[Tube] = field(default_factory=list)
    pcb_b_z: float = 0.0
    fittings: str = "elbow"
    display_standoff: float = DISPLAY_STANDOFF
    port_labels: list[tuple[float, float, str]] = field(default_factory=list)   # x, z, label


# ======================================================================================
# helpers
# ======================================================================================
def _dist(a, b) -> float:
    return math.sqrt(sum((x - y) ** 2 for x, y in zip(a, b)))


def _circumradius(a, b, c) -> float:
    ab, bc, ca = _dist(a, b), _dist(b, c), _dist(c, a)
    s = (ab + bc + ca) / 2
    area2 = s * (s - ab) * (s - bc) * (s - ca)
    if area2 <= 1e-12:
        return math.inf
    return ab * bc * ca / (4 * math.sqrt(area2))


def _cyl_between(a, b, r) -> cq.Workplane:
    start = cq.Vector(*a)
    v = cq.Vector(*b) - start
    if v.Length < 1e-6:
        return cq.Workplane("XY").sphere(r).translate(a)
    return cq.Workplane("XY").add(cq.Solid.makeCylinder(r, v.Length, start, v))


_cylinder = _cyl_between


def bezier3(p0, p1, p2, p3, n=48) -> list[tuple[float, float, float]]:
    """Cubic Bezier, sampled."""
    out = []
    for i in range(n + 1):
        t = i / n
        u = 1 - t
        out.append(tuple(u ** 3 * a + 3 * u * u * t * b + 3 * u * t * t * c + t ** 3 * dd
                         for a, b, c, dd in zip(p0, p1, p2, p3)))
    return out


def route_tube(start, start_dir, end, lift_range=range(4, 31, 2), pull_range=range(4, 31, 2)):
    """A hose leaving a sensor along start_dir and arriving at a bulkhead along -Y.

    Tries a family of cubic Beziers: anything that clears the minimum bend radius
    wins on lowest apex (height is what decides the box); if nothing clears it, the
    roundest route wins so the report can say how short it falls.
    """
    n = math.sqrt(sum(c * c for c in start_dir))
    u = tuple(c / n for c in start_dir)
    best = None
    for lift in lift_range:
        p1 = tuple(a + b * lift for a, b in zip(start, u))
        for pull in pull_range:
            p2 = (end[0], end[1] + pull, end[2])
            pts = bezier3(start, p1, p2, end)
            r = min((_circumradius(a, b, c)
                     for a, b, c in zip(pts, pts[1:], pts[2:])), default=math.inf)
            apex = max(p[2] for p in pts)
            ok = r >= TUBE_MIN_BEND_R
            key = (0, round(apex, 2), -r) if ok else (1, -r, round(apex, 2))
            if best is None or key < best[0]:
                best = (key, pts)
    return best[1]


# ======================================================================================
# geometry
# ======================================================================================
def one_row(box: Box) -> bool:
    """One row of 8 needs a wide wall AND makes every hose fan out sideways, which
    costs more bend radius than it saves. Kept behind a flag; two rows always win."""
    return (USE_ONE_ROW
            and (N_PORTS - 1) * PORT_PITCH_1ROW + 2 * PORT_EDGE_KEEPOUT <= box.inside[0])


def port_positions(box: Box, fittings: str = "elbow") -> list[tuple[float, float]]:
    """(x, z) of every bulkhead, row by row (row 0 lowest)."""
    inside_l = box.inside[0]
    if one_row(box):
        span = (N_PORTS - 1) * PORT_PITCH_1ROW
        x0 = (inside_l - span) / 2
        return [(x0 + i * PORT_PITCH_1ROW, PORT_Z[fittings][1]) for i in range(N_PORTS)]
    cols, rows = N_PORTS // 2, PORT_Z[fittings][2]
    span = (cols - 1) * PORT_PITCH_2ROW
    x0 = (inside_l - span) / 2
    return [(x0 + c * PORT_PITCH_2ROW, rows[r]) for r in range(2) for c in range(cols)]


def assign_ports(exits, slots) -> list[int]:
    """Which bulkhead each sensor uses. Exhaustive — there are only 8 holes.

    Cost is the squared sideways + vertical offset the hose has to absorb; the
    depth of the box is fixed, so that is what sets how hard each bend is.
    """
    import itertools
    best, best_cost = None, math.inf
    for perm in itertools.permutations(range(len(slots)), len(exits)):
        cost = sum((e[0] - slots[i][0]) ** 2 + 1.6 * (e[2] - slots[i][1]) ** 2
                   for e, i in zip(exits, perm))
        if cost < best_cost:
            best, best_cost = perm, cost
    return list(best)


def usbc_cutout(x_wall: float, outward: float) -> cq.Workplane:
    """Ø24 hole + two M3 screw holes through an end wall at x_wall (outward = -1 left, +1 right)."""
    depth = WALL + 4
    cut = None
    for dy, dz in ((0.0, 0.0),) + USBC_SCREWS:
        d = USBC_HOLE if (dy, dz) == (0.0, 0.0) else USBC_SCREW_DIA
        c = (cq.Workplane("YZ").circle(d / 2).extrude(outward * depth)
             .translate((x_wall - outward * 2.0, USBC_Y + dy, USBC_Z + dz)))
        cut = c if cut is None else cut.union(c)
    return cut


def box_shell(box: Box, fittings: str = "elbow") -> cq.Workplane:
    il, iw, ih = box.inside
    outer = (cq.Workplane("XY").box(*box.out, centered=False)
             .translate((-(box.out[0] - il) / 2, -(box.out[1] - iw) / 2, -WALL)))
    shell = outer.cut(cq.Workplane("XY").box(il, iw, ih + WALL, centered=False))

    for x, y in ((0, 0), (il, 0), (0, iw), (il, iw)):
        boss = cq.Workplane("XY").circle(CORNER_BOSS_R).extrude(ih).translate((x, y, 0))
        shell = shell.union(boss.intersect(cq.Workplane("XY").box(il, iw, ih, centered=False)))

    for (x, z) in port_positions(box, fittings):            # bulkheads through the front wall
        shell = shell.cut(cq.Workplane("XZ").circle(PORT_DIA / 2).extrude(WALL + 4)
                          .translate((x, 2.0, z)))
    # USB-C couplers: 5 V POWER in the left end wall, FAN (UIS) in the right
    shell = shell.cut(usbc_cutout(0.0, -1)).cut(usbc_cutout(il, +1))
    return shell


def bulkhead(box: Box, x: float, z: float) -> cq.Workplane:
    """Barbed bulkhead union: hex outside, barbs both sides."""
    y_wall = -WALL
    body = (cq.Workplane("XZ", origin=(x, y_wall - 3.0, z)).polygon(6, BULK_HEX_AF / math.cos(math.pi / 6))
            .extrude(6.0))
    inner = _cyl_between((x, 0.0, z), (x, BULK_BARB_LEN, z), 2.6)
    outer = _cyl_between((x, y_wall - 3.0, z), (x, y_wall - 3.0 - BULK_BARB_LEN, z), 2.6)
    return body.union(inner).union(outer)


def bulkhead_inner_end(x: float, z: float) -> tuple[float, float, float]:
    return (x, BULK_BARB_LEN, z)


# ======================================================================================
# the stack
# ======================================================================================
def build(populate: str, box_code: str, mcu: str, fittings: str = "elbow") -> Design:
    box = BOXES[box_code]
    il, iw, ih = box.inside
    d = Design(box=box, populate=populate, mcu=mcu, fittings=fittings)

    # ---------------- PCB-A: everything that needs a hose ----------------
    # It sits BACK from the port wall: the strip in front of it is the hose zone,
    # which is what lets each tube make a real 12 mm bend into its bulkhead.
    pa_y = BULK_BARB_LEN + HOSE_ZONE
    pa_w, pa_d = il - 8.0, iw - pa_y - 4.0
    pa_x = (il - pa_w) / 2
    d.parts.append(Part("PCB-A (sensor board)", (pa_w, pa_d, PCB_T), (pa_x, pa_y, PCB_A_STANDOFF),
                        (0.08, 0.32, 0.14), f"screws to the floor on {PCB_A_STANDOFF:.0f} mm standoffs"))
    a_top = PCB_A_STANDOFF + PCB_T
    for sx, sy in ((pa_x + 3, pa_y + 3), (pa_x + pa_w - 3, pa_y + 3),
                   (pa_x + 3, pa_y + pa_d - 3), (pa_x + pa_w - 3, pa_y + pa_d - 3)):
        d.parts.append(Part("standoff", (3.0, 3.0, PCB_A_STANDOFF), (sx - 1.5, sy - 1.5, 0.0),
                            (0.75, 0.7, 0.4)))

    ports: list[tuple[str, tuple[float, float, float]]] = []     # label -> port top, facing up

    # Sensors line up with the port columns: each SDP810 is turned 90 deg so its two
    # barbs are one behind the other at the SAME x as a column of bulkheads, which is
    # what keeps the hoses nearly straight.
    # A two-row wall has four columns of two, so one sensor sits behind one column.
    # A one-row wall spreads the eight holes out, so a two-port sensor straddles the
    # pair of holes it feeds.
    xs = sorted({x for x, _ in port_positions(box, fittings)})
    if one_row(box):
        cols = [(xs[2 * k] + xs[2 * k + 1]) / 2 for k in range(len(xs) // 2)]
    else:
        cols = xs
    sdp = (SDP_BODY[1], SDP_BODY[0], SDP_BODY[2])          # turned 90 deg

    def add_sdp(name, col, labels):
        cx = cols[col]
        bx, by = cx - sdp[0] / 2, pa_y + 3
        d.parts.append(Part(f"SDP810 {name}", sdp, (bx, by, a_top), (0.85, 0.85, 0.88),
                            "turned 90 deg; tube ports face up"))
        cy = by + sdp[1] / 2
        for sign, lab in zip((-1, 1), labels):
            p = (cx, cy + sign * SDP_BARB_PITCH / 2, a_top + sdp[2] + SDP_BARB_LEN)
            d.parts.append(Part(f"barb {name}{sign:+d}", (SDP_BARB_DIA, SDP_BARB_DIA, SDP_BARB_LEN),
                                (p[0] - SDP_BARB_DIA / 2, p[1] - SDP_BARB_DIA / 2,
                                 a_top + sdp[2]), (0.93, 0.78, 0.2)))
            if lab:
                ports.append((lab, p))

    def add_xgzp(name, col, lab, row):
        sx = cols[col] - XGZP_SENSOR[0] / 2
        sy = pa_y + 4 + row * (XGZP_SENSOR[1] + 8)
        d.parts.append(Part(f"XGZP {name} sensor", XGZP_SENSOR, (sx, sy, a_top),
                            (0.3, 0.3, 0.35), "soldered to PCB-A; port faces up"))
        ports.append((lab, (cols[col], sy + XGZP_SENSOR[1] / 2, a_top + XGZP_SENSOR[2])))

    if populate == "laser":
        add_sdp("cyc_dp", 0, ("CYC +", "CYC −"))
        add_sdp("pitot", 1, ("PITOT T", "PITOT S"))
        add_sdp("encl", 2, (None, "ENCL"))
        add_xgzp("bin", 3, "BIN", 0)
        add_xgzp("run_in", 3, "RUN", 1)
    else:
        add_xgzp("fan_in", 0, "FAN IN", 0)

    # ---------------- hoses: sensor port -> bulkhead ----------------
    # With elbows the hose leaves pointing at the wall; without them, straight up.
    # The holes are identical on both boxes, but WHICH hole a sensor uses is free,
    # so pick the assignment with the least sideways and vertical offset — that is
    # what decides whether the hoses bend gently or kink.
    slot_xz = port_positions(box, fittings)
    exits = [(lab, (p[0], p[1] - ELBOW_ARM, p[2] - ELBOW_RISE) if fittings == "elbow" else p)
             for lab, p in ports]
    order = assign_ports([e[1] for e in exits], slot_xz)
    slots = {lab: slot_xz[i] for (lab, _), i in zip(exits, order)}
    used = set(order)
    vent = next(i for i in range(len(slot_xz)) if i not in used)
    wall_labels = ["PLUG"] * len(slot_xz)
    for (lab, _), i in zip(exits, order):
        wall_labels[i] = lab
    wall_labels[vent] = "VENT"
    labels = wall_labels

    for lab, p in ports:
        x, z = slots[lab]
        if fittings == "elbow":
            d.parts.append(Part(f"elbow {lab}", (SDP_BARB_DIA + 2, ELBOW_ARM, SDP_BARB_DIA + 2),
                                (p[0] - (SDP_BARB_DIA + 2) / 2, p[1] - ELBOW_ARM,
                                 p[2] - ELBOW_RISE - (SDP_BARB_DIA + 2) / 2),
                                (0.93, 0.78, 0.2), "push-on 90 deg barbed elbow"))
            start, sdir = (p[0], p[1] - ELBOW_ARM, p[2] - ELBOW_RISE), (0.0, -1.0, 0.0)
        else:
            start, sdir = p, (0.0, 0.0, 1.0)
        d.tubes.append(Tube(lab, route_tube(start, sdir, bulkhead_inner_end(x, z))))

    # ---------------- PCB-B: processor + display hat ----------------
    tube_top = max([t.top() for t in d.tubes], default=a_top)
    sensor_top = max(p.z2 for p in d.parts)
    pcb_b_z = max(tube_top, sensor_top) + 3.0
    d.pcb_b_z = pcb_b_z
    # PCB-B shares PCB-A's outline, so the spacers are a straight vertical stack
    pb_w, pb_d, pb_x, pb_y = pa_w, pa_d, pa_x, pa_y
    d.parts.append(Part("PCB-B (processor + display hat)", (pb_w, pb_d, PCB_T), (pb_x, pb_y, pcb_b_z),
                        (0.10, 0.12, 0.32), "spacers up from PCB-A; display on top"))
    for sx, sy in ((pb_x + 3, pb_y + 3), (pb_x + pb_w - 3, pb_y + 3),
                   (pb_x + 3, pb_y + pb_d - 3), (pb_x + pb_w - 3, pb_y + pb_d - 3)):
        d.parts.append(Part("spacer", (3.0, 3.0, pcb_b_z - PCB_A_STANDOFF - PCB_T),
                            (sx - 1.5, sy - 1.5, PCB_A_STANDOFF + PCB_T), (0.75, 0.7, 0.4)))
    b_top = pcb_b_z + PCB_T

    # The display takes almost the whole depth of PCB-B, so everything else lives in
    # the strip beside it — or, if the MCU is too wide for that, underneath it.
    msz = DEVKIT if mcu == "devkit" else MODULE
    dx, dy = pb_x + 4.0, pb_y + (pb_d - DISPLAY_PCB[1]) / 2
    strip_x, strip_w = dx + DISPLAY_PCB[0] + 3.0, pb_x + pb_w - 3.0 - (dx + DISPLAY_PCB[0] + 3.0)
    side_by_side = msz[0] + 3.0 + MUX[0] <= strip_w        # MCU, then mux and BME
    if side_by_side:
        mx0, my0 = strip_x, pb_y + 2.0
        free_x = strip_x + msz[0] + 3.0
    else:
        dx = pb_x + (pb_w - DISPLAY_PCB[0]) / 2            # MCU tucks under the display
        mx0, my0 = dx + (DISPLAY_PCB[0] - msz[0]) / 2, pb_y + (pb_d - msz[1]) / 2
        strip_x = dx + DISPLAY_PCB[0] + 3.0
        free_x = strip_x
    d.parts.append(Part("ESP32 DevKit (socketed)" if mcu == "devkit" else "ESP32-WROOM-32E (soldered)",
                        msz, (mx0, my0, b_top), (0.15, 0.15, 0.2),
                        "beside the display" if side_by_side else "under the display"))
    # neither of these needs a hose, so they ride on PCB-B
    if populate == "laser":
        d.parts.append(Part("TCA9548A mux", MUX, (free_x, pb_y + 3.0, b_top),
                            (0.2, 0.5, 0.25), "I2C multiplexer — the sensors share one address"))
    d.parts.append(Part("BME280", BME, (free_x, pb_y + pb_d - BME[1] - 3.0, b_top),
                        (0.2, 0.5, 0.25), "box air: density correction"))
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

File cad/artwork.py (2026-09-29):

"""
1:1 artwork for the enclosure: panel markings to laser-engrave, and board outlines
for KiCad.

    python cad/artwork.py                 # both nodes, into cad/out/

Everything comes from the same parametric model as enclosure.py, so a moved port
moves its label, its hole and its PCB mounting hole together.

Written files
    panel_front_laser.svg / panel_front_fan.svg   front face, 1:1, mm
    panel_end_power.svg / panel_end_fan.svg       end walls: USB-C 5 V POWER (left), FAN (right)
    drill_template_front.svg                      holes only, for marking out
    pcb_a_outline.dxf / pcb_b_outline.dxf         board edge + mounting holes

The SVGs use two colours by convention:
    red   (#ff0000)  cut / drill — the holes themselves
    black (#000000)  engrave     — text, frames
Most laser software maps colour to operation, so import and assign.
"""

from __future__ import annotations

import argparse
import math
from pathlib import Path

import cadquery as cq
import enclosure as enc

MM = 1.0
CUT, ENGRAVE = "#ff0000", "#000000"


# ======================================================================================
# a very small SVG writer — 1 user unit = 1 mm
# ======================================================================================
class Svg:
    def __init__(self, w: float, h: float, title: str):
        self.w, self.h = w, h
        self.body: list[str] = []
        self.title = title

    def circle(self, x, y, r, stroke=CUT, w=0.15):
        self.body.append(f'<circle cx="{x:.3f}" cy="{y:.3f}" r="{r:.3f}" fill="none" '
                         f'stroke="{stroke}" stroke-width="{w}"/>')

    def rect(self, x, y, w, h, stroke=ENGRAVE, sw=0.2, rx=0.0):
        self.body.append(f'<rect x="{x:.3f}" y="{y:.3f}" width="{w:.3f}" height="{h:.3f}" '
                         f'rx="{rx:.2f}" fill="none" stroke="{stroke}" stroke-width="{sw}"/>')

    def line(self, x1, y1, x2, y2, stroke=ENGRAVE, sw=0.2):
        self.body.append(f'<line x1="{x1:.3f}" y1="{y1:.3f}" x2="{x2:.3f}" y2="{y2:.3f}" '
                         f'stroke="{stroke}" stroke-width="{sw}"/>')

    def arc(self, cx, cy, r, a0, a1, stroke=ENGRAVE, sw=0.3):
        x0, y0 = cx + r * math.cos(a0), cy + r * math.sin(a0)
        x1, y1 = cx + r * math.cos(a1), cy + r * math.sin(a1)
        large = 1 if abs(a1 - a0) > math.pi else 0
        self.body.append(f'<path d="M {x0:.3f} {y0:.3f} A {r:.3f} {r:.3f} 0 {large} 1 '
                         f'{x1:.3f} {y1:.3f}" fill="none" stroke="{stroke}" stroke-width="{sw}"/>')

    def text(self, x, y, s, size=3.0, anchor="middle", fill=ENGRAVE, weight="600"):
        s = (s.replace("&", "&amp;").replace("<", "&lt;").replace(">", "&gt;"))
        self.body.append(f'<text x="{x:.3f}" y="{y:.3f}" font-family="DejaVu Sans, Arial, '
                         f'sans-serif" font-size="{size:.2f}" font-weight="{weight}" '
                         f'text-anchor="{anchor}" fill="{fill}">{s}</text>')

    def save(self, path: Path):
        head = (f'<svg xmlns="http://www.w3.org/2000/svg" width="{self.w:.3f}mm" '
                f'height="{self.h:.3f}mm" viewBox="0 0 {self.w:.3f} {self.h:.3f}">\n'
                f'<title>{self.title}</title>\n')
        path.write_text(head + "\n".join(self.body) + "\n</svg>\n", encoding="utf-8")
        print("wrote", path)


# ======================================================================================
# panels
# ======================================================================================

def panel_front(populate: str, out: Path, box_code: str, mcu: str, fittings: str) -> None:
    """The face the hoses come through, 1:1, seen from outside."""
    d = enc.build(populate, box_code, mcu, fittings)
    box = d.box
    ol, _, oh = box.out
    il = box.inside[0]
    dx, dz = (ol - il) / 2, enc.WALL            # inside origin -> outside panel origin

    svg = Svg(ol, oh, f"LumosAir {populate} node — front panel")
    svg.rect(0.15, 0.15, ol - 0.3, oh - 0.3, ENGRAVE, 0.2, rx=3)

    # seen from outside, x mirrors
    def px(x_inside: float) -> float:
        return ol - (x_inside + dx)

    def py(z_inside: float) -> float:
        return oh - (z_inside + dz)

    # labels go outward from the middle of the panel so the two rows never collide
    zs = sorted({z for _, z, _ in d.port_labels})
    ring = enc.BULK_HEX_AF / 2 + 1.3
    for x, z, lab in d.port_labels:
        cx, cy = px(x), py(z)
        svg.circle(cx, cy, enc.PORT_DIA / 2)
        svg.circle(cx, cy, ring, "#9a9a9a", 0.15)                      # nut witness ring
        ty = cy - ring - 1.6 if z == max(zs) else cy + ring + 3.4
        svg.text(cx, ty, lab, size=2.8,
                 fill=ENGRAVE if lab != "PLUG" else "#9a9a9a")



    svg.text(ol - 6.0, 8.0, f"LumosAir · {populate} node", size=3.4, anchor="end")
    svg.save(out / f"panel_front_{populate}.svg")


def panel_end(side: str, out: Path, box_code: str, mcu: str, fittings: str) -> None:
    """An end wall with its USB-C coupler, 1:1, seen from outside.

    Both walls carry the same connector, so the engraving is what tells them apart:
    left = 5 V POWER from a USB supply, right = FAN, the AC Infinity UIS lead.
    """
    d = enc.build("laser", box_code, mcu, fittings)
    box = d.box
    _, ow, oh = box.out
    iw = box.inside[1]
    dy, dz = (ow - iw) / 2, enc.WALL
    label, sub, fname = {"power": ("5V POWER", "USB supply only", "panel_end_power.svg"),
                         "fan": ("FAN", "AC Infinity UIS - not USB", "panel_end_fan.svg")}[side]

    # Seen from outside, the left wall has the front of the box on the right, so y
    # mirrors there; the right wall reads the other way round.
    def px(y_inside: float) -> float:
        return ow - (y_inside + dy) if side == "power" else y_inside + dy

    svg = Svg(ow, oh, f"LumosAir — {'left' if side == 'power' else 'right'} end wall")
    svg.rect(0.15, 0.15, ow - 0.3, oh - 0.3, ENGRAVE, 0.2, rx=3)
    cx, cy = px(enc.USBC_Y), oh - (enc.USBC_Z + dz)
    svg.circle(cx, cy, enc.USBC_HOLE / 2)
    for sy_, sz_ in enc.USBC_SCREWS:
        svg.circle(px(enc.USBC_Y + sy_), oh - (enc.USBC_Z + sz_ + dz), enc.USBC_SCREW_DIA / 2)
    fw, fh = enc.USBC_FLANGE
    svg.rect(cx - fw / 2, cy - fh / 2, fw, fh, "#9a9a9a", 0.15, rx=2)       # flange witness
    tx = cx + fw / 2 + 4.0 if cx + fw / 2 + 30 < ow else cx - fw / 2 - 4.0
    anchor = "start" if tx > cx else "end"
    svg.text(tx, cy - 1.0, label, size=4.2, anchor=anchor)
    svg.text(tx, cy + 4.5, sub, size=2.4, anchor=anchor, weight="400")
    svg.save(out / fname)
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

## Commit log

2026-09-16 Initial commit: LumosAir exhaust airflow monitor
    ESP32 differential-pressure sensor firmware, .NET physics model and
    diagnostics engine, WPF monitor app with simulator, CLI, tests, and
    design docs explaining why the monitor is built before the separator.
    Claude-Session: https://claude.ai/code/session_01RmHCwUFzxLedq2a6PYLQZb
    [BOM.csv]
2026-09-21 Design rev 2: named pitot probe, rigid measuring spool, Option C, traverse
    - Pitot is now specified as a Dwyer 166-6-CF (Cp 1.000, 1/8" stem rated for 4" ducts).
    Documented its actual connection sizes (1/8" OD total, 1/4" OD static), the 1/8" FNPT
    mounting boss, and tubing adapters to the 3/16" ID system lines.
    - Made explicit that the run is 4"/6" flexible duct and only the 5 ft 4" measuring spool
    is rigid; renamed that element and noted flex friction sensitivity.
    - Replaced the single-diameter traverse with a two-axis six-point equal-area traverse
    (12 readings, second boss 90 deg away) and documented Cp vs profileFactor.
    - Added Option C: the system as it stands today with no separ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
    [1554H.3mf, 1554H.igs, 1554H.stp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]
2026-09-22 Identical boxes with a fitment model, MicroPython firmware with a display, and automatic fan control
    - cad/: parametric CadQuery model of the shared Hammond 1554H2GYCL enclosure.
    Both nodes get the same 6-port bulkhead pattern; the fan box plugs what it
    does not use. Generates STEP, STL, views, a 1:1 drill template and a clearance
    report (14.9 mm headroom, no collisions). The clear lid means the display
    needs no cut-out.
    - firmware/micropython/: replaces the Arduino C++ node. Drivers for SDP8xx,
    XGZP6897D, BME280 and the TCA9548A, an ST7789 display UI, UDP/MQTT, pull-OTA
    over wi-fi, and tools to serve updates and send commands. 31 host tests.
    - Each box now shows live detail: sta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
    [BOM.csv, BOM.xlsx, lumosair_enclosure_laser.step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]
2026-09-22 Stacked two-board enclosure: modelled hose runs, smaller box, panel artwork
    The box was oversized and how the hoses connected was never actually worked
    out. Both are now modelled rather than asserted.
    - PCB-A screws to the floor and carries every part that needs a hose (three
    SDP810s turned 90 deg, two XGZP6897Ds soldered direct, ports facing up).
    Spacers carry PCB-B above the hose zone with the ESP32, mux, BME280 and the
    display reading up through the clear lid.
    - Each hose is a real tube in the model, routed as a cubic Bezier leaving the
    sensor and arriving at its bulkhead, checked for bend radius and for
    clearance under PCB-B.
    - Push-on 90 deg barbed elbows turn each hose at th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
    [BOM.csv, lumosair_enclosure_laser.step, lumosair_enclosure_laser.stl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]
2026-09-22 Node simulator: render the box display on a PC, and fix the seven-segment digits
    There was no way to see the box screen without hardware. The desktop app's
    simulator fabricates telemetry in-process, so it never reaches the node code
    and never draws anything.
    tools/simulate_node.py runs the node on a PC. It is not a mock of the UI: it
    imports the real st7789 and display_ui and decodes the SPI command stream the
    driver emits (CASET / RASET / RAMWR) into a framebuffer, so the PNG is the
    panel pixel for pixel. Standard library only; the embedded 8x8 font stands in
    for MicroPython's built-in one at the same fixed cell size.
    python tools/simulate_node.py # 8 scenarios -> out/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
    [simulate_node.py, test_firmware.py]
2026-09-22 Fix a modal-dialog storm: non-finite numbers reaching the status broadcast
    Running the desktop app against the node simulator filled the desktop with
    "LumosAir error" dialogs - one per tick, each one modal - reading ".NET number
    values such as positive and negative infinity cannot be written as valid JSON".
    Three separate defects had to line up, and all three are now fixed.
    1. The model produces non-finite numbers on purpose. CycloneCutSize returns
    +infinity when the inlet velocity is zero (no flow, no separation -
    CycloneEfficiency explicitly tests for it), and FlowFromReading returns NaN
    when a tap's predicted signal is too small to invert. Both are reasonable
    sentinels insid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
    [simulate_node.py]
2026-09-22 Node simulator: emit readings the app can actually interpret
    Running both simulated nodes against the desktop app at fan level 10 made it
    report "Exhaust fan appears to be off". The app was right and the simulator was
    wrong, in three ways.
    1. Sign convention. SystemModel.PredictReading is explicit: the sensor's + port
    is on the room and its - port on the duct, so bin, run_in, encl and fan_in
    all read POSITIVE suction. The simulator sent them negative. FlowFromReading
    bails out with `if (reading / top <= 0) return 0`, so every one of those taps
    implied zero flow; the median of the tap-implied flows collapsed from
    {122.9, 0, 164.5, 0, 0} to 0, which satisfied both halves of the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
    [simulate_node.py]
2026-09-22 Honour the fan level set by hand when the node is not driving the fan
    Setting the fan level in the app did nothing once a fan node was on the air.
    CurrentFanLevel was `_reportedFanLevel ?? ManualFanLevel`, so any level a node
    reported won outright and silently discarded the one you picked.
    The node's level is only worth trusting when the node is actually driving the
    fan. With FAN_OUTPUT_ENABLED off - the default, until the CLOUDLINE UIS pinout
    is verified with a meter - it is echoing the last level it was told and has no
    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
2026-09-22 Fix stale digits on the box display: fan level 7 showed as 70
    Screen.fan() built its string with "%d", so it was one character for level 7 and
    two for level 10. seg7 clears only as wide as the string it is handed -
    (digit_w + gap) * len(s) - so going from 10 to 7 repainted the first cell and
    left the old second digit standing. The screen read 70. Dropping to no level at
    all was worse: "-" is one character, so 10 became -0.
    Both now use a fixed-width, right-aligned string, which is why flow() has never
    had the problem - it uses "%3d", and "---" for no reading is the same width.
    Four new host tests, and they check the glass rather than the call: each renders
    a sequence through the node simul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
    [test_firmware.py]
2026-09-22 Identical boxes: how a node works out which one it is, and a BOM that matches
    The two boxes are built and populated the same - same two PCBs, same three SDP810s,
    same two XGZP6897Ds, same firmware, same drill pattern. Only what you connect
    outside differs. A box is therefore a spare for either position and there is one
    spares list, which is the point.
    That has a consequence the docs did not cover: a node cannot tell what it is by
    scanning its own I2C bus, because every box has every sensor. DESIGN.md 6a now
    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
    [BOM.xlsx]
2026-09-22 Drop BOM.csv; the spreadsheet is the bill of materials now
    docs/BOM.xlsx carries everything the csv did and a good deal the csv could not:
    the sourcing state per line, part numbers, dimensions, datasheet and 3D-model
    links, per-item prices as formulas for things sold in packs, and the Deleted
    column recording what earlier design revisions retired. Two BOMs drift apart;
    one does not.
    README.md and DESIGN.md 5 now point at the spreadsheet.
    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
    [BOM.csv]
2026-09-25 Send the box status to each node directly, not only to 255.255.255.255
    Windows sends a limited broadcast out of one adapter, the lowest-metric one.
    On this PC that is Hyper-V's vEthernet (Default Switch), 172.17.160.1, so the
    status never reached the LAN and the real box sat on "NO PC" while the app ran.
    The app already learns every node's address from its telemetry: send the status
    there, and broadcast only until a node has been heard.
2026-09-25 First hardware bring-up: readable box screen, true colours, bench mode
    The laser node has now run on a real ESP32 with its display. What that found:
    - Colours: fill_rect sent each RGB565 pixel high byte first while framebuf sends
    low byte first, so on the panel the dark background was pink and the status
    band stopped where its text did. The simulator's framebuf stand-in and panel
    decoder made the same swap, which hid it; both now behave like the hardware,
    and three tests check that fills and text agree.
    - Legibility: 8 px text is 1 mm on a 2" panel. The screen now shows only what
    you act on: a scale-4 status word (or NO PC), 100 px CFM and fan level with an
    amber SET n when the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
    [simulate_node.py, test_firmware.py, upload.py]
2026-09-25 Research: terminal adapter, SWIFT-LCD-20 display and its pigtail
    Sourced verification written during bring-up: the adapter's labels match the
    DevKitC V4 pinout (CND is CMD/GPIO11), the display's pinout, power and driver
    settings from the maker's repo, and why the pigtail's colours can't be trusted.
2026-09-25 Second box on the bench: per-box configs, and bench mode for the fan node
    - config_laser.py / config_fan.py hold each box's settings, Wi-Fi password
    included. .gitignore now covers every config_*.py except the example.
    - tools/upload.py --config config_fan.py sends that file to the board as
    config.py, the only name main.py reads, and prints which NODE_ID it is.
    With several box configs and no --config it refuses rather than guess.
    - In bench mode the fan box follows its own fan level (set_level lands in
    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
2026-09-29 Enclosure and PCB-A work: CNC board files, schematic, Proteus project, box marking, demo videos, CAD updates
    [LumosAir node.3mf, lumosair_laser_F_module.step, lumosair_laser_F_module.stl]
2026-09-29 Add Blender node project: .blend files, render/compose scripts, textures, finished stills
    [Node - restored 2026-09-28.blend, Node - sensor bay backup 2026-09-29.blend, Node.blend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]
